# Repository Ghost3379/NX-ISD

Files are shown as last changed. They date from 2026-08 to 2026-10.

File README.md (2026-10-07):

# NX-ISD

## Overview
The **NX-ISD** is a custom, highly integrated wearable and embedded development board inspired by the Artemis Watch. It serves as the hardware foundation for the **ISD-Core** operating system.

<p align="center">
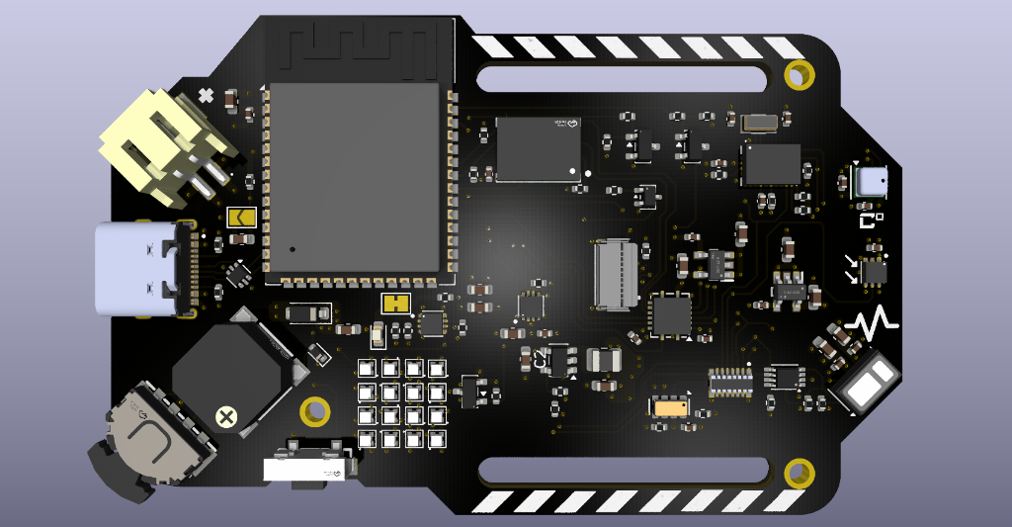
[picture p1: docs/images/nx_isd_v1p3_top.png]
NX-ISD v1p3 Top Component View
  
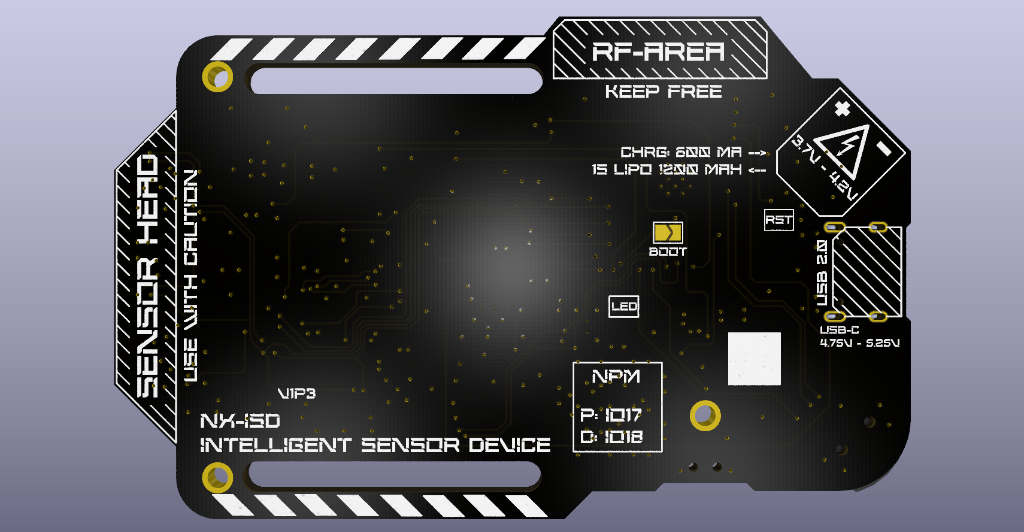
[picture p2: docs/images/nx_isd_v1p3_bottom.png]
NX-ISD v1p3 Bottom Silkscreen View
  
</p>
<p align="center">
  <em>NX-ISD Hardware Revision v1p3 (KiCad Raytraced 3D Render) — No Battery & No Display mounted</em>
</p>

## Naming & Structure

```text
N X - I S D
│     │
│     └─► Intelligent Sensor Device
│         (The hardware foundation)
│
└─► Prototyping Series
    (Always in development, not a closed product, open for everyone)

      │
      ▼
  ISD-Core
      │
      ├─► Custom Operating System (Dual-Core FreeRTOS based)
      ├─► Built on PlatformIO / Arduino Framework
      │
      ├──► NX-MSF: Mathematical Sensor Fusion (Physics Models & Kalman Filters)
      ├──► NX-AIS: Advanced Information System (Contextual Advisory Engine)
      └──► NX-SDS: Self-Diagnostic System (Hardware Integrity & Proof-Testing)
```

## Hardware Specifications

### Core & Storage
* **Microcontroller:** ESP32-S3 N16R8
* **Storage:** Additional Onboard NAND-SD (ZDSD02GLGEAG -> 2 Gbit = 250 MByte)

### Sensors
* **Motion/IMU:** BNO085 (9-DOF Motion Co-Processor)
* **Environment:** BME690 (Temperature, Humidity, Pressure, Gas)
* **Ambient Light:** OPT3001
* **Biometrics:** MAX30102 (Heart Rate / SpO2)
* **Timing:** RV-3028-C7 Real-Time Clock (RTC)

### Power Management
* **Charging:** USB-C (BQ25170 LiPo Charger, 1200mAh form factor)
* **Monitoring:** MAX17048 Fuel Gauge
* **Voltage Regulation:** Synchronous step-down buck converter (TLV62568, ~95% efficiency) for 3.3V system rail; dedicated low-noise LDOs (RT9193-18GB/28GB) for 1.8V and 2.8V sensor rails

### Peripherals & I/O
* **Display:** 10-Pin 0.5mm FPC connector for SPI displays
* **LEDs:** 16x WS2812B NeoPixel 4×4 Serpentine Matrix (XL-1010RGBC) with PMOS high-side power cutoff
* **Audio:** Onboard SMD Buzzer
* **Input:** Multi-Directional Lever-Switch and Push-Button

## Software & Core Systems
The board is programmed via **PlatformIO** (Arduino Framework) and is optimized to run the custom **ISD-Core** operating system. The software stack is composed of core modular subsystems:

* **[ISD-Core](ISD-Core/):** The dual-core FreeRTOS operating system handling task scheduling (Core 1 UI @ ~42Hz, Core 0 Sensors @ 50Hz/1Hz), thread-safe `SensorState` telemetry, 3D Cover Flow launcher, 360° radial dials, and smoothstep backlight transitions. See [`ISD-Core/README.md`](ISD-Core/README.md) for the software architecture and [`ISD-Core/MANUAL.md`](ISD-Core/MANUAL.md) for the complete user manual.
* **Persistent Storage Subsystem (`StorageManager`):** Manages non-volatile configuration storage on the onboard 2 Gbit ZDSD NAND Flash (`CS_SD = GPIO 47`). Stores a 64-byte packed binary struct (`/sys/config.bin`) with CRC-16 validation and a zero-wear save policy (writes occur only on user confirmation/exit, never while dialing).
* **Configuration Tooling (`tools/nx_config_tool.py`):** Standalone Python CLI utility to inspect, validate, dump to JSON, and compile binary config files offline for testing and flashing.
* **NX-MSF (Mathematical Sensor Fusion):** The analytical physics and math engine executing 1D Kalman filter variometer tracking, Magnus-Tetens dew point calculation, barometric storm gradients, RMSSD heart rate variability, and software energy accounting.
* **NX-AIS (Advanced Information System):** The autonomous on-device contextual advisor translating raw multi-sensor telemetry into proactive health, environmental, and tactical notifications.
* **NX-SDS (Self-Diagnostic System):** The internal hardware integrity and health assurance engine providing continuous I2C bus recovery, on-demand in-situ proof-testing, and predictive battery/sensor aging analytics.

## Documentation & Manuals
* **User & Navigation Manual:** [`ISD-Core/MANUAL.md`](ISD-Core/MANUAL.md) — Comprehensive guide covering physical controls, screen layouts, the 6 core application decks, 360° radial dials, and storage persistence.
* **Architecture & Hardware Guide:** [`ISD-Core/README.md`](ISD-Core/README.md) — Technical operating system internals, pin maps, and PlatformIO build instructions.
* **Hardware & PCB Specifications:** [`ISD-PCB/README.md`](ISD-PCB/README.md) — Revision v1p3 schematics, power budgets, layer stackup, and BOM.
* **Features & Math Modeling Roadmap:** [`FEATURE_LIST.md`](FEATURE_LIST.md) — Technical specifications, mathematical formulas, and implementation roadmap.
* **Software Roadmap & TODOs:** [`ISD-Core/SW-TODO.md`](ISD-Core/SW-TODO.md) — Core application deck progress and feature checklist.

## License
The software/firmware in the [ISD-Core] directory is licensed under the GNU General Public License v3.0 (GPLv3).

The hardware design files in the [ISD-PCB] directory are licensed under the CERN Open Hardware Licence Version 2 - Strongly Reciprocal (CERN-OHL-S).

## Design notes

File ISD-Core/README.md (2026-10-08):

# ISD-Core // Architecture, Stats & Developer Guide

Welcome to **ISD-Core**, the custom dual-core wearable operating system designed for the **NX-ISD** (Intelligent Sensor Device) powered by the ESP32-S3.

ISD-Core is built on a central design philosophy: **it is an intuitive, tactile smartwatch operating system—not a wearable spreadsheet of raw sensor dumps.** Mathematical sensor fusion (**NX-MSF**), autonomous contextual advisory (**NX-AIS**), and hardware self-diagnostics (**NX-SDS**) operate silently under the hood, distilling complex multi-sensor telemetry into high-value insights, glanceable widgets, and physical feedback.

The user interface draws inspiration from retro-futuristic amber vector displays (TVA, Pip-Boy, and aerospace instrumentation), rendered at **~42 FPS** on a 240×240 IPS display using zero-copy Octal PSRAM double-buffering.

> [!TIP]
> 📖 **Looking for the User & Screen Navigation Manual?**  
> For the visual guide, ASCII screen mockups, physical gesture timings, and application walkthroughs, see [**MANUAL.md**](MANUAL.md).

---

## Table of Contents
1. [Firmware Architecture & FreeRTOS Tasks](#1-firmware-architecture--freertos-tasks)
2. [Memory Architecture & Rendering Pipeline](#2-memory-architecture--rendering-pipeline)
3. [System Performance Stats & Engineering Metrics](#3-system-performance-stats--engineering-metrics)
4. [Hardware Bus Map & Centralized Pinout](#4-hardware-bus-map--centralized-pinout)
5. [Centralized I2C Bus Address Map](#5-centralized-i2c-bus-address-map)
6. [Persistent Storage Subsystem (`StorageManager`)](#6-persistent-storage-subsystem-storagemanager)
7. [Mathematical Models & Graphics Curves](#7-mathematical-models--graphics-curves)
8. [Building, Flashing & Development Workflow](#8-building-flashing--development-workflow)
9. [License](#9-license)

---

## 1. Firmware Architecture & FreeRTOS Tasks

ISD-Core leverages the asymmetric dual-core architecture of the ESP32-S3 (Xtensa LX7 @ 240 MHz) under FreeRTOS. UI rendering and high-frequency sensor acquisition are decoupled onto independent CPU cores to guarantee **zero frame drops** and **sub-microsecond input latching**:

```text
+-----------------------------------------------------------------------------+
|                                  ISD-Core                                   |
|                                                                             |
|  +-------------------------+          +----------------------------------+  |
|  |   Boot & Bring-Up       |          |         FreeRTOS Runtime         |  |
|  +-------------------------+          +----------------------------------+  |
|  | * Display & Backlight   |          |   CORE 1 (APP CPU)               |  |
|  | * Octal PSRAM Buffer    |          |   +--------------------------+   |  |
|  | * Staged Splashloader   |          |   | Non-Blocking UI (~42 Hz) |   |  |
|  | * Core 0 Sensor Task    |          |   | Watchface • 3D App Menu  |   |  |
|  | * StorageManager Probe  |          |   | StorageManager (Atomic)  |   |  |
|  +------------+------------+          |   +------------+-------------+   |  |
|               |                       |                | (Read <1 µs)    |  |
|               |                       |   +------------v-------------+   |  |
|               | Hand-off              |   |   Shared SensorState     |   |  |
|               | to Runtime            |   | (Mutex-Protected Bridge) |   |  |
|               |                       |   +------------^-------------+   |  |
|               |                       |                | (Write <1 µs)   |  |
|               |                       |   CORE 0 (PRO CPU)               |  |
|               |                       |   +--------------------------+   |  |
|               |                       |   | Fast Sensors (50 - 100Hz)|   |  |
|               |                       |   | BNO085 IMU • Compass     |   |  |
|               |                       |   | Slow Sensors (1 Hz)      |   |  |
|               |                       |   | BME690 • OPT3001 • MAX   |   |  |
|               |                       |   +--------------------------+   |  |
|               |                       +-----------------+----------------+  |
|               |                                         |                   |
|               +--------------------+--------------------+                   |
|                                    |                                        |
|                                    v                                        |
|  +-----------------------------------------------------------------------+  |
|  |                         Hardware Layer                                |  |
|  |  Sensors (I2C @ 400kHz): BNO085 • BME690 • OPT3001 • MAX17048 • RV3028|  |
|  |  Display (SPI @ 40MHz):  ST7789 IPS 240x240 (Double-Buffered PSRAM)  |  |
|  |  Storage (SPI @ 20MHz):  ZDSD NAND Flash (CS=47, /sys/config.bin)     |  |
|  |  Inputs (IRAM ISRs):     BTN (GP13) • LEVER L/P/R (GP16/15/14)        |  |
|  +-----------------------------------------------------------------------+  |
+-----------------------------------------------------------------------------+
```

### Core Assignment Breakdown

| Core | Task Name | Priority | Frequency | Responsibilities |
| :--- | :--- | :---: | :---: | :--- |
| **Core 1** | `vUITask` (Main Loop) | `1` | **~42 Hz** | LovyanGFX display rendering, 3D Cover Flow animation, Watchface HUD, radial dial physics, input event consumption, atomic NAND storage commit. |
| **Core 0** | `vFastSensorTask` | `5` | **50–100 Hz** | High-speed BNO085 9-DOF IMU rotation vector polling, step counting, compass heading calculation, wrist-flick gesture detection. |
| **Core 0** | `vSlowSensorTask` | `2` | **1 Hz** | Low-frequency I2C polling: BME690 (climate/gas), OPT3001 (lux), MAX17048 (fuel gauge), RV-3028 (RTC sync), USB VBUS sense. |
| **ISRs** | Hardware Edge ISRs | High (IRAM) | *Event* | Lever Left/Push/Right and Button falling-edge capture into thread-safe atomic latch bitmasks with 40 ms software debounce. |

### Inter-Process Communication (IPC)
Core 0 and Core 1 communicate through a centralized, thread-safe telemetry cache defined as `SensorState`:
* **Mutex Protection:** A FreeRTOS mutex (`xSensorMutex`) guards write transactions from Core 0 and read transactions from Core 1.
* **Exchange Latency:** Sensor snapshot acquisitions take $< 1\,\mu\text{s}$, preventing UI pipeline stalls.
* **Staleness Tracking:** Each telemetry group carries millisecond timestamps (`lastReadMs`) allowing the UI to flag stale sensor values gracefully.

---

## 2. Memory Architecture & Rendering Pipeline

The NX-ISD uses the **ESP32-S3-WROOM-1-N16R8** module configured with:
* **16 MB Quad SPI Flash** (firmware binary, assets, partition table).
* **8 MB Octal PSRAM** (`OPI_OPI` mode clocked at 80 MHz).

```text
0x3F800000 ┌────────────────────────────────────────────────────────┐
           │ Octal PSRAM Pool (8.0 MB Total)                        │
           │                                                        │
           │ ┌────────────────────────────────────────────────────┐ │
           │ │ Canvas 1: Primary DMA Framebuffer (240x240x16b)    │ │ ~115 kB
           │ ├────────────────────────────────────────────────────┤ │
           │ │ Canvas 2: Double-Buffer Sprite (240x240x16b)       │ │ ~115 kB
           │ ├────────────────────────────────────────────────────┤ │
           │ │ Dynamic Sprite Cache (Icons, Glyphs, Gauges)       │ │ ~256 kB
           │ ├────────────────────────────────────────────────────┤ │
           │ │ FreeRTOS Task Stacks & Dynamic Allocation Pool     │ │ ~7.5 MB
           │ └────────────────────────────────────────────────────┘ │
0x40000000 └────────────────────────────────────────────────────────┘
```

### Zero-Copy Double-Buffered Pipeline
1. **Back-Buffer Composition:** The active UI view draws vector primitives, anti-aliased arcs, and text directly onto an internal PSRAM-backed `LGFX_Sprite`.
2. **Push Transaction:** The sprite is pushed to the ST7789 display controller over the 40 MHz SPI bus (`SPI2_HOST`) in a single high-speed burst.
3. **Zero Tearing:** Eliminates screen flicker, partial draw artifacts, and rolling raster lines without requiring a hardware VSYNC pin.

---

## 3. System Performance Stats & Engineering Metrics

Key real-world operational benchmarks measured on hardware revision **v1p3**:

| Metric | Measured Value | Notes & Context |
| :--- | :---: | :--- |
| **Display Frame Rate** | **~42 FPS** | Continuous vector rendering on 240×240 IPS (23.8 ms frame budget) |
| **Frame Draw Time** | **18.2 ms** | PSRAM back-buffer render time on Core 1 |
| **SPI Display Throughput** | **40 MHz** | ~5.6 ms transfer time for 240×240 16-bit color frame |
| **Input Latch Latency** | **$< 1\,\mu\text{s}$** | Direct hardware IRAM interrupt edge capture |
| **Debounce Window** | **40 ms** | Software timing window rejecting switch release bounce |
| **Hold-to-Repeat Cycle** | **160 ms** | Fast numeric dialing after 475 ms initial hold |
| **Tactical Charge Duration**| **1200 ms** | Deliberate energy hold to enter 3D App Menu |
| **Backlight PWM Frequency** | **5.0 kHz** | High-frequency flicker-free dimming via N-MOSFET `Q4` |
| **Storage Config Struct** | **64 Bytes** | Cache-aligned packed binary record (`/sys/config.bin`) |
| **Dial NAND Write Count** | **0 Writes** | Turning radial dials modifies RAM only; 1,000 dial clicks = 0 writes |
| **NAND Commit Latency** | **~12 ms** | Atomic write (`config.tmp` $\to$ `config.bin`) with CRC-16 check |
| **System Idle Current** | **~15 mA** | Screen off, ESP32 light sleep, sensors idle |
| **Full Operational Current**| **~95–130 mA** | Display 60%, 4×4 matrix dynamic animation, BNO085 fusion active |

---

## 4. Hardware Bus Map & Centralized Pinout

Defined in [`ISD-Core/src/pins.h`](src/pins.h):

```text
                      ┌───────────────────────────┐
                      │    ST7789 IPS Display     │
                      │         (240x240)         │
                      └───────────────────────────┘
                                          [ BTN ] (GPIO 13) ── Back / Exit / Wake
                      ┌───────────────────────────┐
       [ LEVER LEFT ] │      [ LEVER PUSH ]       │ [ LEVER RIGHT ]
         (GPIO 16)    │        (GPIO 15)          │   (GPIO 14)
        Prev / Dec    │    Select / 1.2s Charge   │   Next / Inc
```

### Complete GPIO Pinout Matrix

| GPIO Pin | Pin Name | Direction | Electrical Domain | Connected Peripheral / Signal |
| :---: | :--- | :---: | :---: | :--- |
| **1** | `PWM_TFT` | Output | `+3V3` | Display Backlight PWM (gate of N-MOSFET `Q4`, active HIGH) |
| **2** | `INT_DOF` | Input | `+3V3` | BNO085 Motion Interrupt (active LOW) |
| **4** | `ALERT` | Input | `+3V3` | MAX17048 Fuel Gauge Alert (active LOW) |
| **5** | `INT_HR` | Input | `+1V8` | MAX30102 Optical Heart Rate Interrupt (active LOW) |
| **6** | `INT_RTC` | Input | `+3V3` | RV-3028 RTC Alarm / Periodic Timer (active LOW) |
| **8** | `I2C_SDA` | Bi-dir | `+3V3` | I2C Data Line (10k pull-up `R18` to `+3V3`) |
| **9** | `I2C_SCL` | Output | `+3V3` | I2C Clock Line (10k pull-up `R19` to `+3V3`) |
| **10** | `BUZZER` | Output | `+3V3` | Electromagnetic Buzzer PWM (gate of N-MOSFET `Q3`) |
| **11** | `BAT_STAT` | Input | `+3V3` | BQ25170 Charger Status (LOW = Charging, HIGH = Complete) |
| **12** | `USB_DETECT`| Input | `+3V3` | Resistor divider from USB 5V VBUS (HIGH when plugged in) |
| **13** | `BTN` | Input | `+3V3` | Main Tactile Push-Button (Active LOW, debounced) |
| **14** | `LEVER_RIGHT`| Input | `+3V3` | Navigation Lever Right (Active LOW, hardware-mirrored) |
| **15** | `LEVER_PUSH` | Input | `+3V3` | Navigation Lever Center Click (Active LOW) |
| **16** | `LEVER_LEFT` | Input | `+3V3` | Navigation Lever Left (Active LOW, hardware-mirrored) |
| **17** | `PWR_NPM` | Output | `+3V3` | NeoPixel Matrix Power Gate (HIGH = ON, LOW = 0µA cutoff) |
| **18** | `NPM` | Output | `VBAT` | WS2812B Serial Data Stream (800 kHz NZR) |
| **21** | `TFT_RS` | Output | `+2V8` | ST7789 Command / Data selection (via TXB0106) |
| **38** | `TFT_RST` | Output | `+2V8` | ST7789 Hardware Reset Line (active LOW) |
| **39** | `INT_ALS` | Input | `+3V3` | OPT3001 Light Sensor Threshold Interrupt (active LOW) |
| **40** | `SPI_SCK` | Output | `+3V3` | SPI Bus Serial Clock (shared between Display & Storage) |
| **41** | `SPI_MISO`| Input | `+3V3` | SPI Bus Data In (from ZDSD NAND Flash) |
| **42** | `SPI_MOSI`| Output | `+3V3` | SPI Bus Data Out (to Display & ZDSD NAND Flash) |
| **47** | `CS_SD` | Output | `+3V3` | ZDSD NAND Flash Chip Select (active LOW) |
| **48** | `CS_TFT` | Output | `+2V8` | ST7789 TFT Display Chip Select (active LOW) |

### SPI Bus Arbitration
The ST7789 IPS display controller and the ZDSD NAND Flash share `SPI2_HOST` (SCK 40, MISO 41, MOSI 42). To prevent display corruption during file I/O:
1. `StorageManager` explicitly drives `CS_TFT` (`GPIO 48`) **HIGH** (deselected) before asserting `CS_SD` (`GPIO 47`) **LOW**.
2. Display SPI transactions run at **40 MHz**; SD/NAND transactions run at **20 MHz**.
3. Upon completing a NAND write/read transaction, `CS_SD` is released **HIGH** before handing the bus back to LovyanGFX.

---

## 5. Centralized I2C Bus Address Map

The I2C bus (`Wire`) runs at **400 kHz Fast Mode**:
* **SDA:** `GPIO 8`
* **SCL:** `GPIO 9`

| Device | Part # | 7-Bit Address | Voltage Domain | HW Interrupt Line | Primary Function |
| :--- | :--- | :---: | :---: | :---: | :--- |
| **BNO085** | `U11` | **`0x4A`** *(alt `0x4B`)* | `+3V3` | `GPIO 2` (`!INT_DOF`, active LOW) | 9-DOF IMU, AR/VR fusion, 50 Hz compass, pedometer |
| **OPT3001** | `U10` | **`0x44`** / **`0x45`** | `+3V3` | `GPIO 39` (`!INT_ALS`, active LOW) | Precision photopic ambient light sensor (Lux) |
| **MAX17048** | `U6` | **`0x36`** | `+3V3` | `GPIO 4` (`!ALERT`, active LOW) | ModelGauge™ LiPo fuel gauge ($V_{\text{cell}}$, %, CRATE) |
| **RV-3028-C7** | `U12` | **`0x52`** | `+3V3` | `GPIO 6` (`!INT_RTC`, active LOW) | Extreme low-power RTC ($45\,\text{nA}$), hardware alarms |
| **MAX30102** | `U8` | **`0x57`** | `+1V8` *(via PCA9306 `U9`)* | `GPIO 5` (`!INT_HR`, active LOW) | Optical PPG biometric pulse & $SpO_2$ oximetry |
| **BME690** | `U7` | **`0x76`** *(alt `0x77`)* | `+3V3` | *Polled* | Temperature, Humidity, Barometer (hPa), MOX Gas ($R_{\text{gas}}$) |

---

## 6. Persistent Storage Subsystem (`StorageManager`)

Configuration parameters and user preferences persist on the onboard **ZDSD NAND Flash** (`CS_SD = GPIO 47`) in `/sys/config.bin`.

### Binary Struct Layout (`DeviceConfig`)
A cache-aligned **64-byte packed binary struct**:

```text
Offset  Field              Type      Size  Description
──────  ─────────────────  ────────  ────  ───────────────────────────────────────────
0x00    magic              uint16_t  2 B   Magic signature (0x584E = "NX" in ASCII)
0x02    version            uint8_t   1 B   Schema version (Current: 1)
0x03    size               uint8_t   1 B   Struct byte size (Current: 64)
0x04    crc16              uint16_t  2 B   CCITT CRC-16 (poly 0x1021, init 0xFFFF)
0x06    reservedHeader     uint16_t  2 B   Alignment padding
0x08    brightness         uint8_t   1 B   Display backlight brightness (10–100%)
0x09    autoDim            uint8_t   1 B   Ambient light compensation (0 = Off, 1 = On)
0x0A    tiltToWake         uint8_t   1 B   Tilt mode (0=Off, 1=Sens, 2=Bal, 3=Slug)
0x0B    screenTimeout      uint16_t  2 B   Timeout in seconds (0 = Never / Always On)
0x0D    wristCoverStandby  uint8_t   1 B   Cover gesture (0 = Off, 1 = On)
0x0E    fadeAnimMs         uint16_t  2 B   Backlight fade duration (0–2000 ms)
0x10    notifMethod        uint8_t   1 B   0=Silent, 1=All, 2=Sound, 3=Lights
0x11    matrixNotif        uint8_t   1 B   4x4 NeoPixel alert flash (0/1)
0x12    hrmReminder        uint8_t   1 B   0=Off, 1=30m, 2=1h, 3=2h
0x13    ecoMode            uint8_t   1 B   Power save throttle (0/1)
0x14    autoStandby        uint8_t   1 B   Auto screen sleep (0/1)
0x15    sensorSleep        uint8_t   1 B   Deep sleep sensors on standby (0/1)
0x16    buzzerEnabled      uint8_t   1 B   Master audio toggle (0/1)
0x17    buzzerVolume       uint8_t   1 B   Duty cycle intensity (10–100%)
0x18    buzzerTickDuration uint16_t  2 B   Pulse width (2–30 ms)
0x1A    buzzerTonePitch    uint16_t  2 B   Acoustic frequency (1600–4400 Hz)
0x1C    npmPower           uint8_t   1 B   NeoPixel PMOS gate (0/1)
0x1D    npmBrightness      uint8_t   1 B   Matrix brightness (10–100%)
0x1E    npmAnimation       uint8_t   1 B   Active pattern ID (0–5)
0x1F    aisEnabled         uint8_t   1 B   NX-AIS co-processor (0/1)
0x20    aisAdaptive        uint8_t   1 B   Adaptive context threshold (0/1)
0x21    aisDiagnostics     uint8_t   1 B   Diagnostics logging (0/1)
0x22    reservedBuffer     uint8_t   26 B  Zero-migration expansion buffer
0x3C    reservedBuffer     (cont.)   4 B   Pad to exactly 64 bytes total
```

### Zero-Wear Save Policy
1. **RAM-Only Dialing:** Turning radial dials modifies RAM variables and sets `isDirty = true`. Rotating a dial 10,000 times produces **0 disk writes**.
2. **Commit on `[PUSH]`:** Pressing the lever down to confirm a setting triggers an atomic write and resets `isDirty = false`.
3. **Commit on Exit:** Pressing `[BTN]` to back out of Settings flushes any dirty state once.
4. **Atomic Staging:** Data writes to `/sys/config.tmp` first. Once verified, it atomically renames to `/sys/config.bin`. If power cuts out mid-write, the existing `/sys/config.bin` remains uncorrupted.
5. **Fail-Safe Boot:** If the NAND storage is unformatted, corrupt, or CRC fails, `StorageManager` loads factory defaults immediately without crashing or blocking boot.

### Standalone PC Inspection Utility (`tools/nx_config_tool.py`)
A dedicated Python CLI tool allows inspecting, validating, editing, and compiling configuration binaries offline:

```bash
# Read and validate binary config:
python tools/nx_config_tool.py read config.bin

# Export binary configuration to human-readable JSON:
python tools/nx_config_tool.py to-json config.bin -o config.json

# Compile modified JSON back to binary with recalculated CRC-16:
python tools/nx_config_tool.py from-json config.json -o config.bin

# Generate fresh factory default binary config:
python tools/nx_config_tool.py create-default -o config.bin
```

---

## 7. Mathematical Models & Graphics Curves

### 1. Backlight Smoothstep Curve
Backlight fade transitions utilize a cubic Hermite **smoothstep curve** instead of a linear ramp:

$$f(t) = t^2 \times (3 - 2t) \quad \text{for } t \in [0, 1]$$

This produces zero first-derivative velocity at start and end ($f'(0) = f'(1) = 0$), mirroring natural human pupil dilation and eliminating harsh visual snapping.

### 2. 3D Cover Flow Trapezoidal Projection
Cards flanking the center hero card in the 3D App Menu are projected with geometric perspective scaling:

$$\text{scale} = \max\left(0.55, 1.0 - 0.45 \times \frac{|d|}{180}\right)$$

Flanking card vertical offsets use trapezoidal corner adjustments (`fillTriangle`) to produce true 3D spatial depth.

### 3. Spring-Damper Carousel Physics
The carousel scroll position snaps to the centered hero card using an underdamped spring-damper easing formula:

$$\text{pos}_{k+1} = \text{pos}_k + (\text{target} - \text{pos}_k) \times 0.48$$

This provides a fluid, mechanical feel that snaps securely into slot on lever release.

### 4. Real-Time 3D Vector Earth Engine
The Environment deck renders a live 3D rotating planetary sphere directly on Core 1 at 60 FPS without bitmap textures:
* **Planetary Projection:** Spherical latitude/longitude coordinates $(lat, lon)$ are rotated around Earth's $23.4^\circ$ tilted polar axis using Euler coordinate transformations:
  $$x_0 = \cos(lat) \sin(lon + \theta), \quad y_0 = \sin(lat), \quad z_0 = \cos(lat) \cos(lon + \theta)$$
  $$x = x_0 \cos(\alpha) - y_0 \sin(\alpha), \quad y = x_0 \sin(\alpha) + y_0 \cos(\alpha), \quad z = z_0$$
* **Hemispherical Depth Culling:** Only vertices and coastline edges with $z > 0$ are projected onto the ST7789 display, while backside polygons are culled.
* **Compact Footprint:** Continental coastlines are defined using compact `GeoNode` integer pairs ($< 1\,\text{kB}$ flash), executing in $< 30\,\mu\text{s}$ per frame on the ESP32-S3 hardware FPU.

---

## 8. Building, Flashing & Development Workflow

ISD-Core is compiled using **PlatformIO** targeting the ESP32-S3 with 16MB Flash and 8MB Octal PSRAM:

```bash
# 1. Clone repository
git clone https://github.com/Ghost3379/NX-ISD.git
cd NX-ISD/ISD-Core

# 2. Compile firmware
pio run

# 3. Upload to target board via USB CDC (COM9 / ttyACM0)
pio run --target upload

# 4. Open serial terminal monitor (115200 baud)
pio device monitor
```

### Compiler Configurations (`platformio.ini`)
* **Board:** `esp32-s3-devkitc-1`
* **PSRAM:** `board_build.arduino.memory_type = opi_opi`
* **Flash Mode:** `qio`, 80 MHz, 16 MB
* **Optimization:** `-O2`, `-DCORE_DEBUG_LEVEL=0`

---

## 9. License

The software in this directory is licensed under the **GNU General Public License v3.0 (GPLv3)**.  
The hardware design files in [`ISD-PCB`](../ISD-PCB) are licensed under the **CERN-OHL-S v2**.

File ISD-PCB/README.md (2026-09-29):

# NX-ISD Hardware Specification (Revision v1p3)

This directory contains the schematic design, PCB layout, fabrication outputs, and Bill of Materials (BOM) for the **NX-ISD** (Intelligent Sensor Device) wearable carrier board.

<p align="center">
  NX-ISD v1p3 Top View
  NX-ISD v1p3 Bottom View
</p>
<p align="center">
  <em>NX-ISD Hardware Revision v1p3 (KiCad Raytraced 3D Render)</em>
</p>

---

## 1. Board Specifications & Physical Dimensions

| Parameter | Specification | Notes |
| :--- | :--- | :--- |
| **Dimensions** | **77.00 mm × 48.60 mm** | Measured outer bounding box on `Edge.Cuts` |
| **Board Thickness** | **1.2 mm** | Standard FR-4 rigid substrate |
| **Layer Count** | **4 Layers** | Optimized signal integrity and solid reference planes |
| **Copper Weight** | 1 oz Outer (35 µm), 1 oz Inner | Standard manufacturing yield |
| **Surface Finish** | ENIG (Electroless Nickel Immersion Gold) | Recommended for fine-pitch BGA/QFN sensors |
| **Strap Mounts** | Dual integrated strap slots | Accommodates standard 20 mm – 22 mm watch straps |
| **Antenna Clearance** | Dedicated bottom keep-out zone | `RF-AREA KEEP FREE` silkscreen below ESP32-S3 trace |
| **Primary Connector** | 16-Pin Mid-Mount USB Type-C | USB 2.0 Full Speed + 5V 600mA charging |
| **Battery Header** | JST PH 2.0mm 2-Pin (`P1`) | Standard 1S LiPo (1200 mAh form factor) |

### 4-Layer PCB Stackup

```text
┌────────────────────────────────────────────────────────────────────────┐
│ Layer 1: Top (F.Cu)       High-density signal routing, IC pads, GND    │
├────────────────────────────────────────────────────────────────────────┤
│ Layer 2: Inner 1 (In1.Cu) Solid uninterrupted Ground Plane (GND)       │
├────────────────────────────────────────────────────────────────────────┤
│ Layer 3: Inner 2 (In2.Cu) Power Planes (+3V3, VBAT, +1V8, +2V8, VN)    │
├────────────────────────────────────────────────────────────────────────┤
│ Layer 4: Bottom (B.Cu)    Secondary routing, test pads, silkscreen art │
└────────────────────────────────────────────────────────────────────────┘
```

---

## 2. Power Architecture & Voltage Domains

```text
               ┌───────────────────────┐
  USB-C (5V) ─►│ BQ25170 Charger (U5)  ├──► VBAT (3.7V - 4.2V, 1S LiPo)
               │ (600mA, 10k NTC TH1)  │         │
               └───────────────────────┘         ├─► MAX17048 Fuel Gauge (U6)
                                                 │
  ┌──────────────────────────────────────────────┘
  │
  ├──► TLV62568 Buck Converter (U3) ──► +3V3 (System Rail, ~95% Efficiency)
  │    (2.2µH L1, 10µF filtering)         │
  │                                       ├─► ESP32-S3 Microcontroller (U13)
  │                                       ├─► BNO085 9-DOF IMU (U11)
  │                                       ├─► BME690 Environmental (U7)
  │                                       ├─► OPT3001 Ambient Light (U10)
  │                                       ├─► RV-3028-C7 RTC (U12)
  │                                       ├─► ZDSD02GLGEAG NAND Flash (U14)
  │                                       ├─► ST7789 Backlight PWM (via Q4)
  │                                       └─► Buzzer B1 (via Q3)
  │
  ├──► RT9193-18GB LDO (U1) ──────────► +1V8 (Ultra-Low-Noise Sensor Rail)
  │    (Ultra-Low Noise, 300mA)           └─► MAX30102 PPG / Biometrics (U8)
  │
  ├──► RT9193-28GB LDO (U4) ──────────► +2V8 (Display & Shifter Rail)
  │    (Low Noise, 300mA)                 ├─► ST7789 IPS Display Logic (J2)
  │                                       └─► TXB0106 Level Shifter (U15)
  │
  └──► AO3401A PMOS Gate (Q2) ────────► VN   (Switched VBAT Rail, 3.0V - 4.2V)
       (Driven by IO17 via BC847W Q1)     └─► 16x NeoPixel Matrix (G1..G16)
                                              [Guarantees 0µA standby draw]
```

### Voltage Rail Details

| Rail | Nominal Voltage | Regulator / Source | Max Current | Consumers |
| :--- | :--- | :--- | :--- | :--- |
| **`VBUS`** | 5.0 V (4.75–5.25V) | USB Type-C Receptacle (`J1`) | 1.5 A | BQ25170 Charger, USB detect divider |
| **`VBAT`** | 3.7 V (3.0–4.2V) | 1S LiPo via JST PH (`P1`) | 2.0 A peak | Buck converter, LDOs, Fuel Gauge, VN PMOS switch |
| **`+3V3`** | 3.3 V (±1.5%) | TLV62568DBV Synchronous Buck (`U3`)| 1.0 A | ESP32-S3, BNO085, BME690, OPT3001, RTC, NAND-SD, Backlight, Buzzer |
| **`+1V8`** | 1.8 V (±2.0%) | RT9193-18GB Low-Noise LDO (`U1`) | 300 mA | MAX30102 logic core, PCA9306 low-side |
| **`+2V8`** | 2.8 V (±2.0%) | RT9193-28GB Low-Noise LDO (`U4`) | 300 mA | ST7789 display VDD, TXB0106 B-port |
| **`VN`** | Switched `VBAT` | AO3401A High-Side PMOS (`Q2`) | 1.0 A | 16x XL-1010RGBC NeoPixels (0µA cutoff) |

---

## 3. Power Consumption Budget & Battery Calculation

Comprehensive current consumption analysis across operating states, accounting for conversion efficiencies and real-world loads:

### 1. Subsystem Current Breakdown

#### A. 16× NeoPixel RGB Matrix (`G1`–`G16`, on Switched `VN` / `VBAT`)
* **Driver Constant-Current Sink:** $5.0\,\text{mA}$ per color channel (R, G, B).
* **Per LED at 100% White:** $(3 \times 5.0\,\text{mA}) + 0.35\,\text{mA}$ (internal logic) $\approx \mathbf{15.35\,\text{mA}}$.
* **100% White Matrix Stress Test (16 LEDs):** $16 \times 15.35\,\text{mA} \approx \mathbf{245.6\,\text{mA}}$ (drawn directly from `VBAT` through PMOS `Q2`).
* **Dynamic Cyberpunk Animations (`CYBER RADAR`, `NEON TRACER`, etc.):** 2 to 5 active LEDs at 30–60% intensity $\approx \mathbf{15\text{ to }35\,\text{mA}}$ average.
* **Standby / Off State (`PWR_NPM` = LOW):** High-side PMOS `Q2` is gated off by pull-up $\implies \mathbf{0.00\,\mu\text{A}}$ (completely eliminates NeoPixel quiescent leakage).

#### B. ESP32-S3 Dual-Core Microcontroller (`U13`, on `+3V3`)
* **Active Wi-Fi TX (Max power + Dual-Core processing):** $\approx 240\text{ to }350\,\text{mA}$ (transient peaks up to $\approx 450\,\text{mA}$).
* **Active BLE Connected / Advertising:** $\approx 35\text{ to }55\,\text{mA}$.
* **Normal Dual-Core Processing (No RF, 240 MHz):** $\approx 40\text{ to }65\,\text{mA}$.
* **Frequency-Scaled Run (80 MHz / 160 MHz):** $\approx 20\text{ to }35\,\text{mA}$.
* **FreeRTOS Light-Sleep (Between 50Hz/1Hz sensor ticks):** $\approx 1.5\text{ to }3.0\,\text{mA}$.
* **Deep-Sleep (ULP / RTC wake only):** $\approx 15\text{ to }25\,\mu\text{A}$.

#### C. ST7789 IPS Display (`J2`, on `+3V3` & `+2V8`)
* **Backlight LEDs (via `+3V3` switched by N-MOSFET `Q4`):**
  * 100% Brightness: $\approx 35\text{ to }45\,\text{mA}$.
  * 40% Indoor Brightness: $\approx 15\text{ to }20\,\text{mA}$.
* **Display Controller Logic (via `+2V8` LDO `U4`):** $\approx 5\text{ to }10\,\text{mA}$.
* **Display Sleep Mode (`SLPIN` command):** $< 20\,\mu\text{A}$.
* **Total Display Active:** $\approx 20\text{ to }55\,\text{mA}$.

#### D. Sensors, Audio & Storage Peripherals
* **MAX30102 Biometrics (`U8`, on `+1V8` LDO `U1`):**
  * Time-averaged optical pulse current (Red + IR LEDs @ 50–100 Hz): $\approx 10\text{ to }18\,\text{mA}$ (peaks of $50\,\text{mA}$ during $400\,\mu\text{s}$ pulses).
  * Standby / Shutdown: $< 1\,\mu\text{A}$.
* **BNO085 9-DOF IMU (`U11`, on `+3V3`):**
  * Active 9-axis sensor fusion (internal ARM Cortex-M0+ running at 100 Hz): $\approx 15\text{ to }18\,\text{mA}$.
  * Low-power tap / step-detector only: $\approx 0.8\text{ to }1.5\,\text{mA}$.
* **BME690 Environmental (`U7`, on `+3V3`):**
  * Base climate sampling (T/P/H): $< 1\,\text{mA}$.
  * MOX Gas Heater Pulse (heats to $320^\circ\text{C}$ for $\approx 30\,\text{ms}$): $\mathbf{+12\text{ to }14\,\text{mA}}$ transient burst.
* **B1 Electromagnetic Buzzer (`B1`, on `+3V3` via `Q3`):**
  * $16\,\Omega$ coil impedance at $3.3\,\text{V}$: Peak current $\approx 206\,\text{mA}$.
  * 50% PWM Duty Cycle acoustic tone: $\approx \mathbf{80\text{ to }100\,\text{mA}}$ average (only when sounding alert/alarm).
* **ZDSD02GLGEAG SPI NAND Flash (`U14`, on `+3V3`):**
  * Standby: $\approx 10\,\mu\text{A}$.
  * High-speed SPI Read/Write bursts: $\approx 15\text{ to }25\,\text{mA}$.
* **OPT3001 Ambient Light (`U10`, on `+3V3`):** $\approx 2\text{ to }4\,\mu\text{A}$ (quiescent).
* **RV-3028-C7 RTC (`U12`, on `+3V3`):** $\approx 45\,\text{nA}$ (running continuously).
* **LDO Quiescent Currents (`U1`, `U4`):** $\approx 90\,\mu\text{A}$ each.

---

### 2. Supply Rail Power Budget & Buck Efficiency

#### `+3V3` System Rail (TLV62568 Synchronous Buck `U3`):
* **Normal Operation (Display on, sensors active, Wi-Fi off):** $\approx 80\text{ to }130\,\text{mA}$.
* **Full Load (Wi-Fi TX active, display 100%, all sensors active, BME690 heater):** $\approx \mathbf{320\text{ to }460\,\text{mA}}$.
* **Absolute Worst-Case Transient (+ Buzzer beeping):** $\approx 550\text{ to }640\,\text{mA}$.
* **Regulator Headroom:** TLV62568 is rated for **$1.0\,\text{A}$** continuous current $\implies$ **$> 35\%\text{--}50\%$ thermal and electrical safety margin** under simultaneous peak load.

#### Effective Battery Draw (from 1S LiPo, $V_{\text{BAT}} \approx 3.7\,\text{V}$):
The TLV62568 buck operates at $\approx 90\text{--}95\%$ efficiency ($\eta$):
$$P_{\text{in}} = \frac{V_{\text{out}} \times I_{\text{out}}}{\eta} \implies I_{\text{BAT,buck}} \approx \frac{3.3\,\text{V} \times I_{\text{3V3}}}{3.7\,\text{V} \times 0.92} \approx 0.97 \times I_{\text{3V3}}$$

* **Buck Current from Battery:** $\approx 310\text{ to }445\,\text{mA}$ (during Wi-Fi TX).
* **Matrix Current from Battery:** $\approx 245\,\text{mA}$ (100% white stress test).
* **LDOs from Battery (+1V8 and +2V8):** $\approx 15\text{ to }25\,\text{mA}$.
* **Total Battery Current at 100% Synthetic Stress Test:** $\mathbf{\approx 570\text{ to }715\,\text{mA}}$ (short peaks up to $\approx 780\,\text{mA}$ with buzzer).
* **Battery Health Assessment:** On a **1200 mAh 1S LiPo**, $715\,\text{mA}$ represents a discharge rate of only $\approx \mathbf{0.6\text{ C}}$ (standard 1S LiPo cells tolerate $1.0\text{ C}$ continuous / $2.0\text{ C}$ pulse), ensuring zero risk of excessive cell heating or premature degradation.

---

### 3. Realistic Operating Profiles & Expected Battery Life (1200 mAh LiPo)

| Profile | Description / Active Subsystems | Average Battery Current | Estimated Runtime |
| :--- | :--- | :--- | :--- |
| **Profile 1: Synthetic Stress Test** | 100% White Matrix, Wi-Fi TX active, Display 100%, all sensors | $\approx 650\,\text{mA}$ | **$\approx 1.8\text{ Hours}$** |
| **Profile 2: Continuous "Cyberpunk" Active** | Display 60% (~18mA), 4×4 Matrix dynamic animation (~25mA), BNO085 fusion, PPG pulse, BLE advertising | $\approx 95\text{ to }130\,\text{mA}$ | **$\approx 9\text{ to }12.5\text{ Hours}$** (Continuous screen-on) |
| **Profile 3: Daily Smartwatch Wear** | Display auto-off after 10s, Matrix off, Raise-to-wake active (BNO085), background pedometer & climate logging, periodic BLE sync | $\approx 15\text{ to }25\,\text{mA}$ | **$\approx 48\text{ to }80\text{ Hours}$** (2 to 3.5 Days) |
| **Profile 4: Low-Power Standby / Sleep** | Screen & Matrix off ($0\,\mu\text{A}$), ESP32 light-sleep, RTC active, low-power sensor interrupt monitoring | $\approx 2.0\text{ to }3.5\,\text{mA}$ | **$\approx 340\text{ to }600\text{ Hours}$** (14 to 25 Days) |
| **Profile 5: Shelf Storage (Deep-Sleep)** | Display unpowered, Matrix unpowered, ESP32 deep-sleep, RV-3028 RTC running | $< 35\,\mu\text{A}$ | **$> 3\text{ Years}$** |

---

## 4. Primary Component & IC Roster

| Designator | Component | Package | Function | LCSC Part # |
| :--- | :--- | :--- | :--- | :--- |
| **U13** | **ESP32-S3-WROOM-1-N16R8** | Module (18×25.5 mm) | Dual-Core 240MHz MCU, 16MB Flash, 8MB PSRAM | Direct / Espressif |
| **U3** | **TLV62568DBV** | SOT-23-5 | Synchronous Step-Down DC-DC Buck Converter (+3V3) | C967888 |
| **U5** | **BQ25170DSGR** | WSON-8 (2×2 mm) | 800mA Linear LiPo Charger with 10k NTC sensing | C2837330 |
| **U6** | **MAX17048G_T10** | TDFN-8 (2×2 mm) | ModelGauge™ LiPo Fuel Gauge with ALERT output | C2682619 |
| **U1** | **RT9193-18GB** | SOT-23-5 | 300mA Ultra-Low-Noise LDO (+1.8V Sensor Rail) | C27416 |
| **U4** | **RT9193-28GB** | SOT-23-5 | 300mA Low-Noise LDO (+2.8V Display Rail) | C56731 |
| **U11** | **BNO085** | LGA-28 (5.2×3.8 mm) | 9-DOF Motion Co-Processor (AR/VR IMU fusion) | Direct / CEVA |
| **U7** | **BME690** | LGA-8 (3×3 mm) | Temperature, Relative Humidity, Pressure, Gas MOX | Direct / Bosch |
| **U8** | **MAX30102** | OLGA-14 (3.3×5.6 mm) | Pulse Oximetry ($SpO_2$) & Heart Rate Optical Sensor | C83038 |
| **U10** | **OPT3001DNPR** | USON-6 (2×2 mm) | Precision Ambient Light Sensor (Photopic curve) | C113886 |
| **U12** | **RV-3028-C7** | SON-8 (1.5×3.2 mm) | Real-Time Clock, Ultra-Low Power, Factory Calibrated | C2838382 |
| **U14** | **ZDSD02GLGEAG** | LGA-8 (8×6 mm) | 2 Gbit (250 MByte) High-Speed SPI NAND Flash | C2875853 |
| **U9** | **PCA9306DCKR** | VSSOP-8 | Dual Bidirectional I2C Voltage-Level Translator | C7570 |
| **U15** | **TXB0106RGYR** | VQFN-16 (2.5×2.0 mm)| 6-Bit Bidirectional Voltage-Level Shifter for Display| C7213 |
| **U2** | **USBLC6-2P6** | SOT-666 | Ultra-Low Capacitance Rail-to-Rail ESD Protection | C7519 |
| **G1..G16**| **XL-1010RGBC-WS2812B** | 1010 SMD (1×1 mm) | 16x NeoPixel Serpentine 4×4 RGB Matrix | C5349953 |
| **U16** | **TM-2025A** | SMD Multi-Way | Multi-Directional Navigation Lever-Switch | C318949 |
| **S1** | **TS-1101VS-C-A-A** | SMD Button | Tactile Push Button (Main user interaction) | C318884 |
| **B1** | **SMD-8503-3627-16Ω** | SMD (8.5×8.5 mm) | Electromagnetic Buzzer for acoustic notifications | C2685545 |
| **J1** | **UJ20-C-H-G-SMT-1-P16**| 16-Pin Mid-Mount | USB Type-C Receptacle with CC1/CC2 5.1k resistors | C2765186 |
| **J2** | **TE 1-2328702-0** | 10-Pin 0.5mm FPC | Dual-contact back-flip FPC connector for ST7789 | C2837335 |
| **P1** | **JST S2B-PH-SM4-TB** | 2-Pin SMT PH 2.0mm | Polarized LiPo battery connection header | C2875850 |

---

## 5. Hardware Interfaces & Address Map

### I2C Bus (`Wire`, 400 kHz Fast Mode)
* **SDA:** `GPIO 8` (10k pull-up to `+3V3`)
* **SCL:** `GPIO 9` (10k pull-up to `+3V3`)

| Device | Designator | 7-Bit Address | Voltage Domain | Hardware Interrupt Line |
| :--- | :--- | :--- | :--- | :--- |
| **BNO085** | `U11` | `0x4A` | `+3V3` | `GPIO 2` (`!INT_DOF`, active LOW) |
| **MAX30102** | `U8` | `0x57` | `+1V8` (via PCA9306 `U9`) | `GPIO 5` (`!INT_HR`, active LOW) |
| **BME690** | `U7` | `0x76` | `+3V3` | Polled |
| **OPT3001** | `U10` | `0x45` | `+3V3` | `GPIO 39` (`!INT_ALS`, active LOW) |
| **MAX17048** | `U6` | `0x36` | `+3V3` | `GPIO 4` (`!ALERT`, active LOW) |
| **RV-3028-C7**| `U12` | `0x52` | `+3V3` | `GPIO 6` (`!INT_RTC`, active LOW) |

### High-Speed SPI Bus (HSPI, up to 40 MHz)
* **SCK:** `GPIO 40`
* **MOSI:** `GPIO 42`
* **MISO:** `GPIO 41`

| Peripheral | Designator | Chip Select (CS) | Additional Control Lines | Notes |
| :--- | :--- | :--- | :--- | :--- |
| **ST7789 TFT** | `J2` | `GPIO 48` (`CS_TFT`) | `GPIO 21` (`DC`/`RS`)<br>`GPIO 38` (`RST`)<br>`GPIO 1` (`PWM_TFT`) | 240×240 IPS Panel, PWM backlight via Q4 |
| **NAND-SD Flash** | `U14` | `GPIO 47` (`CS_SD`) | Shared SCK/MOSI/MISO | 2 Gbit (250 MB) storage for logs/certs |

---

## 6. Complete GPIO Pinout Matrix

Centralized in [`ISD-Core/src/pins.h`](../ISD-Core/src/pins.h):

| GPIO Pin | Pin Name | Peripheral / Signal | Direction | Electrical Notes |
| :--- | :--- | :--- | :--- | :--- |
| **GPIO 1** | `PWM_TFT` | Display Backlight PWM | Output | Drives gate of N-MOSFET `Q4` (active HIGH) |
| **GPIO 2** | `INT_DOF` | BNO085 Motion Interrupt | Input | Active LOW interrupt from IMU |
| **GPIO 4** | `ALERT` | Fuel Gauge Alert | Input | Active LOW interrupt (internal pull-up enabled) |
| **GPIO 5** | `INT_HR` | MAX30102 PPG Interrupt | Input | Active LOW biometric sample-ready interrupt |
| **GPIO 6** | `INT_RTC` | RV-3028 RTC Alarm/Timer | Input | Active LOW periodic/alarm interrupt |
| **GPIO 8** | `I2C_SDA` | I2C Data Line | Bi-directional | 10k hardware pull-up to `+3V3` (`R18`) |
| **GPIO 9** | `I2C_SCL` | I2C Clock Line | Output | 10k hardware pull-up to `+3V3` (`R19`) |
| **GPIO 10** | `BUZZER` | Electromagnetic Buzzer | Output | Drives gate of N-MOSFET `Q3` (PWM tone output) |
| **GPIO 11** | `BAT_STAT` | BQ25170 Charger Status | Input | LOW = Charging, HIGH/Hi-Z = Charge Complete |
| **GPIO 12** | `USB_DETECT`| USB 5V VBUS Presence | Input | Resistor divider from VBUS (HIGH when plugged in) |
| **GPIO 13** | `BTN` | Main Tactile Push-Button | Input | Active LOW (external pull-up, debounced) |
| **GPIO 14** | `LEVER_RIGHT`| Navigation Lever Right | Input | Active LOW (Mirrored to GPIO 14 due to 180° U16 footprint assembly orientation on v1p3) |
| **GPIO 15** | `LEVER_PUSH` | Navigation Lever Center | Input | Active LOW (internal pull-up enabled) |
| **GPIO 16** | `LEVER_LEFT` | Navigation Lever Left | Input | Active LOW (Mirrored to GPIO 16 due to 180° U16 footprint assembly orientation on v1p3) |
| **GPIO 17** | `PWR_NPM` | NeoPixel Matrix Power Gate | Output | HIGH = Turns ON PMOS `Q2`; LOW = 0µA cutoff |
| **GPIO 18** | `NPM` | NeoPixel Serial Data | Output | 800 kHz single-wire NZR stream to `G1` |
| **GPIO 21** | `TFT_RS` | Display Command / Data | Output | LOW = Command, HIGH = Data (via TXB0106) |
| **GPIO 38** | `TFT_RST` | Display Hardware Reset | Output | Active LOW hardware reset line |
| **GPIO 39** | `INT_ALS` | OPT3001 Light Interrupt | Input | Active LOW optical threshold interrupt |
| **GPIO 40** | `SPI_SCK` | SPI Bus Serial Clock | Output | Up to 40 MHz clock |
| **GPIO 41** | `SPI_MISO`| SPI Bus Data In (MISO) | Input | High-speed data input from NAND flash |
| **GPIO 42** | `SPI_MOSI`| SPI Bus Data Out (MOSI) | Output | High-speed data output to Display & NAND |
| **GPIO 47** | `CS_SD` | NAND Flash Chip Select | Output | Active LOW chip select |
| **GPIO 48** | `CS_TFT` | TFT Display Chip Select | Output | Active LOW chip select |

---

## 7. Manufacturing & Assembly Resources

* **Production Package:** [`ISD-PCB/NX-ISD/production/NX-ISD_v1p3.zip`](NX-ISD/production/NX-ISD_v1p3.zip) (Contains RS-274X Gerbers and Excellon drill files ready for JLCPCB / PCBWay).
* **Interactive HTML BOM:** [`ISD-PCB/NX-ISD/bom/ibom.html`](NX-ISD/bom/ibom.html) (Searchable, interactive visual assembly tool showing component locations per reference designator).
* **Component Placement / CPL:** [`ISD-PCB/NX-ISD/production/NX-ISD_v1p3_positions.csv`](NX-ISD/production/NX-ISD_v1p3_positions.csv)
* **Production BOM:** [`ISD-PCB/NX-ISD/production/NX-ISD_v1p3_bom.csv`](NX-ISD/production/NX-ISD_v1p3_bom.csv)
* **Schematic PDF:** [`docs/circuit diagrams/NX-ISD_v1p3.pdf`](../docs/circuit%20diagrams/NX-ISD_v1p3.pdf)

### 7.1 Hardware Assembly Errata & Notes (Revision v1p3)

> [!NOTE]
> **Switch U16 Physical Orientation (`TM-2025A`):**
> On the physical v1p3 carrier board assembly, switch `U16` is mounted rotated 180° relative to the original schematic layout:
> - **Left / Right Mirroring:** Moving the lever physically to the Left triggers `GPIO 16`, while moving to the Right triggers `GPIO 14`. Firmware in [`ISD-Core/src/pins.h`](../ISD-Core/src/pins.h) maps `#define LEVER_LEFT 16` and `#define LEVER_RIGHT 14` to ensure natural 1:1 user interaction.
> - **Common & Push Contacts:** Common and Push contacts were inverted on early board rework.
> - **Action Item for Revision v1p4:** Rotate `U16` footprint 180° or re-route traces on `Logic Section` to align schematic nets 1:1 with physical placement.

---

## 8. Hardware Licensing

The hardware design files in this directory are licensed under the **CERN Open Hardware Licence Version 2 - Strongly Reciprocal (CERN-OHL-S)**. See the root `LICENSE` file for full terms and conditions.

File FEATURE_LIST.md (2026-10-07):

# NX-ISD — Feature & Mathematical Modeling Roadmap (TODO)

This document tracks planned, in-progress, and completed software features, algorithms, and mathematical models for the **NX-ISD** wearable watch running **ISD-Core**.

---

## 1. NX-MSF — Mathematical Sensor Fusion

Inspired by high-precision industrial metrology and physics modeling, **NX-MSF** derives rich multi-variable insights by mathematically fusing the onboard sensors rather than requiring extra dedicated physical hardware:

### [ ] Software Energy Accounting & Power Estimation
* **Sensors Involved:** FreeRTOS State Machine + MAX17048 Fuel Gauge + RV-3028 RTC.
* **Principle:** Microsecond-accurate tracking of hardware peripheral active time:
  $$\text{Energy}_{\text{total}} = \sum \left( I_{\text{subsystem}} \times \Delta t \right)$$
* **Subsystems Modeled:**
  * CPU: Active (240MHz) vs. Modem Sleep vs. Light/Deep Sleep ($<0.1\,\text{mA}$).
  * Display: Backlight PWM duty cycle ($0\,\text{mA}$ to $\approx 35\,\text{mA}$).
  * 4×4 NeoPixels: Active power domain (`PWR_NPM`) + LED count and brightness.
  * Sensors: MAX30102 active pulse measurement ($\approx 15\,\text{mA}$) vs. idle.
* **Auto-Calibration:** Closed-loop drift correction every 1% battery drop reported by the MAX17048 ($\approx 12\,\text{mAh}$ on a 1200mAh cell).
* **User Feature:** Apple Watch-style battery breakdown screen (*Display: 45%, Sensors: 25%, Glyphs: 18%, System: 12%*).

---

### [ ] Hypsometric Sub-Meter Altitude & Variometer
* **Sensors Involved:** BME690 (Barometer) + BNO085 (9-DOF Accelerometer).
* **Principle:** 
  * Barometric hypsometric equation gives absolute altitude:
    $$h = 44330 \times \left(1 - \left(\frac{P}{P_0}\right)^{\frac{1}{5.255}}\right)$$
  * Fuse with BNO085 vertical linear acceleration ($a_z$) via a 1D Kalman Filter.
* **User Feature:**
  * Zero-lag instantaneous vertical velocity (Variometer in $\text{m/s}$).
  * Real-time floor/stair counting and elevator detection without standard barometric delay.

---

### [ ] Weather Predictor, Dew Point & Absolute Humidity
* **Sensors Involved:** BME690 (Temperature, Humidity, Pressure).
* **Principle:**
  * **Dew Point ($T_{\text{dew}}$):** Magnus-Tetens formula:
    $$\gamma(T, RH) = \frac{17.27 \cdot T}{237.7 + T} + \ln\left(\frac{RH}{100}\right) \implies T_{\text{dew}} = \frac{237.7 \cdot \gamma}{17.27 - \gamma}$$
  * **Absolute Humidity:** Moisture density in grams per cubic meter ($g/\text{m}^3$).
  * **Heat Index / Humidex:** Thermal comfort index combining temperature and humidity.
  * **Storm Predictor:** Rolling $\Delta P / \Delta t$ pressure gradient over 3 hours. Warns if pressure drops $> 2.5\,\text{hPa} / 3\text{h}$ before rain hits.

---

### [ ] Autonomic Stress Index & Heart Rate Variability (HRV)
* **Sensors Involved:** MAX30102 (Optical PPG) + RV-3028 (RTC).
* **Principle:** 
  * Microsecond timestamping of peak-to-peak Inter-Beat Intervals ($IBI$ / $R\text{-}R$ intervals).
  * Calculate RMSSD (Root Mean Square of Successive Differences):
    $$\text{RMSSD} = \sqrt{\frac{1}{N-1} \sum_{i=1}^{N-1} (IBI_{i+1} - IBI_i)^2}$$
* **User Feature:**
  * Real-time Autonomic Stress Score ($0\text{--}100$).
  * Sympathetic vs. Parasympathetic balance indicator.

---

### [ ] Motion-Artifact Cancellation for Biometrics
* **Sensors Involved:** MAX30102 (PPG) + BNO085 (3D Accelerometer).
* **Principle:** Adaptive frequency filter using 3D acceleration vectors to isolate and cancel out wrist tremor, finger movement, and walking shockwaves from the optical reflection channels.
* **User Feature:** Clean, stable pulse measurements even when moving.

---

### [ ] Multi-Factor Active Calorie Burn
* **Sensors Involved:** BNO085 (Kinetic Intensity) + MAX30102 (Heart Rate) + BME690 (Ambient Temp).
* **Principle:** Combines root-mean-square kinetic acceleration $J = \sqrt{a_x^2 + a_y^2 + a_z^2}$ with heart rate reserve elevation above baseline and ambient thermal stress.
* **User Feature:** Accurate Active Metabolic Rate (AMR $\text{kCal}$) beyond simple step counting.

---

### [ ] Circadian Daylight Dose & Night Shield
* **Sensors Involved:** OPT3001 (Human-Eye Photopic Lux) + RV-3028 (RTC).
* **Principle:** Integrates photopic lux across daytime hours: $\int \text{Lux}(t)\,dt$.
* **User Feature:**
  * Morning circadian light sufficiency check.
  * Late-night blue light / glare warning and automatic display/glyph dimming.

---

### [ ] Kinematic Wrist-Wake Gesture
* **Sensors Involved:** BNO085 (Rotation Vector & Angular Velocity).
* **Principle:** Detects inward wrist roll rotation ($\Delta \theta_{\text{roll}} > 45^\circ$, $\omega_{\text{roll}} > 1.2\,\text{rad/s}$) towards the eye vector.
* **User Feature:** Instantly turns on display only when looking at the watch; conserves battery when arm swings during walking.

---

## 2. NX-AIS — Advanced Information System (Contextual AI Engine)

**NX-AIS** is an autonomous, on-device contextual advisory engine running as an intelligent background supervisor. Rather than overwhelming the user with raw sensor numbers, NX-AIS continuously evaluates multi-sensor streams against physiological and environmental models to deliver proactive, human-centric advice and Glyph notifications.

> [!NOTE]
> **Toggleable System Architecture:** NX-AIS can be completely enabled, disabled, or configured to "Subtle Mode" (Glyphs only, no screen popups) in the `ISD-Core` System Settings to suit user preference.

### Contextual Advisory Modules:
1. **Hydration & Thermal Strain Guard:**
   * *Sensors:* BME690 ($T, RH$, Humidex) + BNO085 (Activity state) + RV-3028 (Timer).
   * *Trigger:* Ambient temperature $> 28^\circ\text{C}$ or high heat index sustained for $> 60\,\text{min}$, or elevated physical exertion under warmth.
   * *Action:* Soft buzzer chime + blue droplet ripple on 4×4 matrix + notification: *"Thermal load elevated. Remember to drink water!"*

2. **Alpine & High-Altitude Hiking Sentinel:**
   * *Sensors:* BME690 (Barometric Pressure / Hypsometric Altitude) + BNO085 (Ascent Rate) + MAX30102 ($SpO_2$ & Pulse) + RV-3028.
   * *Trigger:* Altitude $> 1800\,\text{m}$ combined with low dry humidity ($RH < 35\%$), or rapid vertical ascent rate $> 400\,\text{m/h}$.
   * *Action:* Mountain contour glyph on 4×4 matrix + alerts:
     * *Hydration:* *"Altitude 2,200m (Thin/Dry Air). Respiratory water loss doubled. Increase fluid intake."*
     * *Pacing:* *"Rapid ascent (+480m/h). Slow down pacing to prevent altitude sickness / fatigue."*

3. **Mountain Fog & Condensation Predictor:**
   * *Sensors:* BME690 ($T, RH, P \to T_{\text{dew}}$ Magnus-Tetens).
   * *Trigger:* Ambient temperature approaches dew point ($T - T_{\text{dew}} \le 1.0^\circ\text{C}$) with $RH > 90\%$ while hiking.
   * *Action:* White fog glyph on matrix + *"Dew point convergence. Dense fog or cloud immersion imminent. Check trail markers."*

4. **Indoor Air Quality & Ventilation Sentinel:**
   * *Sensors:* BME690 (Gas Resistance $R_{\text{gas}}$, VOCs, $eCO_2$).
   * *Trigger:* Air quality degradation detected indoors while user is sedentary for $> 30\,\text{min}$.
   * *Action:* Amber Glyph beacon + *"Indoor air quality declining. Consider opening a window."*

5. **Pre-Storm Meteorological Warning:**
   * *Sensors:* BME690 (Barometer).
   * *Trigger:* Barometric pressure drop $> 2.5\,\text{hPa}$ over a rolling 3-hour window.
   * *Action:* Tactical radar glyph flash + *"Rapid barometric drop (-X hPa). Rain or storm likely within 1-2h."*

6. **Alpine Solar & Snow Glare Guard:**
   * *Sensors:* OPT3001 (Photopic Human-Eye Lux) + BME690 (Altitude).
   * *Trigger:* Sustained extreme visible brightness $> 65{,}000\,\text{Lux}$ (common in high-altitude snowfields/glaciers due to high albedo reflection).
   * *Action:* Sunburst glyph + *"Extreme alpine glare detected (>65k Lux). Glare protection / sunglasses advised."*

7. **Circadian Daylight & Sleep Hygiene Coach:**
   * *Sensors:* OPT3001 (Photopic Lux) + RV-3028 (RTC Clock).
   * *Trigger:* Low daytime exposure ($< 200\,\text{Lux}$) before 1:00 PM, or harsh blue glare ($> 500\,\text{Lux}$) past 10:00 PM.
   * *Action:* Morning alert: *"Low daylight exposure today. Step outside for 10 min to support circadian rhythm."* / Night alert: *"Enabling Night Shield dimming."*

8. **Cold-Weather LiPo Battery Advisor:**
   * *Sensors:* BME690 ($T_{\text{ambient}}$) + MAX17048 ($V_{\text{cell}}$, Discharge Rate).
   * *Trigger:* Ambient temperature $< 4^\circ\text{C}$ causing electrolyte impedance rise and temporary voltage sag.
   * *Action:* Snowflake glyph + *"Low ambient temp (3°C). LiPo capacity temporarily reduced. Keep watch insulated under sleeve."*

9. **Autonomic Stress & Breathing Guide:**
   * *Sensors:* MAX30102 (PPG $R\text{-}R$ intervals) + BNO085 (Stationary confirmation).
   * *Trigger:* Heart Rate elevated above resting baseline accompanied by suppressed HRV (RMSSD stress spike) while completely stationary.
   * *Action:* 4×4 NeoPixel matrix automatically engages the `GLYPH BREATH` animation at a relaxing 4-second inhale / 4-second exhale pace + *"High physiological tension. Take a 60s breathing break."*

10. **Combustion Smoke & Pyrolysis Hazard Sentinel:**
    * *Sensors:* BME690 (MOX Gas Resistance $R_{\text{gas}}$ + Temperature $\Delta T / \Delta t$).
    * *Principle:* Combustion byproducts (wood smoke, melting wire insulation, flux fumes, carbon monoxide) flood the heated metal-oxide plate with reducing gases, causing an immediate, catastrophic drop in gas resistance ($R_{\text{gas}}$ drops $> 75\%$ from baseline within seconds) often paired with an ambient thermal surge.
    * *Trigger:* $\frac{R_{\text{gas}}}{R_{\text{baseline}}} < 0.25$ within 30 seconds, or concurrent $\Delta T > +3.0^\circ\text{C}$ spike.
    * *Action:* Urgent audible buzzer warble + pulsing crimson hazard glyph on 4×4 matrix + critical notification: *"CRITICAL: Smoke / Combustion gas spike detected! Inspect room/workbench safety."*

11. **Sedentary / Posture Nudge:**
    * *Sensors:* BNO085 (Stability / Inactivity classifier).
    * *Trigger:* Continuous zero-motion detected for $> 60\,\text{min}$ during daytime hours.
    * *Action:* Subtle haptic buzz + *"Time to stand up and stretch."*

---

## 3. NX-SDS — Self-Diagnostic System (Hardware Integrity & Proof-Testing)

Inspired by high-reliability industrial instrumentation architectures (such as automated in-situ proof testing and continuous self-diagnosis), **NX-SDS** serves as the internal health, safety, and hardware integrity engine for **ISD-Core**. 

While **NX-AIS** observes external environmental and physiological context, **NX-SDS** looks inward at silicon status, bus stability, reference voltages, and sensor degradation.

```text
┌────────────────────────────────────────────────────────────────────────────────────────┐
│                          NX-SDS (Self-Diagnostic System)                               │
├───────────────────────────────┬────────────────────────────────┬───────────────────────┤
│ 1. Continuous Diagnostics     │ 2. In-Situ Verification        │ 3. Predictive Trends  │
│ (Passive Background Sentinel) │ (On-Demand Proof-Testing)      │ (Long-Term Aging Log) │
├───────────────────────────────┼────────────────────────────────┼───────────────────────┤
│ • Bus ACK & lockup recovery   │ • BNO085 Silicon self-test     │ • Battery SoH & R_int │
│ • RTC Oscillator Stop Flag    │ • BME690 MOX heater audit      │ • MOX baseline drift  │
│ • MAX30102 photodiode dark cur│ • Cell Internal Resistance     │ • Bus retry trends    │
│ • FreeRTOS stack watermarks   │ • PMOS high-side leakage check │ • Flash wear metrics  │
└───────────────────────────────┴────────────────────────────────┴───────────────────────┘
```

### The Three Operational Pillars:

1. **Continuous Diagnostics (Passive Background Sentinel):**
   * *Execution:* Runs non-intrusively in `vSlowSensorTask` (~1 Hz) and bus error handlers.
   * *I2C Bus Hang Recovery:* Detects bus lockup (e.g. slave holding SDA low). Automatically generates a 9-clock SCL cycling pulse train to restore the bus without requiring a full system reboot.
   * *Oscillator Integrity:* Monitors the RV-3028-C7 Oscillator Stop Flag (`OSF`) to catch supply rail dips, crystal stalling, or time invalidation.
   * *RTOS Stack Watermark:* Calls `uxTaskGetStackHighWaterMark()` on `vUITask`, `vFastSensorTask`, and `vSlowSensorTask` to detect stack exhaustion before hard faults occur.
   * *Thermal & Voltage Bounds:* Flags out-of-range battery voltages ($V_{\text{cell}} < 3.2\text{V}$) or board temperatures ($T > 65^\circ\text{C}$).

2. **In-Situ Verification (On-Demand Deep Proof-Test):**
   * *Execution:* User-initiated from the Diagnostic Menu or automated during dock charging.
   * *Silicon Audit:* Queries hardware revision and `WHO_AM_I` registers across all 6 I2C ICs (`0x4A`, `0x57`, `0x76`, `0x45`, `0x36`, `0x52`).
   * *Heater Health Test:* Powers the BME690 gas heater through a calibrated step-profile; validates that target resistance and temperature ($320^\circ\text{C}$) are attained within the specified rise time.
   * *Optical Cross-Talk Test:* Reads MAX30102 photodiode dark-current with LEDs off; flags contaminated, scratched, or improperly seated glass.
   * *Battery Internal Resistance ($R_{\text{int}}$):* Strobe test pulsed via the 16-LED NeoPixel matrix for 50ms. Calculates instantaneous cell impedance:
     $$R_{\text{int}} = \frac{V_{\text{idle}} - V_{\text{load}}}{I_{\text{pulse}}}$$
   * *PMOS Cutoff Test:* Gates `PWR_NPM` (`IO17`) off and verifies quiescent current drops to nominal baseline.
   * *Storage Verification:* Performs a non-destructive block write/read/CRC pass on a dedicated NAND-SD diagnostic sector.
   * *Traceable Certificate:* Formats an audit report and appends it to `/sds/audit_log.txt` on NAND flash.

3. **Predictive Monitoring & Aging Trends:**
   * *Battery State-of-Health (SoH):* Compares actual loaded discharge curves against the ideal 1200mAh LiPo model to estimate capacity degradation over time.
   * *Gas Sensor Baseline Tracking:* Tracks long-term clean-air resistance ($R_0$) drift on the BME690 to preserve VOC/eCO2 calibration accuracy across months of wear.
   * *Flash Endurance Accounting:* Monitors write cycle counts and bad blocks on the ZDSD NAND chip.

### Standardized Status Categories (Inspired by NAMUR NE 107):
* 🟢 **SDS_OK (All Nominal):** 100% hardware subsystems verified operational.
* 🔵 **SDS_MAINTENANCE:** Maintenance advised (e.g. Magnetometer recalibration required, sensor optical window requires cleaning).
* 🟡 **SDS_OUT_OF_SPEC:** Operational boundaries exceeded (ambient temperature or supply sag).
* 🔴 **SDS_FAULT:** Hardware failure (I2C device unacknowledged, open-circuit heater, or storage CRC error).

---

## 4. Hardware Revision Tracking (v1p3 Production)

* [x] **NeoPixel Matrix:** Upgraded from 3×3 (9 LEDs) to 4×4 serpentine matrix (16 LEDs: `G1..G16`).
* [x] **PMOS Polarity:** Fixed high-side PMOS circuit for 0µA sleep on matrix.
* [x] **Display Interface:** 10-pin 0.5mm TE FPC connector `J1` integrated with backlight driver.
* [x] **Storage:** ZDSD NAND flash integrated on SPI bus.
* [x] **BNO085 Pull-ups:** Added 10k pull-ups `R18` and `R19` to `+3V3`.
* [x] **MAX30102 Filtering:** Added 100nF decoupling capacitor `C18` on `+1V8` rail.
* [x] **BOOT Jumper:** Added `JP3` solder jumper to pull GPIO 0 low for manual flashing.
* [x] **Power Architecture Rework:**
  * Replace tiny NCP167 LDO with **TLV62568** synchronous step-down buck converter (SOT-23 / SOT-563, $\approx 95\%$ efficiency).
  * Select compact shielded power inductor ($1.0\text{--}1.5\,\mu\text{H}$, $I_{sat} \ge 1.5\,\text{A}$).
  * Accommodate 1200mAh LiPo battery form factor on PCB layout.
  * Environmental sensor updated to **BME690**.

---

## 5. Firmware Implementation Checklist (ISD-Core)

* [x] FreeRTOS Multi-Tasking Core (`vUITask`, `vFastSensorTask`, `vSlowSensorTask`).
* [x] Thread-Safe Mutex-protected `SensorState` telemetry buffer.
* [x] 4×4 Serpentine Matrix Coordinate Engine (`NeoPixelTest::xy(x, y)`).
* [x] 6 Interactive Matrix Animations (`CYBER RADAR`, `GLYPH BREATH`, `QUANTUM RIPPLE`, `NEON TRACER`, `MATRIX RAIN`, `SPECTRUM PLASMA`).
* [x] Live 104×104 pixel TFT visualizer for NeoPixel matrix with Lever Left/Right cycling.
* [x] Level 1A Watchface HUD with dynamic 360° compass reticle, 2D spirit bubble level, and 1.2s tactical charge launcher.
* [x] Level 1B Quickpanel 2×3 action grid with interactive brightness dial, eco mode, silent, and shutdown/standby.
* [x] Level 2 3D Cover Flow App Launcher with trapezoidal depth projection and spring-damper physics.
* [x] Level 3 App 6 (SETTINGS) with 6 categories, strict 4-box viewport, and active scrollbar.
* [x] 360° Circular Radial Dials (Brightness, Timeout, Fade Anim, Volume, Duration, Pitch, NPM Brightness).
* [x] 4-Card Tactical Overview Menus (Tilt to Wake, Notifications, Shutdown).
* [x] Backlight on/off fade transitions with mathematical smoothstep curve ($t^2 \times (3 - 2t)$).
* [x] Persistent Storage Subsystem (`StorageManager`, onboard 2 Gbit ZDSD NAND Flash via SPI CS 47).
* [x] 64-byte packed binary struct (`/sys/config.bin`) with Magic signature `0x584E`, Schema `v1`, and CRC-16 CCITT.
* [x] Zero-wear save policy (dial in RAM, atomic commit only on `[PUSH]` or Settings exit).
* [x] Standalone configuration CLI inspection and JSON conversion tool (`tools/nx_config_tool.py`).
* [ ] Implement `NX-AIS` rule evaluation engine and background supervisor.
* [ ] Implement `NX-SDS` core engine (I2C 9-clock recovery, silicon audit, and battery internal resistance probe).
* [ ] Add `NX-SDS` in-situ proof-test UI page and NAND-SD certificate generation.
* [ ] Implement `PowerEstimator` class tracking active states against MAX17048.
* [ ] Implement BME690 + BNO085 1D Kalman Filter for altitude/variometer.
* [ ] Implement Magnus-Tetens dew point and 3-hour barometric storm gradient.
* [ ] Implement MAX30102 $R\text{-}R$ peak detector and RMSSD stress score.
* [ ] Implement BNO085 wrist-flip wake interrupt routine.

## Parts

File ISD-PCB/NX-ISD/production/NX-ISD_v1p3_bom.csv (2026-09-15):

Designator | Footprint | Quantity | Value | LCSC Part #
B1 | BUZ-SMD_4P-L8.5-W8.5-BR-1 | 1 | SMD-8503-3627-16Ω | C2685545
C1, C10, C16, C26, C4, C5, C8, C9 | 0603 | 8 | 1u
C11, C24, C33, C6 | 0603 | 4 | 10u
C12, C13, C17, C18, C19, C20, C21, C25, C27, C28, C29, C30, C31 | 0402 | 13 | 100n
C2, C32 | 0603 | 2 | 4.7u
C22, C23 | 0402 | 2 | 22p
C3, C7 | 0402 | 2 | 10n
D1 | D_SOD-123 | 1 | NRVB230LSFT1G
D2 | 0603 | 1 | ORANGE
D3 | D_SOD-523 | 1 | 1N4148WT
G1, G10, G11, G12, G13, G14, G15, G16, G2, G3, G4, G5, G6, G7, G8, G9 | LED-SMD_4P-L1.0-W1.0-TL_XL-1010RGBC-WS2812B | 16 | XL-1010RGBC-WS2812B | C5349953
J1 | SAMESKY_UJ20-C-H-G-SMT-1-P16-TR | 1 | UJ20-C-H-G-SMT-1-P16-TR
J2 | TE_1-2328702-0 | 1 | 1-2328702-0
L1 | 1008 | 1 | 2.2u
P1 | JST_S2B-PH-SM4-TB | 1 | S2B-PH-SM4-TB
Q1 | SOT-323_SC-70 | 1 | BC847W
Q2 | SOT-23 | 1 | AO3401A
Q3, Q4 | SOT-23 | 2 | AO3400A
R1, R2 | 0402 | 2 | 5.1k
R10, R4 | 0402 | 2 | 100K
R11, R12 | 0402 | 2 | 4.7k
R13, R14, R16, R17, R18, R19, R24, R26, R28, R29, R8 | 0402 | 11 | 10k
R15 | 0402 | 1 | 200k
R20, R21, R22 | 0402 | 3 | 51.1k
R23, R25 | 0402 | 2 | 220
R27 | 0402 | 1 | 10
R3 | 0402 | 1 | 453k
R5 | 0402 | 1 | 27k
R6 | 0402 | 1 | 499
R7, R9 | 0402 | 2 | 1k
RN1 | RESCAXS50P400X160X55-16N | 1 | YC248-JR-074K7L
S1 | KEY-SMD_TS-1101VS-C-A-A | 1 | TS-1101VS-C-A-A
TH1 | 0402 | 1 | 10k NTC
U1 | SOT23-5 | 1 | RT9193-18GB | C27416
U10 | SON65P200X200X65-7N | 1 | OPT3001DNPR
U11 | IC_BNO085 | 1 | BNO085
U12 | MicroCrystal_C7_SON-8_1.5x3.2mm_P0.9mm | 1 | RV-3028-C7
U13 | ESP32-S3-WROOM-1 | 1 | ESP32-S3-WROOM-1-N16R8 | ESP32-S3-WROOM-1-N16R8
U14 | LGA-8_L8.0-W6.0-P1.27-TL_ZDSD02GLGEAG | 1 | ZDSD02GLGEAG | C2875853
U15 | Texas_RGY_R-PVQFN-N16_EP2.05x2.55mm | 1 | TXB0106RGY
U16 | SW-SMD_TM-2025A | 1 | TM-2025A | C318949
U2 | SOT-666 | 1 | USBLC6-2P6
U3 | SOT-23-5 | 1 | TLV62568DBV
U4 | SOT23-5 | 1 | RT9193-28GB | C56731
U5 | SON50P200X200X80-9N | 1 | BQ25170DSGR
U6 | SON50P200X200X80-9N | 1 | MAX17048G_T10
U7 | Bosch_LGA-8_3x3mm_P0.8mm_ClockwisePinNumbering | 1 | BME690
U8 | Maxim_OLGA-14_3.3x5.6mm_P0.8mm | 1 | MAX30102
U9 | VSSOP-8_2.3x2mm_P0.5mm | 1 | PCA9306
Y1 | Crystal_SMD_3215-2Pin_3.2x1.5mm | 1 | 32.768 kHz

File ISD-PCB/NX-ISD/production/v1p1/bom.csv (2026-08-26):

Designator | Footprint | Quantity | Value | Distributor | DONE
B1 | BUZ-SMD_4P-L8.5-W8.5-BR-1 | 1 | SMD-8503-3627-16Ω | lcsc | X
C1, C12, C17, C29, C30, C5, C6, C7 | 0402 | 8 | 100n | digikey | x
C10, C13, C15, C2, C3, C4, C9, C20, C21, C8 | 0603 | 10 | 1u | digikey | x
C11, C14 | 0402 | 2 | 10n | digikey | x
C16, C22 | 0603 | 2 | 10u | digikey | x
C27, C28 | 0402 | 2 | 22p | digikey | x
D1 | 0603 | 1 | ORANGE | lcsc | x
D2 | 0402 | 1 | 1N4148WT | mouser | x
D5 | D_SOD-123 | 1 | D_Schottky_Filled | mouser | x
G1, G2, G3, G4, G5, G6, G7, G8, G9 | LED-SMD_4P-L1.0-W1.0-TL_XL-1010RGBC-WS2812B | 9 | XL-1010RGBC-WS2812B | lcsc | X
J1 | TE_1-2328702-0 | 1 | 1-2328702-0 | mouser | x
Q1, Q4 | SOT-23 | 2 | AO3400A | mouser | x
Q2 | SOT-23 | 1 | AO3401A | mouser | x
Q3 | SOT-323_SC-70 | 1 | BC847W | mouser | x
R1, R9 | 0402 | 2 | 5.1k | digikey | x
R10, R15, R5 | 0402 | 3 | 220 | digikey | x
R11 | 0402 | 1 | 500 | digikey | x
R12, R14, R17, R3, R4 | 0402 | 6 | 10k | digikey | x
TH1 | 0402 | 1 | 10k | digikey | x
R13 | 0402 | 1 | 1k | digikey | x
R2 | 0402 | 1 | 3K3 | digikey | x
R6 | 0402 | 1 | 100K | digikey | x
R8 | 0402 | 1 | 27k | digikey | x
RN1 | SOIC-16_3.9x9.9mm_P1.27mm | 1 | 8x4.7k | mouser | x
S1 | KEY-SMD_TS-1101VS-C-A-A | 1 | TS-1101VS-C-A-A | lcsc | X
U1 | ESP32-S3-WROOM-1 | 1 | ESP32-S3-WROOM-1 | mouser | x
U10 | IC_BNO085 | 1 | BNO085 | digikey | x
U11 | USB-C-SMD_HYCW275-USBC24-050B | 1 | HYCW275-USBC24-050B | lcsc | x
U12 | SON65P200X200X65-7N | 1 | OPT3001DNPR | mouser | x
U13 | SOT23-5 | 1 | RT9193-18GB | lcsc | X
U14 | LGA-8_L8.0-W6.0-P1.27-TL_ZDSD02GLGEAG | 1 | ZDSD02GLGEAG | lcsc | X
U15 | SOT-666 | 1 | USBLC6-2P6 | mouser | x
U2 | VREG_NCP167BMX330TBG | 1 | NCP167BMX330TBG | mouser | x
U3 | SON50P200X200X80-9N | 1 | MAX17048G_T10 | lcsc | x
U4 | MicroCrystal_C7_SON-8_1.5x3.2mm_P0.9mm | 1 | RV-3028-C7 | digikey | x
U5 | Maxim_OLGA-14_3.3x5.6mm_P0.8mm | 1 | MAX30102 | mouser | x
U6 | Bosch_LGA-8_3x3mm_P0.8mm_ClockwisePinNumbering | 1 | BME690 | mouser | x
U7 | SW-SMD_TM-2025A | 1 | TM-2025A | lcsc | X
U8 | SON50P200X200X80-9N | 1 | BQ25170DSGR | lcsc | X
U9 | SOT23-5 | 1 | RT9193-28GB | lcsc | X
Y2 | Crystal_SMD_3215-2Pin_3.2x1.5mm | 1 | 32.768 | digikey | x
Mouser list | https://www.mouser.ch/api/CrossDomain/GetContext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
DigiKey list | https://www.digikey.ch/de/mylists/list/ZAE84SNSN8
LCSC list | upload the LCSC-bOM.xls to LCSC to order the cooresponding parts

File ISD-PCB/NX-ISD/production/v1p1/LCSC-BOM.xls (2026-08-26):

NX-ISD |  |  |  |  |  |  |  |  |  | LCSC BOM Quotation
 |  |  |  |  |  |  |  |  |  | BOM Date Created：26/08/26 21:04:12 |  |  |  | BOM Export Date: 26/08/26 21:04:55 |  |  |  | The matching result is a real-time query result, availability and prices may fluctuate. Backorder items are estimated prices for your reference, please submit "Create Quote" to get the real price. All information is provided "as is" and is subject to change without notice. Any use made of the information provided is without recourse to LCSC and at the user's risk.
 |  |  |  |  |  |  |  |  |  | EST TOTAL :$62.12 |  |  |  | Website：https://www.lcsc.com/bom | https://www.lcsc.com/bom | https://www.lcsc.com/bom | https://www.lcsc.com/bom
Uploaded data |  |  |  |  |  |  |  |  |  | LCSC Matching Results
LCSC# | Mfr. | Mrf# | Description | Package | Value | Customer Part Number | Quantity | Target Price(USD) | Target Lead Time(Business Days) | Mrf# | Mfr. | Order Qty. | Unit Price(USD) | Ext.Price(USD) | LCSC# | Package | Min | Mult | SPQ | Availability | Stock Status | Customer Notes | Description | Matched status | Product Link
 |  |  |  |  |  |  | 10 |  |  | TM-2025A | XKB Connection | 10 | 0.4084 | 4.08 | C318949 | SMD | 1 | 1 | 1000 | 1057 | In Stock |  | SMD Navigation Switches, Joystick | Exact Matches | https://www.lcsc.com/product-detail/C318949.html
 |  |  |  |  |  |  | 10 |  |  | SMD-8503-3627-16Ω | S&S | 10 | 0.3089 | 3.09 | C2685545 | SMD,8.5x8.5mm | 5 | 5 | 1000 | 7240 | In Stock |  | Buzzers Passive (Externally Driven) Magnetic 3.6V 2.7kHz 80dB SMD,8.5x8.5mm | Exact Matches | https://www.lcsc.com/product-detail/C2685545.html
 |  |  |  |  |  |  | 10 |  |  | RT9193-28GB | RICHTEK | 10 | 0.1394 | 1.39 | C56731 | SOT-23-5 | 5 | 5 | 3000 | 16205 | In Stock |  | 2.8V Positive Fixed SOT-23-5 Voltage Regulators - Linear, Low Drop Out (LDO) Regulators RoHS | Exact Matches | https://www.lcsc.com/product-detail/C56731.html
 |  |  |  |  |  |  | 10 |  |  | RT9193-18GB | RICHTEK | 10 | 0.1669 | 1.67 | C27416 | SOT-23-5 | 5 | 5 | 3000 | 26405 | In Stock |  | 1.8V Positive Fixed SOT-23-5 Voltage Regulators - Linear, Low Drop Out (LDO) Regulators RoHS | Exact Matches | https://www.lcsc.com/product-detail/C27416.html
 |  |  |  |  |  |  | 2 |  |  | ZDSD02GLGEAG | Zetta | 2 | 9.1315 | 18.26 | C2875853 | LGA-8(6x8) | 1 | 1 | 480 | 794 | In Stock |  | 2Gbit 2.7V~3.6V 50MHz LGA-8(6x8) Memory RoHS | Exact Matches | https://www.lcsc.com/product-detail/C2875853.html
 |  |  |  |  |  |  | 10 |  |  | TS-1101VS-C-A-A | XKB Connection | 10 | 0.0807 | 0.81 | C318936 | SMD,7x2.5mm | 10 | 10 | 2000 | 5240 | In Stock |  | Tactile Switch SPST 260gf 3.5mm 7mm x 2.5mm Surface Mount, Right Angle | Exact Matches | https://www.lcsc.com/product-detail/C318936.html
 |  |  |  |  |  |  | 10 |  |  | HYCW275-USBC24-050B | HOAUC | 10 | 0.3363 | 3.36 | C42400261 | SMD | 5 | 5 | 1000 | 75 | In Stock |  | USB-C (USB TYPE-C) Receptacle Connector 24 Position Surface Mount, Right Angle | Exact Matches | https://www.lcsc.com/product-detail/C42400261.html
 |  |  |  |  |  |  | 30 |  |  | XL-1010RGBC-2812B | XINGLIGHT | 30 | 0.0774 | 2.32 | C5349953 | SMD,1x1mm | 10 | 10 | 4000 | 334730 | In Stock |  | SMD,1x1mm LED Addressable, Specialty RoHS | Exact Matches | https://www.lcsc.com/product-detail/C5349953.html
 |  |  |  |  |  |  | 10 |  |  | BQ25170DSGR | TI | 10 | 0.7093 | 7.09 | C5208201 | WSON-8(2x2) | 1 | 1 | 3000 | 1879 | In Stock |  | Battery Charging IC Multi-Chemistry WSON-8(2x2) | Exact Matches | https://www.lcsc.com/product-detail/C5208201.html
 |  |  |  |  |  |  | 10 |  |  | MAX17048G+T10 | MAXIM | 10 | 1.9323 | 19.32 | C2682616 | DFN-8-EP(2x2) | 1 | 1 | 10000 | 13698 | In Stock |  | I2C Lithium Battery DFN-8-EP(2x2) Battery Management RoHS | Exact Matches | https://www.lcsc.com/product-detail/C2682616.html
 |  |  |  |  |  |  | 20 |  |  | XL-1608UOC-06FJ | XINGLIGHT | 20 | 0.0366 | 0.73 | C7371899 | 0603 | 20 | 20 | 4000 | 6420 | In Stock |  | Orange 605nm LED Indication - Discrete 1.9V~2.3V 0603 | Exact Matches | https://www.lcsc.com/product-detail/C7371899.html

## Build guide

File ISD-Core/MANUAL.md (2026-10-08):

# ISD-Core // User & Navigation Manual

Welcome to the **ISD-Core User & Navigation Manual** for the **NX-ISD** (Intelligent Sensor Device).

ISD-Core is built on a central design philosophy: **it is an intuitive, tactile smartwatch operating system—not a wearable spreadsheet of raw sensor dumps.** The user interface draws inspiration from retro-futuristic amber vector displays (TVA, Pip-Boy, and aerospace instrumentation), organized into **6 human-centered application decks** driven by physical controls, zero input lag, and real-time physical feedback.

> [!NOTE]
> 🛠️ **Looking for the Developer & Firmware Architecture Guide?**  
> For dual-core FreeRTOS scheduling, Octal PSRAM buffers, hardware bus maps, pinouts, and PlatformIO compilation, see [**README.md**](README.md).

---

## Table of Contents
1. [Physical Hardware Controls & Gestures](#1-physical-hardware-controls--gestures)
2. [Operating System Navigation Map](#2-operating-system-navigation-map)
3. [Level 1: Primary Shell Screens](#3-level-1-primary-shell-screens)
   - [Level 1A: Watchface HUD (Default Screen)](#level-1a-watchface-hud-default-screen)
   - [Level 1B: Quickpanel Action Grid](#level-1b-quickpanel-action-grid)
   - [Level 1C: Notifications Stack](#level-1c-notifications-stack)
4. [Level 2: 3D Cover Flow App Launcher](#4-level-2-3d-cover-flow-app-launcher)
5. [Level 3: The 6 Core Application Decks](#5-level-3-the-6-core-application-decks)
   - [App 1: VITALS (Internal Physiology)](#app-1-vitals-internal-physiology)
   - [App 2: ENVIRONMENT (External Ambience)](#app-2-environment-external-ambience)
   - [App 3: CLOCK (Temporal Operations)](#app-3-clock-temporal-operations)
   - [App 4: DEVICE (Silicon & Hardware Integrity)](#app-4-device-silicon--hardware-integrity)
   - [App 5: TOOLS (Tactical & Field Operations)](#app-5-tools-tactical--field-operations)
   - [App 6: SETTINGS (System Orchestration)](#app-6-settings-system-orchestration)
6. [Interactive Control Paradigms](#6-interactive-control-paradigms)
   - [360° Circular Radial Dials](#360-circular-radial-dials)
   - [4-Card Tactical Overview Menus](#4-card-tactical-overview-menus)
   - [Cinematic Smoothstep Backlight Transitions](#cinematic-smoothstep-backlight-transitions)
7. [Persistent Storage & Zero-Wear Policy](#7-persistent-storage--zero-wear-policy)
   - [How Your Settings Are Saved](#how-your-settings-are-saved)
   - [Offline PC Configuration Tool](#offline-pc-configuration-tool)
8. [Summary Navigation Quick-Reference](#8-summary-navigation-quick-reference)

---

## 1. Physical Hardware Controls & Gestures

The NX-ISD hardware eliminates touchscreens in favor of high-reliability physical controls that can be operated blind, with gloves, or in adverse field conditions:

```text
                     ┌───────────────────────────┐
                     │    ST7789 IPS Display     │
                     │         (240x240)         │
                     │          [ HUD ]          │
                     └───────────────────────────┘
                                         [ BTN ] (GPIO 13) ── Back / Exit / Wake
                     ┌───────────────────────────┐
      [ LEVER LEFT ] │      [ LEVER PUSH ]       │ [ LEVER RIGHT ]
        (GPIO 16)    │        (GPIO 15)          │   (GPIO 14)
       Prev / Dec    │    Select / 1.2s Charge   │   Next / Inc
```

### Control Bindings & Timing Parameters

| Control | Hardware | Gesture | Timing | Action |
| :--- | :---: | :--- | :---: | :--- |
| **LEVER LEFT** | `GPIO 16` | **Flick / Click** | $< 475\,\text{ms}$ | Previous card, scroll left, or decrement value. |
| | | **Hold** | $\ge 475\,\text{ms}$ | **Hold-to-repeat:** Cycles every $160\,\text{ms}$ for fast numeric dialing. |
| **LEVER RIGHT** | `GPIO 14` | **Flick / Click** | $< 475\,\text{ms}$ | Next card, scroll right, or increment value. |
| | | **Hold** | $\ge 475\,\text{ms}$ | **Hold-to-repeat:** Cycles every $160\,\text{ms}$ for fast numeric dialing. |
| **LEVER PUSH** | `GPIO 15` | **Click** | $< 1.2\,\text{s}$ | Select, toggle setting, confirm hero card, or enter Quickpanel. |
| | | **Tactical Charge** | $\ge 1.2\,\text{s}$ | **Hold Charge Gesture:** Sweeps energy arc to launch the 3D App Menu. |
| **BTN** | `GPIO 13` | **Click** | Any | **Global Back / Cancel:** Pops up one level; wakes display from Standby. |

* **Zero Input Lag:** Lever inputs trigger dedicated IRAM ISRs with $< 1\,\mu\text{s}$ latching and a $40\,\text{ms}$ software debouncing window.

---

## 2. Operating System Navigation Map

ISD-Core implements a strict **3-Tier Hierarchical Navigation Structure**. You are never trapped in deeply nested submenus and are never more than two clicks away from the home watchface:

```text
┌────────────────────────────────────────────────────────────────────────────────────────┐
│ LEVEL 1: PRIMARY OS SHELL                                                             │
│                                                                                        │
│   [ Notifications ]  <───── LEVER L ────  [ Watchface HUD ]  ──── LEVER R ─────>  [ Quickpanel ]
│                                                  │                                     │
│                                                  │ 1.2s Charge Hold                    │ Click PUSH
│                                                  │ (LEVER_PUSH)                        │ (on Tile)
│                                                  ▼                                     │
├──────────────────────────────────────────────────┼─────────────────────────────────────┤
│ LEVEL 2: 3D APP LAUNCHER                         │                                     │
│                                                  │                                     │
│   ┌──────────────────────────────────────────────┴─────────────────────────────────┐   │
│   │                          3D Cover Flow Deck                                    │   │
│   │   [VITALS] ── [ENVIRONMENT] ── [CLOCK] ── [DEVICE] ── [TOOLS] ── [SETTINGS]    │   │
│   └──────────────────────────────────────────────┬─────────────────────────────────┘   │
│                                                  │                                     │
│                                                  │ Click PUSH                          │
│                                                  │ (on active card)                    │
│                                                  ▼                                     ▼
├────────────────────────────────────────────────────────────────────────────────────────┤
│ LEVEL 3: DEDICATED APPS & MENUS                                                        │
│                                                                                        │
│   • Vitals Monitor (HRM/SpO2)   • Device & NX-SDS Health       • Brightness Dial       │
│   • Environment & Weather       • Tactical Tools & Uplink      • Power & Reboot Menu   │
│   • Chrono & Timers             • System & NX-AIS Settings     • Quick Actions         │
│                                                                                        │
│   (Pressing BTN at any time immediately pops up to Level 2 Launcher or Level 1 HUD)    │
└────────────────────────────────────────────────────────────────────────────────────────┘
```

---

## 3. Level 1: Primary Shell Screens

### Level 1A: Watchface HUD (Default Screen)

The home screen delivers immediate situational awareness without visual clutter:

```text
+-----------------------------------+  (0, 0)
| NX-ISD                 [===] 98%  |  Header: System status & Battery meter
| --------------------------------- |  Hairline divider
|             14:32:08              |  Large crisp digital time (RV-3028 RTC)
|                                   |
|   [ 24.3 C ]         [ 48 %RH ]   |  BME690 Temperature & Humidity badges
|                                   |
|               ( N )               |  Rotating Compass Reticle with
|             /   |   \             |  Cardinal Points (N, E, S, W)
|            W --(o)-- E            |  Central 2D Spirit Bubble Level
|             \   |   /             |  Outer Battery Arc Gauge
|               ( S )               |
|                                   |
|          HDG: 042  P: +02 R: -01  |  Numeric heading, pitch, and roll
+-----------------------------------+  (239, 239)
```

* **Header Bar:** Shows active view name and live battery percentage with charging badge (`[CHG]`).
* **Digital Clock:** Synchronized with the ultra-low-power RV-3028 RTC ($0.05\,\mu\text{A}$ timekeeping).
* **Telemetry Badges:** Real-time environmental readings filtered to eliminate sensor jitter.
* **Compass & Spirit Bubble:** Dynamic 360° rotating azimuth reticle with shortest-path circular interpolation, framing a real-time 2D bubble level driven by the BNO085 accelerometer.
* **Tactical Charge Ring:** When `LEVER_PUSH` is held, an amber radial energy meter sweeps clockwise around the compass ring. Completing the 1.2s charge triggers an audible chime and launches the 3D App Menu.

---

### Level 1B: Quickpanel Action Grid

Accessed by flicking **`LEVER_RIGHT`** from the Watchface HUD. A 2×3 grid of tactical rounded action tiles:

```text
+-----------------------------------+
| QUICK ACCESS             [ X ]    |  Header with close hint (BTN)
| --------------------------------- |
|  +-------------+  +-------------+ |
|  | [SETTINGS]  |  |   [ HRM ]   | |  Settings shortcut / Spot heart-rate scan
|  +-------------+  +-------------+ |
|  +-------------+  +-------------+ |
|  | [ECO MODE]  |  | [BRIGHTNESS]| |  Power toggle / Interactive brightness dial
|  +-------------+  +-------------+ |
|  +-------------+  +-------------+ |
|  |  [SILENT]   |  | [SHUTDOWN]  | |  Audio & NeoPixel mute / Standby & Power
|  +-------------+  +-------------+ |
+-----------------------------------+
```

* **Navigation:** Lever Left/Right cycles active tile focus (highlighted by an inverted amber fill). Clicking `LEVER_PUSH` triggers the action.
* **Brightness Dial:** Clicking `[BRIGHTNESS]` opens a circular dial with live screen dimming from 10% to 100% in 5% increments.
* **Shutdown / Standby:** Clicking `[SHUTDOWN]` opens a power sheet offering **Standby** (instant display shutoff, $<15\,\text{mA}$, wake on any key) or **Reboot**.

---

### Level 1C: Notifications Stack

Accessed by flicking **`LEVER_LEFT`** from the Watchface HUD:

```text
+-----------------------------------+
| NOTIFICATIONS (2)        [CLR]    |  Header: Unread count & Clear-all
| --------------------------------- |
| +-------------------------------+ |
| | [!] NX-AIS ADVISORY     14:15 | |  Card 1: High priority alert
| | Rapid pressure drop detected. | |
| | Storm risk: DeltaP > 2.5 hPa  | |
| +-------------------------------+ |
| +-------------------------------+ |
| | [*] VITALS REMINDER     13:30 | |  Card 2: Routine reminder
| | Scheduled hourly HRM check.   | |
| +-------------------------------+ |
+-----------------------------------+
```

* Displays chronological notifications, NX-AIS intelligence advisories, and timer alerts.
* Pressing `LEVER_PUSH` expands the selected notification; pressing `BTN` dismisses it.

---

## 4. Level 2: 3D Cover Flow App Launcher

Triggered by the **1.2-second Tactical Charge Gesture** on the Watchface HUD:

```text
+-----------------------------------+
| \ ============================= / |  Top Slanted Cradle Rail
|                                   |
|   +----+      +-------------+     |
|  /     /     /| ENVIRONMENT |     |  Flanking Cards: 3D Perspective Scaling
| / VIT /     | |   HERO CARD |     |  Hero Card: Full 1:1 Scale & Bright Focus
| \     \     | | Temp Lux Gas|     |  Trapezoidal Depth Projection
|  \     \    | | Baro Storm  |     |
|   +----+    | +-------------+     |
|              \|             |     |
|                                   |
| / ============================= \ |  Bottom Slanted Cradle Rail
| [<<] LEVER: SELECT   PUSH: ENTER  |  Tactile bottom navigation prompt
+-----------------------------------+
```

* **True 3D Perspective Projection:** Cards smoothly scale and distort trapezoidally as they approach the center of the display.
* **Spring-Damper Physics:** Scrolling is fluid and organic (`diff * 0.48f`), snapping securely into the nearest hero card on lever release.
* **Mechanical Hardware Cradle:** Slanted top and bottom structural rails frame the carousel like an aerospace bay.
* **Launching an App:** Click **`LEVER_PUSH`** on the centered hero card to enter. Press **`BTN`** to spring back to the Watchface HUD.

---

## 5. Level 3: The 6 Core Application Decks

ISD-Core groups all functionality into **6 dedicated, human-centered decks**:

```text
┌─────────────────────────┬─────────────────────────┬─────────────────────────┐
│       PHYSIOLOGY        │        TEMPORAL         │         SILICON         │
│       [ VITALS ]        │        [ CLOCK ]        │       [ DEVICE ]        │
├─────────────────────────┼─────────────────────────┼─────────────────────────┤
│       ENVIRONMENT       │         ACTION          │         CONTROL         │
│     [ ENVIRONMENT ]     │        [ TOOLS ]        │      [ SETTINGS ]       │
└─────────────────────────┴─────────────────────────┴─────────────────────────┘
```

---

### App 1: VITALS (Internal Physiology)
*Focus: Personal health telemetry, recovery metrics, and autonomic stress.*

```text
+-----------------------------------+
| VITALS // MAX30102         [RUN]  |
| --------------------------------- |
|   HEART RATE         SpO2         |
|   [ 72 ] BPM        [ 98 ] %      |  Live / Last measured readings
|   Last: 14m ago     Last: 14m ago |  Elapsed timestamp
| --------------------------------- |
|   /\    /\    /\    /\            |  Real-time animated ECG pulse trace
| --/  \--/  \--/  \--/  \--------- |  during active optical sampling
| --------------------------------- |
|   STRESS INDEX: [ 28 / BALANCED ] |  NX-MSF Autonomic Stress Score (RMSSD)
|   [=====>-------------]           |  Visual stress bar gauge
|   REMAIN STATIONARY FOR MEASURE   |
+-----------------------------------+
```

* **Last Measured Spot-Check:** Immediately presents your last recorded heart rate and blood oxygen saturation ($SpO_2$) along with the exact time elapsed since measurement.
* **Live Optical Measurement:** Initiates live high-speed PPG sampling on the MAX30102 with a scrolling real-time ECG waveform and finger-contact detection.
* **Autonomic Stress Score (NX-MSF):** Analyzes successive $R\text{-}R$ intervals and calculates Root Mean Square of Successive Differences (RMSSD) to output a 0–100 Stress Index (*Relaxed*, *Balanced*, *Elevated*, *High Tension*).
* **Cyclic Measurement Reminders:** Set automatic background prompts (every 30m, 1h, 2h). Alerts route to the 4×4 NeoPixel matrix (gentle pulsing glyph), the buzzer, or both.

---

### App 2: ENVIRONMENT (External Ambience)
*Focus: Ambient reconnaissance, real-time 3D planetary rendering, meteorological forecasting, and alpine trail safety.*

```text
+-----------------------------------+
| ISD-Core // ENVIRONMENT     98%   |
| --------------------------------- |
```text
+-----------------------------------+
| ISD-Core // ENVIRONMENT     [98%] |  Master Pinned Header Bar
| --------------------------------- |
| [ATMOSPHERE  ] [CLIMATE         ] |  Top Telemetry Pods: Pressure & Climate
| [1014 hPa FAIR] [24.2C   48% RH  ] |
|        \                 /        |  Tactile Blueprint Leader Lines
|         (O)─ . - . ─(O)           |  with (O) Atmospheric Anchor Nodes
|             :  3D :               |  Real-Time 3D Rotating Vector Earth
|         (O)─ ' - ' ─(O)           |  tilted at 23.4° with live continents
|        /                 \        |
| [AIR QUALITY ] [PHOTOMETRICS    ] |  Bottom Telemetry Pods: BME690 & OPT3001
| [142 kΩ  CLEAN] [850 lx DAYLIGHT ] |
| --------------------------------- | [===] Side Scrollbar (Card 0/5)
+-----------------------------------+
```

The Environment deck uses a **6-card vertical hierarchical card architecture** with a **smooth spring-damper sliding transition** between cards and a tactical side scrollbar:

1. **Card 0: Master Environmental Command HUD:**
   * **Real-Time 3D Rotating Vector Earth:** Rendered live on the ESP32-S3 hardware FPU with Earth's genuine $23.4^\circ$ axial tilt, rotating longitude meridians, projected latitude parallels, and 3D vector continent coastlines.
   * **Tactical Blueprint Leader Lines:** Circuit traces with `(O)` anchor nodes pin Earth's atmosphere directly to 4 corner telemetry pods (`ATMOSPHERE`, `CLIMATE`, `AIR QUALITY`, `PHOTOMETRICS`).
2. **Card 1: WEATHER & METEOROLOGICAL FORECAST:**
   * **Dynamic Vector Weather Glyphs:** Custom vector icons reflecting real-time conditions (☀️ `CLEAR / FAIR`, ⛅ `PARTLY CLOUDY`, ☁️ `OVERCAST`, 🌧️ `RAIN LIKELY`, ⛈️ `STORM ALERT`).
   * **3-Hour Barometric Tendency ($\Delta P / \Delta t$):** Analyzes rolling barometric slope to detect incoming storm fronts before rain arrives.
   * **Dew Point & Trail Fog Sentinel:** Calculates condensation margin via Magnus-Tetens formula; warns hikers if trail fog or dew convergence is imminent ($(T - T_{\text{dew}}) \le 1.5^\circ\text{C}$).
3. **Card 2: ATMOSPHERE & ALTITUDE (Barometer Deep-Dive):**
   * **Mountain Elevation Profile:** Vector mountain silhouette with a dynamic altitude target line calculating real-time elevation ($m$ & $ft$) from the BME690 barometric formula.
   * **16-Bar Historical Isobaric Sparkline:** Real-time pressure trend graph showing atmospheric pressure changes across rolling samples.
   * **`[PUSH]`:** Zero relative elevation ($QNH$ baseline calibration).
4. **Card 3: CLIMATE & THERMAL (Psychrometrics Deep-Dive):**
   * **Vector Thermometer Capillary Tube:** Mercury fluid column dynamically rising and falling with temperature, with etched tick marks and session min/max memory.
   * **Psychrometric Comfort Envelope:** Maps temperature versus humidity with an active cursor dot indicating the human comfort target zone.
   * **`[PUSH]`:** Toggles between $^\circ\text{C} \longleftrightarrow ^\circ\text{F}$.
5. **Card 4: AIR QUALITY & VOC (BME690 Sensor Fusion Deep-Dive):**
   * **Hero IAQ & Tier Metric:** Real-time 0–500 Air Quality Index (German UBA standard) with tactical status tier badge (`EXCELLENT`, `GOOD`, `MODERATE`, `POOR`, `HAZARDOUS`).
   * **16-Segment Air Purity Gauge:** Calibrated 0–100% purity meter tracking live compensated gas resistance relative to the clean-air baseline.
   * **Quad Telemetry Pods:** Four live metrics in dual rows:
     * $e\text{CO}_2$: Estimated carbon dioxide ($400\text{--}3600\text{ ppm}$) from metabolic VOC correlation.
     * $\text{bVOC}$: Total breath/volatile organics ($0.05\text{--}5.0\text{ ppm}$).
     * $R_{\text{gas}}$: Moisture- and temperature-compensated MOX resistance ($\text{k}\Omega$).
     * $R_0$: Dynamic adaptive clean-air baseline reference ($\text{k}\Omega$).
   * **VOC Plume Sentinel:** High-speed $\Delta R/\Delta t$ rate-of-change detector warning on sudden chemical spikes (`▲ PLUME SPIKE ⚠️`, `● AIR STEADY`, `▼ PURGING AIR`).
   * **16-Bar Real-Time Sparkline:** Chronological history graph tracking VOC levels with a dotted clean-air baseline reference line.
   * **`[PUSH]`:** Triggers an on-demand $300^\circ\text{C}$ MOX heater burn cycle with thermal pulse animation.
6. **Card 5: PHOTOMETRICS & SOLAR (OPT3001 Light Deep-Dive):**
   * **Dynamic Optical Aperture:** A 6-blade mechanical camera iris that physically dilates based on ambient Lux.
   * **180° Celestial Daylight Horizon Arc:** Sweeping horizon arc marking lighting zones (`NIGHT` $\to$ `INDOORS` $\to$ `DAYLIGHT`) with a logarithmic sun satellite pip.

#### Navigation & Tactical Side Scrollbar
* **Smooth Vertical Sliding:** Moving between cards smoothly slides the entire canvas up or down with spring-damper easing. Content is strictly clipped between the top header and bottom frame, eliminating visual clutter.
* **Tactical Right Side Scrollbar:** A clean vertical indicator track at the right display edge indicates your active position across the 6 cards with an illuminated amber thumb, completely removing the need for a cramped bottom footer.
* **`LEVER RIGHT` (or Down):** Slides down to the next card ($0 \to 1 \to 2 \to 3 \to 4 \to 5$).
* **`LEVER LEFT` (or Up):** Slides up to the previous card ($5 \to 4 \to 3 \to 2 \to 1 \to 0$).
* **`LEVER PUSH`:** 
  * On Master HUD (Card 0): Jumps directly to Weather & Forecast (Card 1).
  * On Deep-Dive Cards: Triggers contextual action (Zero Elevation, Toggle $^\circ\text{C}/^\circ\text{F}$, Pulse BME690 Heater).
* **`BTN` (Back):**
  * On Deep-Dive Cards ($1 \dots 5$): Snaps straight back up to Master HUD (Card 0).
  * On Master HUD (Card 0): Exits back to 3D App Menu.

---

### App 3: CLOCK (Temporal Operations)
*Focus: Precision timekeeping, interval workouts, alarms, and state survival.*

```text
+-----------------------------------+
| CLOCK // CHRONOGRAPH       [MODE] |
| --------------------------------- |
|          00 : 04 : 18 . 42        |  Large millisecond stopwatch display
|                                   |
|   LAP 1: 00:01:12.10              |
|   LAP 2: 00:03:06.32              |  Split-lap logging table
| --------------------------------- |
|   [>] START    [R] RESET   [L] LAP|  Tactile lever control hints
| --------------------------------- |
|   TIMER: 05:00 (IDLE)             |  Quick-switch to countdown timer
|   ALARM 1: 07:00 [ON] (DAILY)     |  Battery-backed hardware alarm
+-----------------------------------+
```

* **Chrono / Stopwatch:** High-precision millisecond stopwatch with split-lap logging and recorded lap history.
* **Countdown Timer:** Quick-dial timer with progress bar, audible warble, and flashing amber NeoPixel matrix alert.
* **Hardware Alarms:** Multi-slot daily and one-shot alarms synced to the RV-3028 RTC hardware interrupt line.
* **World Clock:** Auxiliary display for dual UTC / secondary time-zone offsets.
* **Non-Volatile NAND State Persistence:** Commits active countdown timers, alarms, and settings directly to onboard NAND Flash. If the battery is completely drained, all timers and states restore automatically on the next boot!

---

### App 4: DEVICE (Silicon & Hardware Integrity)
*Focus: Silicon self-diagnostics, energy accounting, and system health.*

```text
+-----------------------------------+
| DEVICE // NX-SDS DIAG     [PASS]  |
| --------------------------------- |
|  I2C BUS: ACK OK (400 kHz Fast)   |  Bus audit & automated 9-clock recovery
|  BNO085: OK    BME690: OK         |  Sensor proof-testing results
|  OPT3001: OK   RV3028: OK [OSF:0] |  Oscillator Stop Flag (OSF) audit
| --------------------------------- |
|  BATTERY: 4.12V  98%  (+0.2 %/h)  |  MAX17048 Fuel Gauge telemetry
|  CELL HEALTH: 99%  R_INT: 85 mOhm |  Internal resistance health metric
| --------------------------------- |
|  PSRAM: [====>--------] 2.1/8.0 MB|  Octal PSRAM heap watermark
|  HEAP:  182 kB FREE   FLASH: 16 MB|  FreeRTOS core memory
+-----------------------------------+
```

* **NX-SDS Self-Diagnostic Suite:**
  * **I2C Bus Audit:** Probes all bus addresses; automatically executes 9-clock SCL pulse trains to recover hung slave lines.
  * **Sensor Proof-Testing:** On-demand self-tests for BNO085 internal co-processor, BME690 hotplate, and OPT3001 conversion registers.
  * **Oscillator Watchdog:** Inspects the RV-3028 `OSF` (Oscillator Stop Flag) to detect brownouts, crystal failure, or invalid RTC timing.
* **MAX17048 Fuel Gauge Telemetry:** Live cell terminal voltage ($V_{\text{cell}}$), charge/discharge rate (%/hr), estimated internal cell resistance ($R_{\text{int}}$), and health cycle counters.
* **Memory & Storage Gauges:** Visual bar meters showing Octal PSRAM usage (8 MB pool), FreeRTOS heap watermarks, and NAND Flash storage wear.

---

### App 5: TOOLS (Tactical & Field Operations)
*Focus: Field instrumentation, wireless scanning, and companion bridge.*

```text
+-----------------------------------+
| TOOLS // SPIRIT LEVEL      [2D]   |
| --------------------------------- |
|              +-------+            |  2D Bubble Level target reticle
|              |   o   |            |  Dynamic bubble rendered via BNO085
|              +-------+            |
|       PITCH: +01.2  ROLL: -00.4   |  Precision numeric degree readouts
| --------------------------------- |
|  [WIFI/BLE SNIFFER]               |  2.4 GHz signal strength scanner
|  NET_HOME_5G  [-42 dBm] ========= |
|  BLE_TAG_04   [-68 dBm] =====     |
| --------------------------------- |
|  NX-UPLINK: PAIRED (base44.app)   |  Companion web dashboard bridge
+-----------------------------------+
```

* **Tactical 2D Spirit Level:** High-precision surface leveling tool utilizing the BNO085 accelerometer, featuring a responsive central bubble and digital pitch/roll readouts.
* **Wireless Scanner & RSSI Meter:** Scans local 2.4 GHz WiFi channels and BLE advertisements, rendering dynamic signal strength RSSI gradient meters.
* **NX-Uplink Companion Bridge:** Manages wireless pairing and synchronization with the companion web dashboard ([www.nx-uplink.base44.app](https://www.nx-uplink.base44.app)) for telemetry export and firmware updates.
* **Hardware Pin Monitor:** Inspects charger state lines (`/PG` USB power, `/STAT` active charging) and system GPIO rails in real time.

---

### App 6: SETTINGS (System Orchestration)
*Focus: OS customization, hardware configuration, and tactile acoustic orchestration.*

```text
+-----------------------------------+
| ISD-Core // SETTINGS        [98%] |  Header with real-time battery status
| --------------------------------- |
|  +-----------------------------+  |
|  | DISPLAY                  >  |  |  Category Card 1
|  +-----------------------------+  |
|  +-----------------------------+  |
|  | NOTIFICATIONS            >  |  |  Category Card 2
|  +-----------------------------+  |
|  +-----------------------------+  |
|  | POWER SAVE               >  |  |  Category Card 3
|  +-----------------------------+  |
|  +-----------------------------+  |
|  | BUZZER                   >  |  |  Category Card 4
|  +-----------------------------+  |
| --------------------------------- |
| [PUSH] SELECT  < LEVER > NAV [BTN]|  Navigation context bar
+-----------------------------------+
```

Settings is structured into **6 distinct categories** adhering to a strict **4-box viewport rule** with an active vertical scrollbar track and thumb. The list never cramps options; exactly 4 cards are shown at a time, smoothly scrolling as you navigate:

1. **DISPLAY:**
   * **BRIGHTNESS:** 360° circular radial dial with orbital satellite pip (10% to 100% in 5% steps).
   * **AUTO DIM:** Toggles real-time ambient light compensation via the OPT3001 sensor.
   * **TILT TO WAKE:** Opens a dedicated **4-Card Overview Menu** (`OFF`, `SENSITIVE`, `BALANCED`, `SLUGGISH`).
   * **TIMEOUT:** 360° circular dial from 5s to 300s (or `NEVER` / Always-On at 0s).
   * **WRIST COVER:** Toggles instant standby upon optical sensor occlusion.
   * **FADE ANIM:** 360° circular dial for display on/off backlight transition duration (0ms to 2000ms in 50ms steps).
2. **NOTIFICATIONS:**
   * **METHOD:** Dedicated 4-card overview menu (`SILENT`, `ALL`, `SOUND ONLY`, `LIGHTS ONLY`).
   * **MATRIX LED:** Toggle 4×4 NeoPixel matrix optical alert flashes.
   * **HRM REMINDER:** Cycle cyclic spot-measurement prompts (`OFF`, `30m`, `1h`, `2h`).
3. **POWER SAVE:**
   * **ECO MODE:** Toggle reduced sensor poll rates and standby CPU throttling.
   * **AUTO STANDBY:** Enable/disable automatic screen-off sleep upon timeout.
   * **SENSOR SLEEP:** Power down environmental/IMU sensor rails during standby.
4. **BUZZER (Acoustic Orchestration):**
   * **MASTER AUDIO:** Quick toggle for silent / unmuted system state.
   * **VOLUME:** 360° circular dial with acoustic soundwave arcs (10% to 100% duty cycle).
   * **TICK DURATION:** 360° circular dial with digital square-wave pulse width graphic (2ms to 30ms).
   * **TONE PITCH:** 360° circular dial with animated sine-wave graphic (1600 Hz to 4400 Hz in 100 Hz steps).
5. **NPM (4×4 NeoPixel Matrix):**
   * **MATRIX POWER:** High-side PMOS power gate toggle (0 µA quiescent draw when OFF).
   * **BRIGHTNESS:** 360° circular dial with 4×4 matrix icon (10% to 100% in 5% steps).
   * **ANIMATION:** Cycle real-time patterns (`RADAR`, `RAIN`, `PLASMA`, `TRACER`, `BREATH`, `OFF`).
   * **TEST PULSE:** Fires an instantaneous high-vis amber verification pulse.
6. **NX-AIS (Autonomous Intelligence):**
   * **CO-PROCESSOR:** Enable/disable background algorithmic supervisor.
   * **ADAPTIVE:** Toggle dynamic environmental context thresholds.
   * **DIAGNOSTICS:** Hardware & sensor fusion diagnostics.

---

## 6. Interactive Control Paradigms

### 360° Circular Radial Dials

Whenever adjusting continuous numerical values (such as Brightness, Volume, Pitch, or Timeouts), ISD-Core uses an aerospace-style 360° circular radial dial:

```text
+-----------------------------------+
| DISPLAY // BRIGHTNESS             |  View title
| --------------------------------- |
|             . - ~ - .             |  Outer circular graduated ring
|         . '           ' .         |
|       /                   \       |
|      |        [ 65% ]      * |    |  Center Value Readout & Orbital Pip (*)
|       \                   /       |
|         . .           . .         |
|             ' - ~ - '             |
| --------------------------------- |
| < LEVER > ADJ   [PUSH] CONFIRM    |  Prompt: Lever dials, Push commits
+-----------------------------------+
```

* **Orbital Satellite Pip:** A bright circular marker orbits around the ring proportional to the active value.
* **Contextual Center Graphic:**
  * **Volume:** Emits radiating acoustic speaker arcs.
  * **Tick Duration:** Displays a digital square-wave pulse width graphic.
  * **Tone Pitch:** Displays an animated sine-wave waveform whose wavelength scales with frequency.
* **Zero Input Lag:** Turning the lever continuously adjusts the value in RAM with instant feedback.
* **Hold-to-Repeat:** Holding the lever Left or Right spins the dial smoothly at 160ms intervals.

---

### 4-Card Tactical Overview Menus

For multi-choice settings with 3–4 discrete states, ISD-Core uses a dedicated full-screen 4-card overview menu:

```text
+-----------------------------------+
| TILT TO WAKE                [ 2 ] |  Menu Title & Active Index
| --------------------------------- |
|  +-----------------------------+  |
|  | ( ) OFF                     |  |  Card 0: Manual wake only
|  +-----------------------------+  |
|  +-----------------------------+  |
|  | ( ) SENSITIVE (12 - 80 deg) |  |  Card 1: Light wrist glance
|  +-----------------------------+  |
|  +-----------------------------+  |
|  | (*) BALANCED  (22 - 72 deg) |  |  Card 2: Standard natural glance (Active)
|  +-----------------------------+  |
|  +-----------------------------+  |
|  | ( ) SLUGGISH  (35 - 65 deg) |  |  Card 3: Deliberate heavy raise
|  +-----------------------------+  |
| --------------------------------- |
| [PUSH] SELECT  < LEVER > NAV [BTN]|
+-----------------------------------+
```

* **Radio Selector (`(*)`):** An active indicator shows the currently applied setting.
* **Instant Confirmation:** Flicking the lever moves the highlight box; clicking `[PUSH]` selects the new mode and saves it to NAND flash.

---

### Cinematic Smoothstep Backlight Transitions

Rather than abruptly cutting off or ramping linearly, the display backlight fades smoothly using a mathematical **smoothstep curve**:

```text
Intensity
  100% ┼                                   .───────
       │                               . ─
       │                            . '
       │                         . '
       │                      . '
       │                   . '
       │               . '
       │          . ─ '
    0% ┴─────────'─────────────────────────────────
       0ms                   t                  FadeAnimMs
```

* **Cubic Hermite Interpolation:** $f(t) = t^2 \times (3 - 2t)$ for $t \in [0, 1]$.
* **Eye-Friendly:** Soft gradual start and end prevents optical fatigue when waking up in dark environments.
* **Customizable:** Adjust from **0 ms** (instant snap) to **2000 ms** (luxurious fade) via `Settings -> Display -> Fade Anim`.

---

## 7. Persistent Storage & Zero-Wear Policy

### How Your Settings Are Saved
All settings persist across power cuts and full battery drains on the onboard **ZDSD NAND Flash** in `/sys/config.bin`:

1. **Zero-Wear Policy:** Rotating radial dials modifies settings exclusively in RAM. Spinning a dial 1,000 times performs **0 writes** to flash, preserving NAND cell lifespan indefinitely.
2. **Commit on `[PUSH]`:** Pressing the lever down to confirm a setting flushes the new configuration to flash.
3. **Commit on Exit:** Pressing `[BTN]` to back out of a menu automatically flushes any pending changes once.
4. **Atomic Safety:** Data is written to `/sys/config.tmp` first; once fully flushed, it atomically renames to `/sys/config.bin`. If power cuts out mid-write, your previous configuration remains 100% intact.
5. **Fail-Safe Boot:** If the NAND storage is absent or corrupted, the system boots into factory defaults immediately without hanging.

### Offline PC Configuration Tool
You can inspect, backup, and modify configuration files offline using the included Python CLI tool:

```bash
# Read and inspect a config.bin file:
python tools/nx_config_tool.py read config.bin

# Export binary configuration to human-readable JSON:
python tools/nx_config_tool.py to-json config.bin -o config.json

# Compile modified JSON back to binary with verified CRC-16:
python tools/nx_config_tool.py from-json config.json -o config.bin

# Generate fresh factory default binary config:
python tools/nx_config_tool.py create-default -o config.bin
```

---

## 8. Summary Navigation Quick-Reference

| To accomplish this... | Do this from the current screen... |
| :--- | :--- |
| **Open Quickpanel** | Flick **`LEVER_RIGHT`** from Watchface HUD. |
| **Open Notifications** | Flick **`LEVER_LEFT`** from Watchface HUD. |
| **Open 3D App Menu** | Press and hold **`LEVER_PUSH` (1.2s)** on Watchface HUD. |
| **Browse App Cards** | Flick or hold **`LEVER_LEFT`** / **`LEVER_RIGHT`** in the 3D App Menu. |
| **Enter an App** | Click **`LEVER_PUSH`** on any centered hero card. |
| **Adjust Radial Dial** | Flick or hold **`LEVER_LEFT`** / **`LEVER_RIGHT`** inside any dial screen. |
| **Confirm & Save Setting** | Click **`LEVER_PUSH`** inside any dial screen or overview menu. |
| **Go Back / Exit / Save** | Press **`BTN`** (GPIO 13) at any time. |
| **Instant Screen Standby** | Open Quickpanel $\to$ `[SHUTDOWN]` $\to$ Select `STANDBY`. |
| **Wake from Standby** | Press **`BTN`**, flick any lever, tilt wrist (if enabled), or plug USB power. |

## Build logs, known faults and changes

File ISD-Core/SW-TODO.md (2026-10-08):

# ISD-Core Software Roadmap & Feature Specification

This document tracks implementation status across the 6 core application decks, system services, and hardware subsystems.

---

## Application Decks & Core Concepts

### 1. Vitals (Internal Physiology)
* [x] **HRM:** Spot and live optical PPG sampling (`MAX30102`)
* [x] **SpO2:** Blood oxygen calculation and perfusion index
* [x] **MSF Calculated Stress:** Autonomic stress score via RMSSD HRV analysis
* [x] **HRM Measuring Reminders:** Scheduled cyclic measurement prompts (`OFF`, `30m`, `1h`, `2h`) configured in Settings

### 2. Environment (External Ambience)
* [x] **Pressure:** Live barometric readout (`BME690` via I2C `0x76`) & 16-bar isobar history
* [x] **Temperature:** Ambient temperature sensing with capillary mercury tube & min/max bounds
* [x] **Humidity:** Relative humidity sensing with teardrop hygrometer
* [x] **Light Intensity:** Photopic ambient illuminance (`OPT3001` via I2C `0x44`/`0x45`) with 6-blade optical aperture
* [x] **Weather & Meteorological Forecast:** Dynamic vector glyphs (Sun, Partly Cloudy, Overcast, Rain, Storm), 3-hour $\Delta P/\Delta t$ gradient, Dew point fog sentinel
* [x] **3D Vector Earth Engine:** Real-time rotating planetary wireframe with 23.4° tilt and vector continents
* [x] **6-Card Vertical Hierarchy:** Master HUD + Weather & Forecast + 4 deep-dive sensor cards with vertical sliding animation
* [x] **Tactical Side Scrollbar:** Right-edge track & position thumb (replaces cluttered bottom footer bar)
* [x] **Altimeter:** Barometric elevation calculation with relative zero and QNH calibration
* [x] **Air Quality & VOC Fusion:** NX-MSF environmental engine with moisture-compensated MOX resistance, dynamic $R_0$ baseline tracking, 0–500 IAQ index, estimated $e\text{CO}_2$ & bVOC, VOC plume sentinel, and 16-bar live sparkline graph

### 3. Clock (Temporal Operations)
* [ ] **Timer:** Countdown timer with progress bar and acoustic/NPM alert
* [ ] **Stopwatch:** Millisecond chronograph with lap logging
* [ ] **World Clock:** Dual UTC / time-zone offset tracking
* [ ] **Alarms:** Battery-backed hardware alarms via `RV-3028` interrupt line
* [x] **Date, Time & Timezone Sync:** High-accuracy RTC timekeeping on Watchface HUD (`RV-3028` via I2C `0x52`)
* [x] **NAND State Persistence:** Storage subsystem ready to persist clock/alarm states

### 4. Device (Silicon & Hardware Integrity)
* [x] **Battery Info:** Real-time cell voltage, capacity percentage, charge/discharge rate via `MAX17048` (`0x36`)
* [ ] **Deep Battery Analytics:** Charge cycle tracking, runtime estimation, and cell internal resistance ($R_{\text{int}}$)
* [ ] **NX-SDS (Self-Diagnostic System):** Continuous I2C 9-clock recovery, hardware proof-testing, and audit logging (`/sds/audit_log.txt`)
* [x] **Storage Subsystem:**
  * [x] Onboard ZDSD NAND Flash driver (`CS_SD = GPIO 47`) over high-speed SPI
  * [x] 64-byte packed binary struct (`/sys/config.bin`) with CRC-16 CCITT validation
  * [x] Zero-wear save policy (RAM-only dialing, write on `[PUSH]` confirmation or menu exit)
  * [x] Atomic staging writes (`/sys/config.tmp` $\to$ `/sys/config.bin`)
  * [x] Standalone PC inspection & JSON conversion CLI tool (`tools/nx_config_tool.py`)
* [ ] **Firmware Version & OTA Updates:** Wireless OTA sync via [NX-Uplink](https://nx-uplink.base44.app)

### 5. Tools (Tactical & Field Operations)
* [x] **Spirit Level:** 2D interactive bubble level reticle driven by `BNO085` accelerometer on Watchface HUD
* [ ] **Dedicated Spirit Level App:** Fullscreen precision leveling with numeric pitch/roll angles
* [ ] **WiFi Analysis:** 2.4 GHz channel scan and RSSI meter
* [ ] **BLE Analysis:** BLE advertisement detection and proximity RSSI tracking
* [ ] **ESP-Deauth:** Wireless penetration testing / network resilience tool
* [x] **NX-Uplink Bridge:** Companion serial/wireless packet protocol framework
* [ ] **Oracle Network Integration:** Web3 / decentralized oracle bridge ([oracle-network.tech](https://oracle-network.tech))

### 6. Settings (System Orchestration) — *Fully Implemented*
* [x] **6-Category Architecture:** Strict 4-box viewport with custom vertical scrollbar track and thumb
* [x] **Display Settings:**
  * [x] Manual Dimming: 360° circular radial dial with orbital satellite pip (10% to 100% in 5% steps)
  * [x] Automatic Dimming: Real-time photopic light scaling via `OPT3001`
  * [x] Tilt to Wake: Dedicated 4-card overview menu (`OFF`, `SENSITIVE`, `BALANCED`, `SLUGGISH`)
  * [x] Display Timeout: 360° circular radial dial (5s to 300s, or `NEVER` / Always On)
  * [x] Wrist Cover Standby: Optical occlusion sleep gesture toggle
  * [x] Backlight Fade Animation: 360° circular radial dial (0ms to 2000ms in 50ms steps) with smoothstep ($t^2 \times (3 - 2t)$) curve for waking and sleeping
* [x] **Notification Settings:**
  * [x] Delivery Method: Dedicated 4-card overview menu (`SILENT`, `ALL`, `SOUND ONLY`, `LIGHTS ONLY`)
  * [x] Matrix LED Flashing: Toggle 4×4 NeoPixel optical alerts
  * [x] HRM Reminder Interval: Cycle reminder frequency (`OFF`, `30m`, `1h`, `2h`)
* [x] **Power Save Mode:**
  * [x] Eco Mode: CPU throttling and reduced sensor polling
  * [x] Auto Standby: Automatic screen sleep on inactivity timeout
  * [x] Sensor Sleep: Power down IMU/environmental rails during standby
* [x] **Buzzer Settings (Acoustic Orchestration):**
  * [x] Master Audio Mute/Unmute toggle
  * [x] Volume: 360° circular radial dial with soundwave arcs (10% to 100% duty cycle)
  * [x] Tick Duration: 360° circular radial dial with square-wave pulse width graphic (2ms to 30ms)
  * [x] Tone Pitch: 360° circular radial dial with animated sine wave graphic (1600 Hz to 4400 Hz in 100 Hz steps)
* [x] **NPM Settings (4×4 NeoPixel Matrix):**
  * [x] High-Side PMOS Power Gate Toggle (`GPIO 17`, 0µA standby cutoff)
  * [x] Brightness: 360° circular radial dial with matrix icon (10% to 100%)
  * [x] Real-Time Animation Selector (`RADAR`, `RAIN`, `PLASMA`, `TRACER`, `BREATH`, `OFF`)
  * [x] Test Pulse: Immediate high-vis amber verification strobe
* [x] **NX-AIS Settings:**
  * [x] Background Co-Processor Supervisor toggle
  * [x] Adaptive Environmental Context toggle
  * [x] Sensor Diagnostics check

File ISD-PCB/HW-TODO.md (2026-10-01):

# NX-ISD PCB Revision TODO

Upcoming hardware revision tasks for the NX-ISD PCB.

## v1p1

* [x] Change the LDO to a DC/DC buck converter
* [x] Fix PMOS direction for high-side `VN` switching
* [x] Change to the new USB-C port
* [x] Adjust the board size for a 1200 mAh battery
* [x] Change the NeoPixel matrix from 3x3 to 4x4

## v1p3

* [x] Add a level shifter for the display SPI interface
* [x] Add a level shifter for the HRM I2C interface
* [x] Change the resistor network to a smaller footprint
* [x] Perform the overall layout changes
* [x] Move the DC/DC buck converter
* [x] Reposition the RTC and add the required capacitors
* [x] Reposition the battery fuel gauge
* [x] Change silkscreen font to cyberpunk style
* [x] Add LiPo polarity marks

## v1p4

* [ ] Fix the version tag position on the bottom silkscreen
* [ ] Reposition the left-side mounting hole
* [ ] Fix Lever button wiring
* [ ] Move FPC-connector for the display a bit to the left
* [ ] Fix BQ25170 Overheating problem at 600mA charging
* [ ] Change EP pad vias of MAX17048 & BQ25170 to 0.45mm drill to reduce pcb costs
* [ ] Clear 2V8 path
* [ ] add hardware pull up to BTN

## v1p5

* [ ] Change OPT3001 for a multispectral light sensor

## Future Ideas for a vXpY

> NOTE: The higher up a point is the more likely I m planning to integrate it in a future verison.

* [ ] PCB varient for SD-CARD isntead of Nand flash?
* [ ] Full speed flash storage, SD mode instead of pure SPI?
* [ ] Add infrared transceiver and receiver?
* [ ] MEMS Microphone?
* [ ] Add I2C Secure Element (e.g., ATECC608B)?
* [ ] Change to dual MCU architecture (ESP32 & NRF52)?
* [ ] Add bright LED at the Sensor head: Flashlight usage?
* [ ] Add Lidar?
* [ ] Add NFC?
* [ ] Wireless charging coil at second plate under battery?

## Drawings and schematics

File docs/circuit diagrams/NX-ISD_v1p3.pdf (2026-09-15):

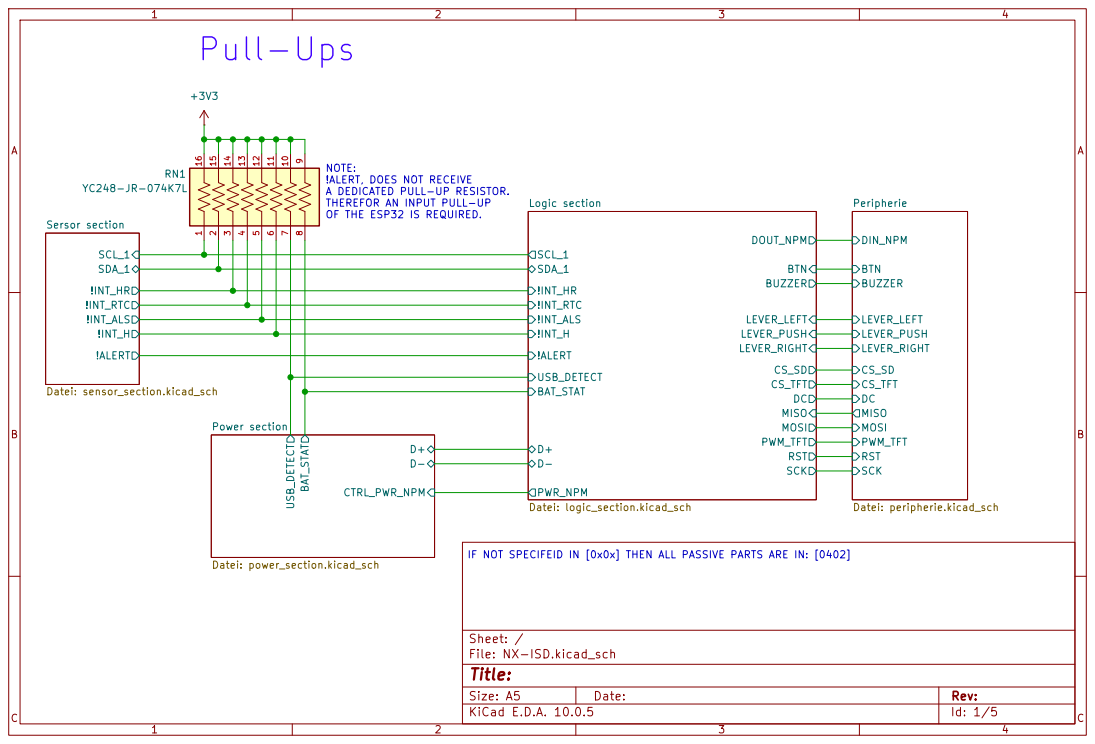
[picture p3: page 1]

IF NOT SPECIFEID IN [0x0x] THEN ALL PASSIVE PARTS ARE IN: [0402] NOTE:
!ALERT, DOES NOT RECEIVE A DEDICATED PULL-UP RESISTOR.

THEREFOR AN INPUT PULL-UP OF THE ESP32 IS REQUIRED.

LEVER_LEFT LEVER_PUSH
CS_TFT DC MISO MOSI PWM_TFT RST SCK

CS_TFT DCMISO MOSI PWM_TFT RST SCK

Size: A5 | Rev: | C Date:
KiCad E.D.A. 10.0.5 | Id: 1/5

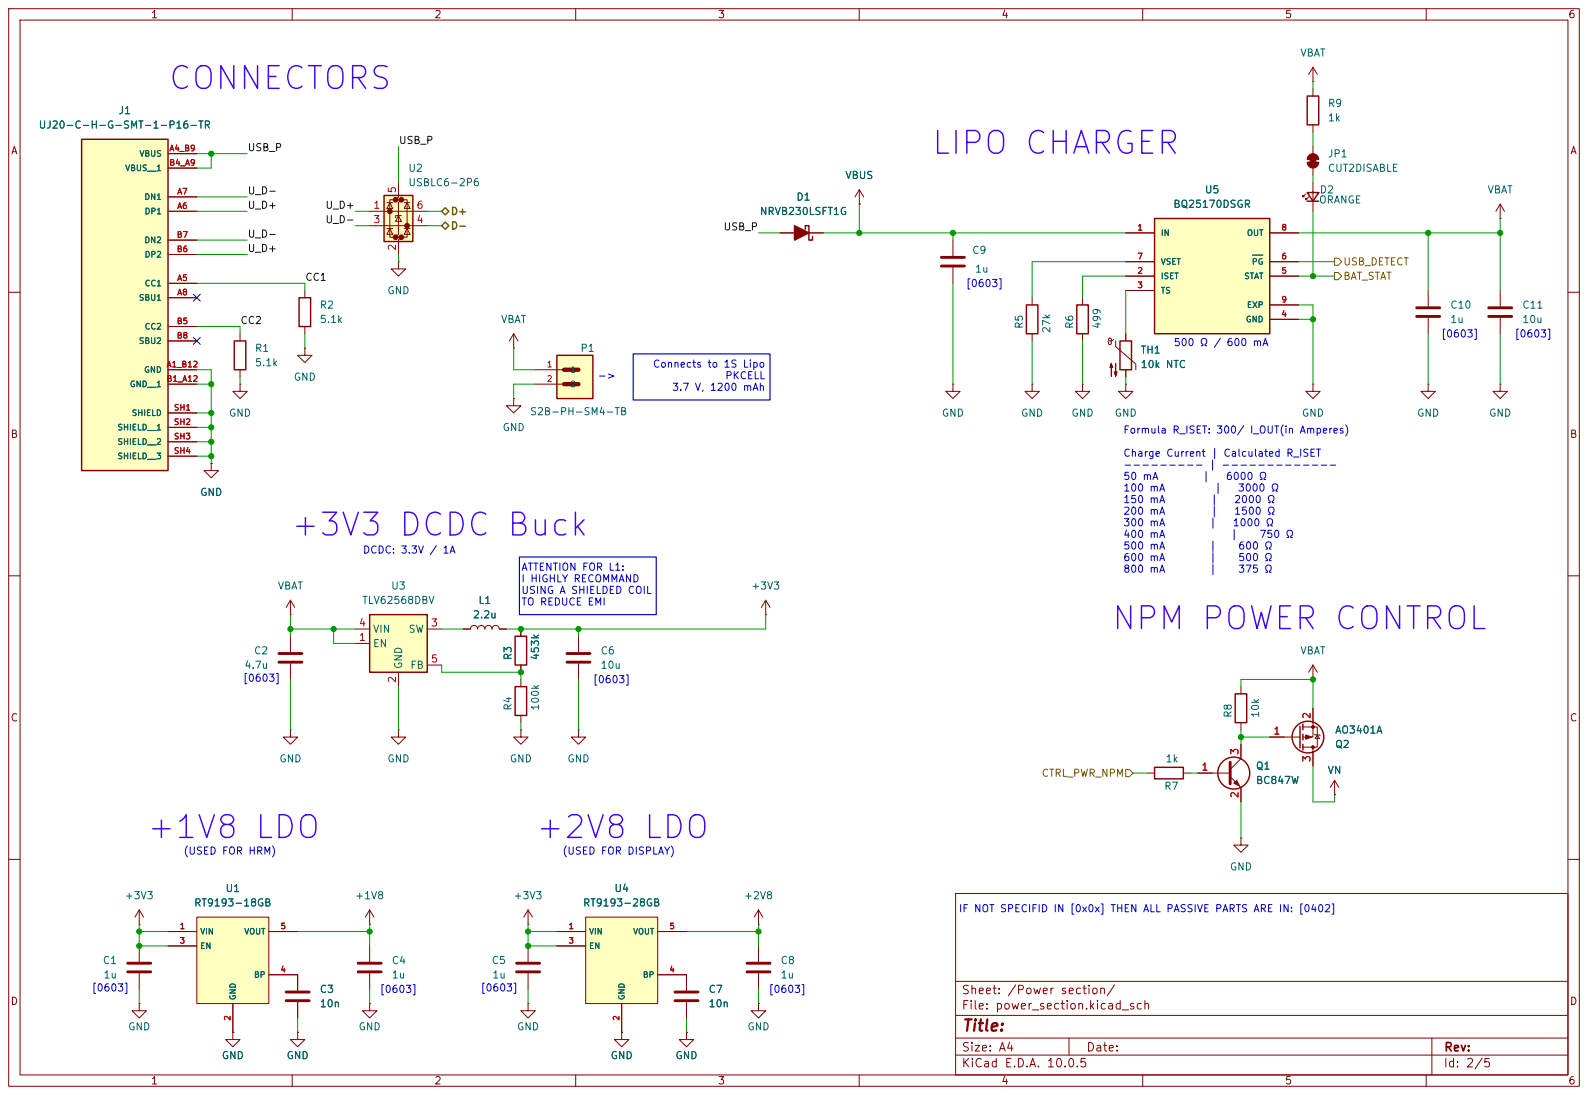
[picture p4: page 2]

ATTENTION FOR L1:
I HIGHLY RECOMMAND USING A SHIELDED COIL

IF NOT SPECIFID IN [0x0x] THEN ALL PASSIVE PARTS ARE IN: [0402]

Size: A4 | Rev:
KiCad E.D.A. 10.0.5 | Id: 2/5

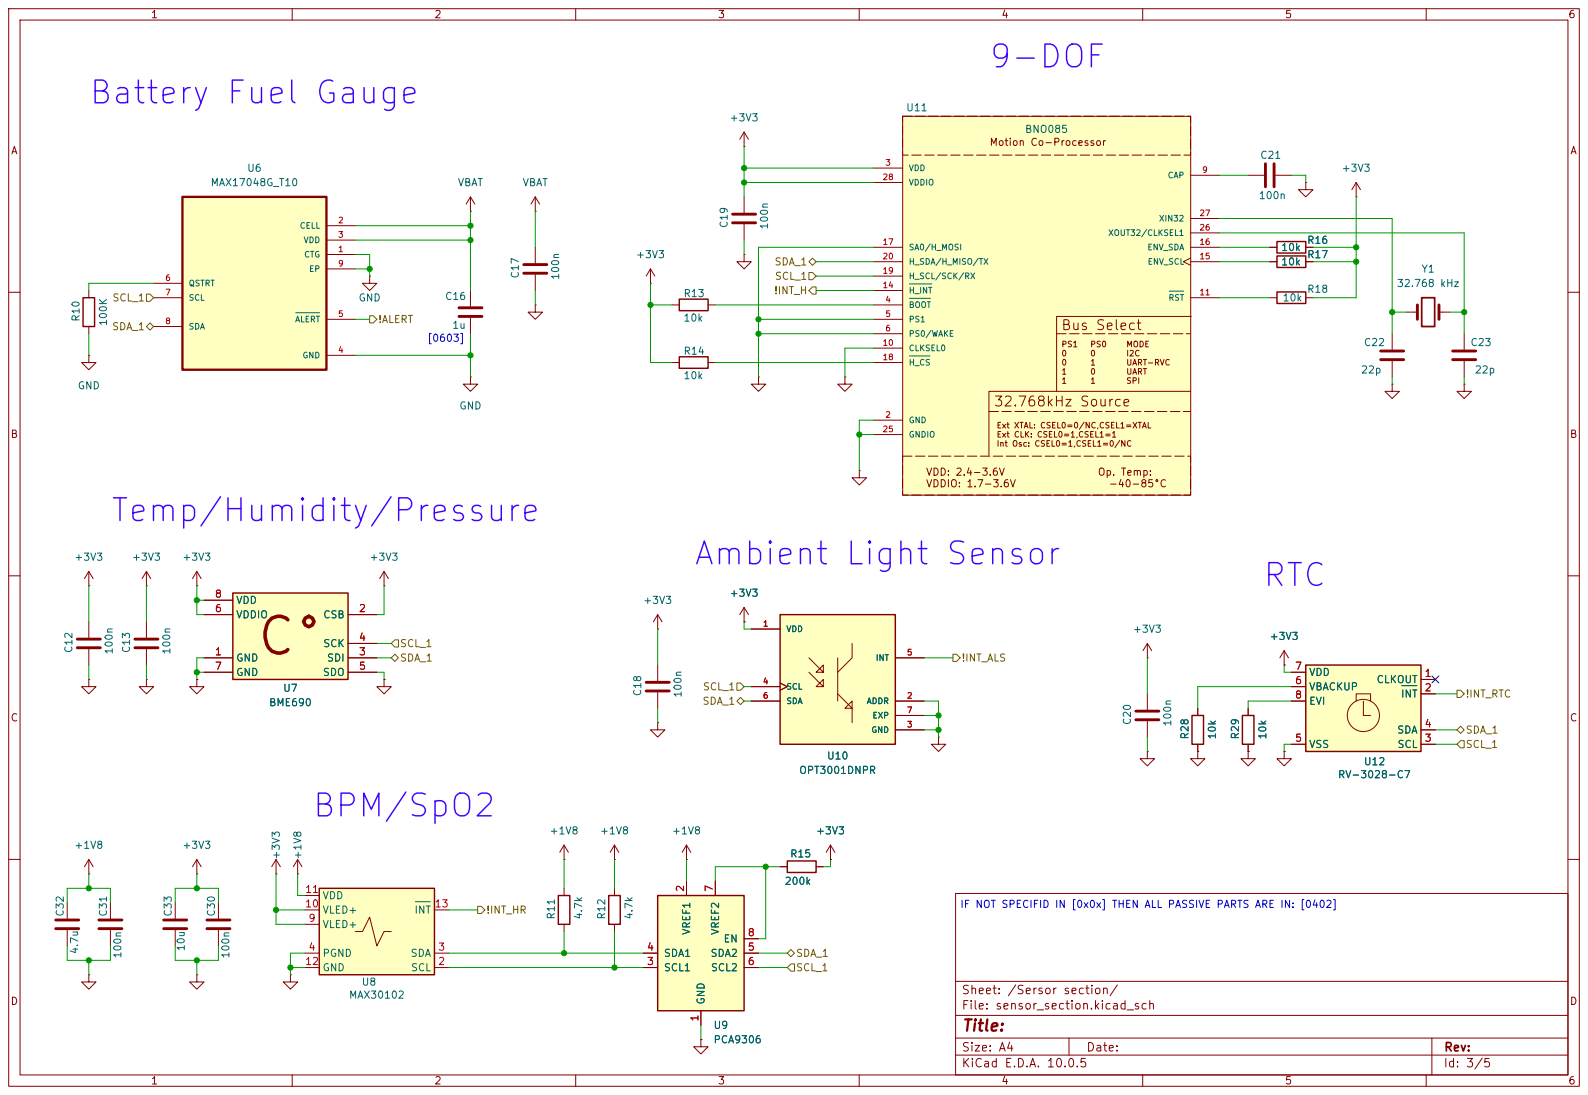
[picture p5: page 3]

9-DOF
Int Osc: CSEL0=1,CSEL1=0/NC Motion Co-Processor Bus Select PS1

I2C UART-RVC UART SPI GND 2

Ext XTAL: CSEL0=0/NC,CSEL1=XTAL Ext CLK: CSEL0=1,CSEL1=1

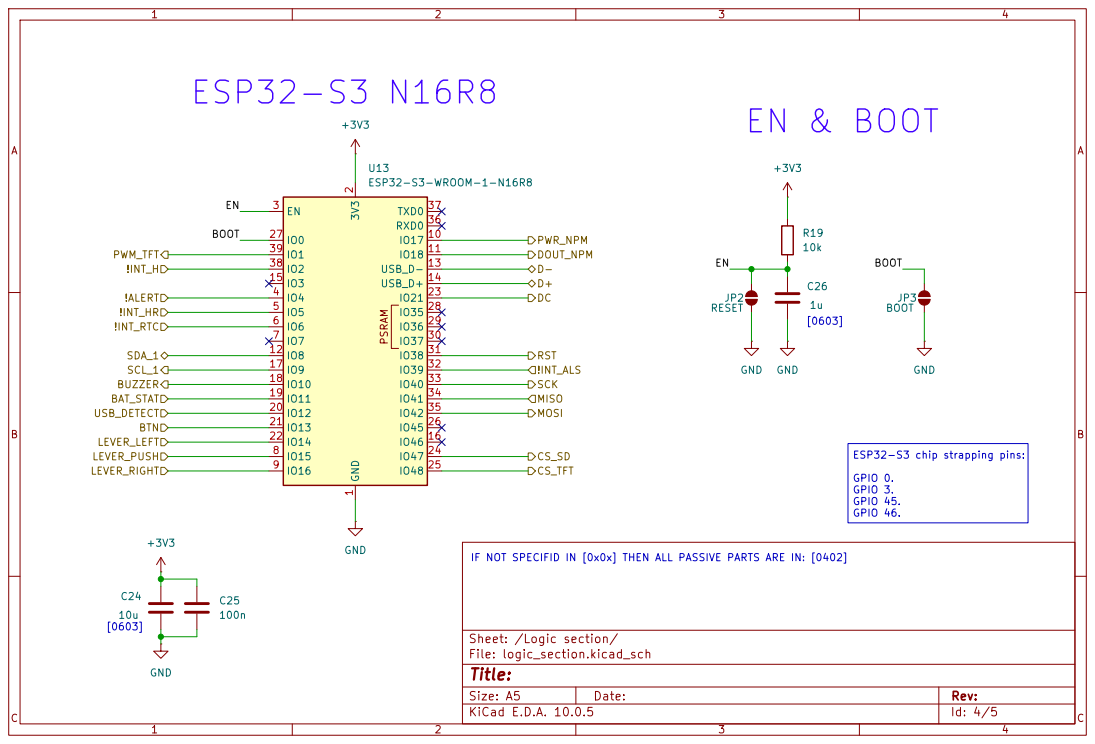
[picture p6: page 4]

[0603] ESP32-S3 chip strapping pins: GPIO 0. GPIO 3. GPIO 45. GPIO 46.

IF NOT SPECIFID IN [0x0x] THEN ALL PASSIVE PARTS ARE IN: [0402]

Size: A5 | Rev: | C Date:
KiCad E.D.A. 10.0.5 | Id: 4/5

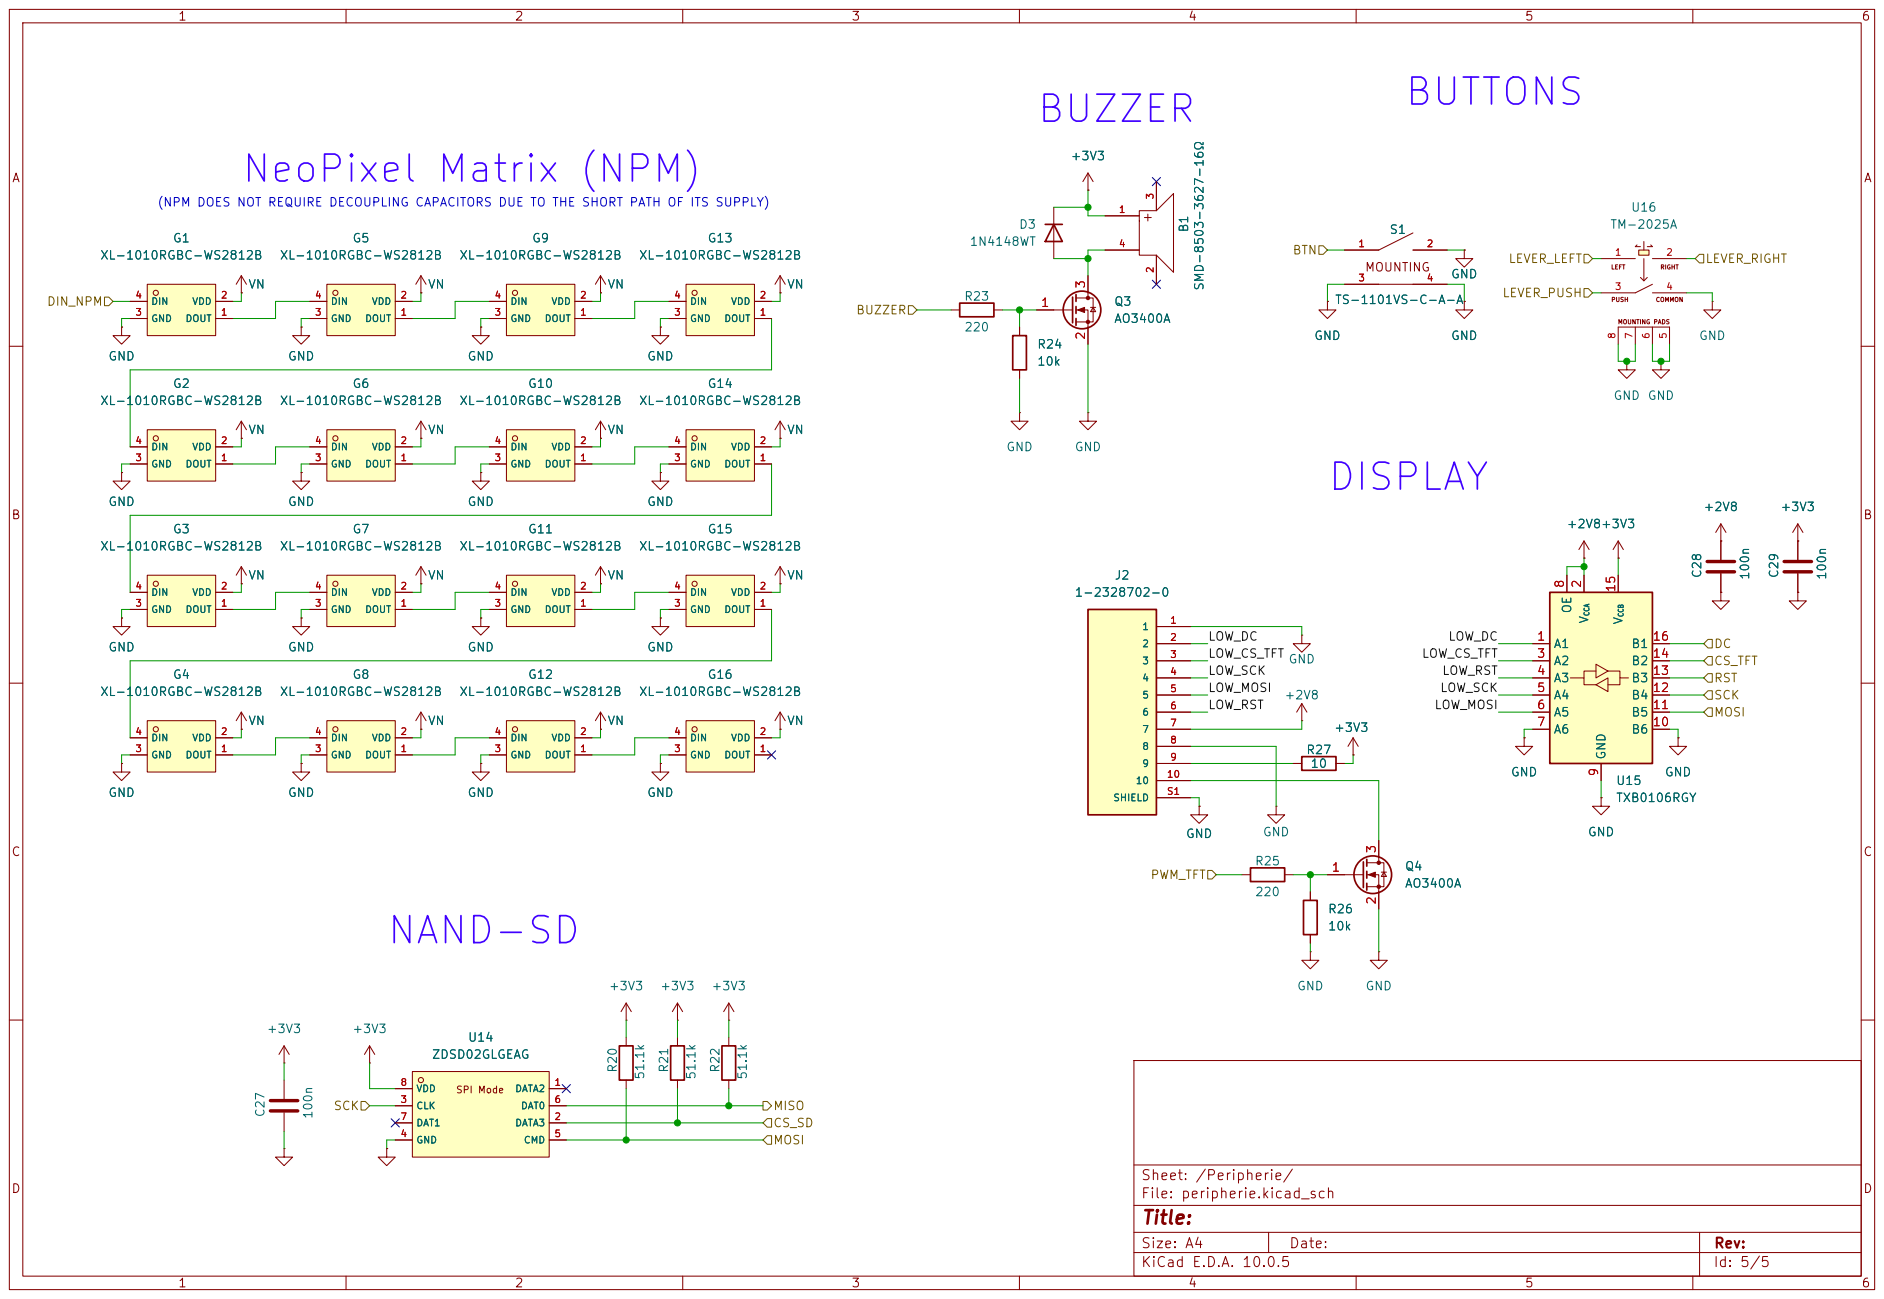
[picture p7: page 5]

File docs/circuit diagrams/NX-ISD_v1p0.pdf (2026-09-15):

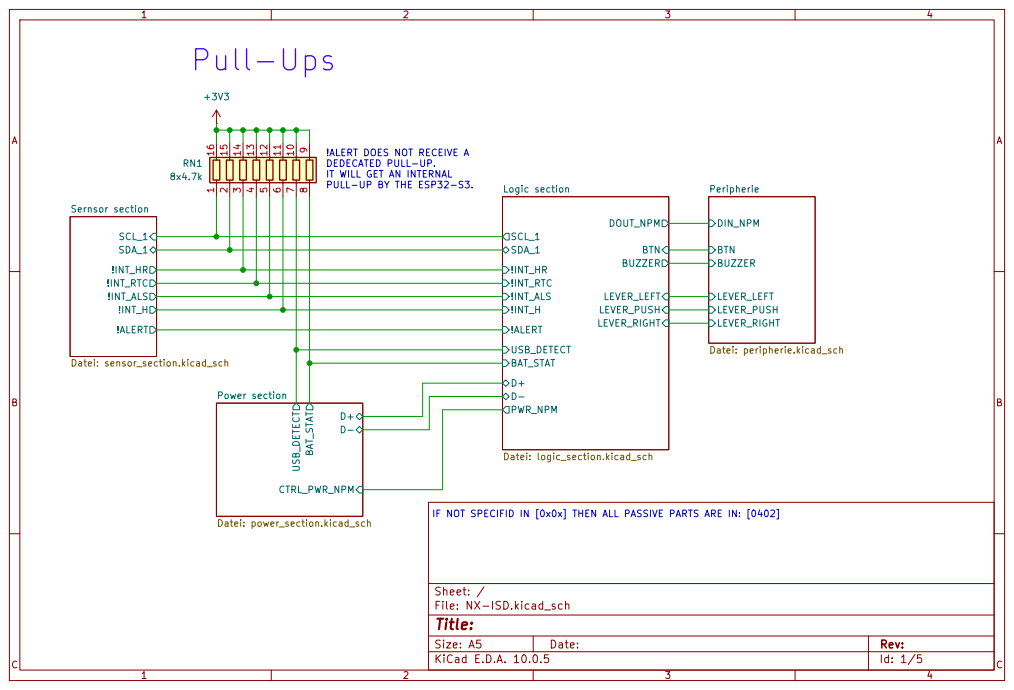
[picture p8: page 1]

!ALERT DOES NOT RECEIVE A DEDECATED PULL-UP.

IT WILL GET AN INTERNAL PULL-UP BY THE ESP32-S3.

IF NOT SPECIFID IN [0x0x] THEN ALL PASSIVE PARTS ARE IN: [0402]

Size: A5 | Rev: | C Date:
KiCad E.D.A. 10.0.5 | Id: 1/5

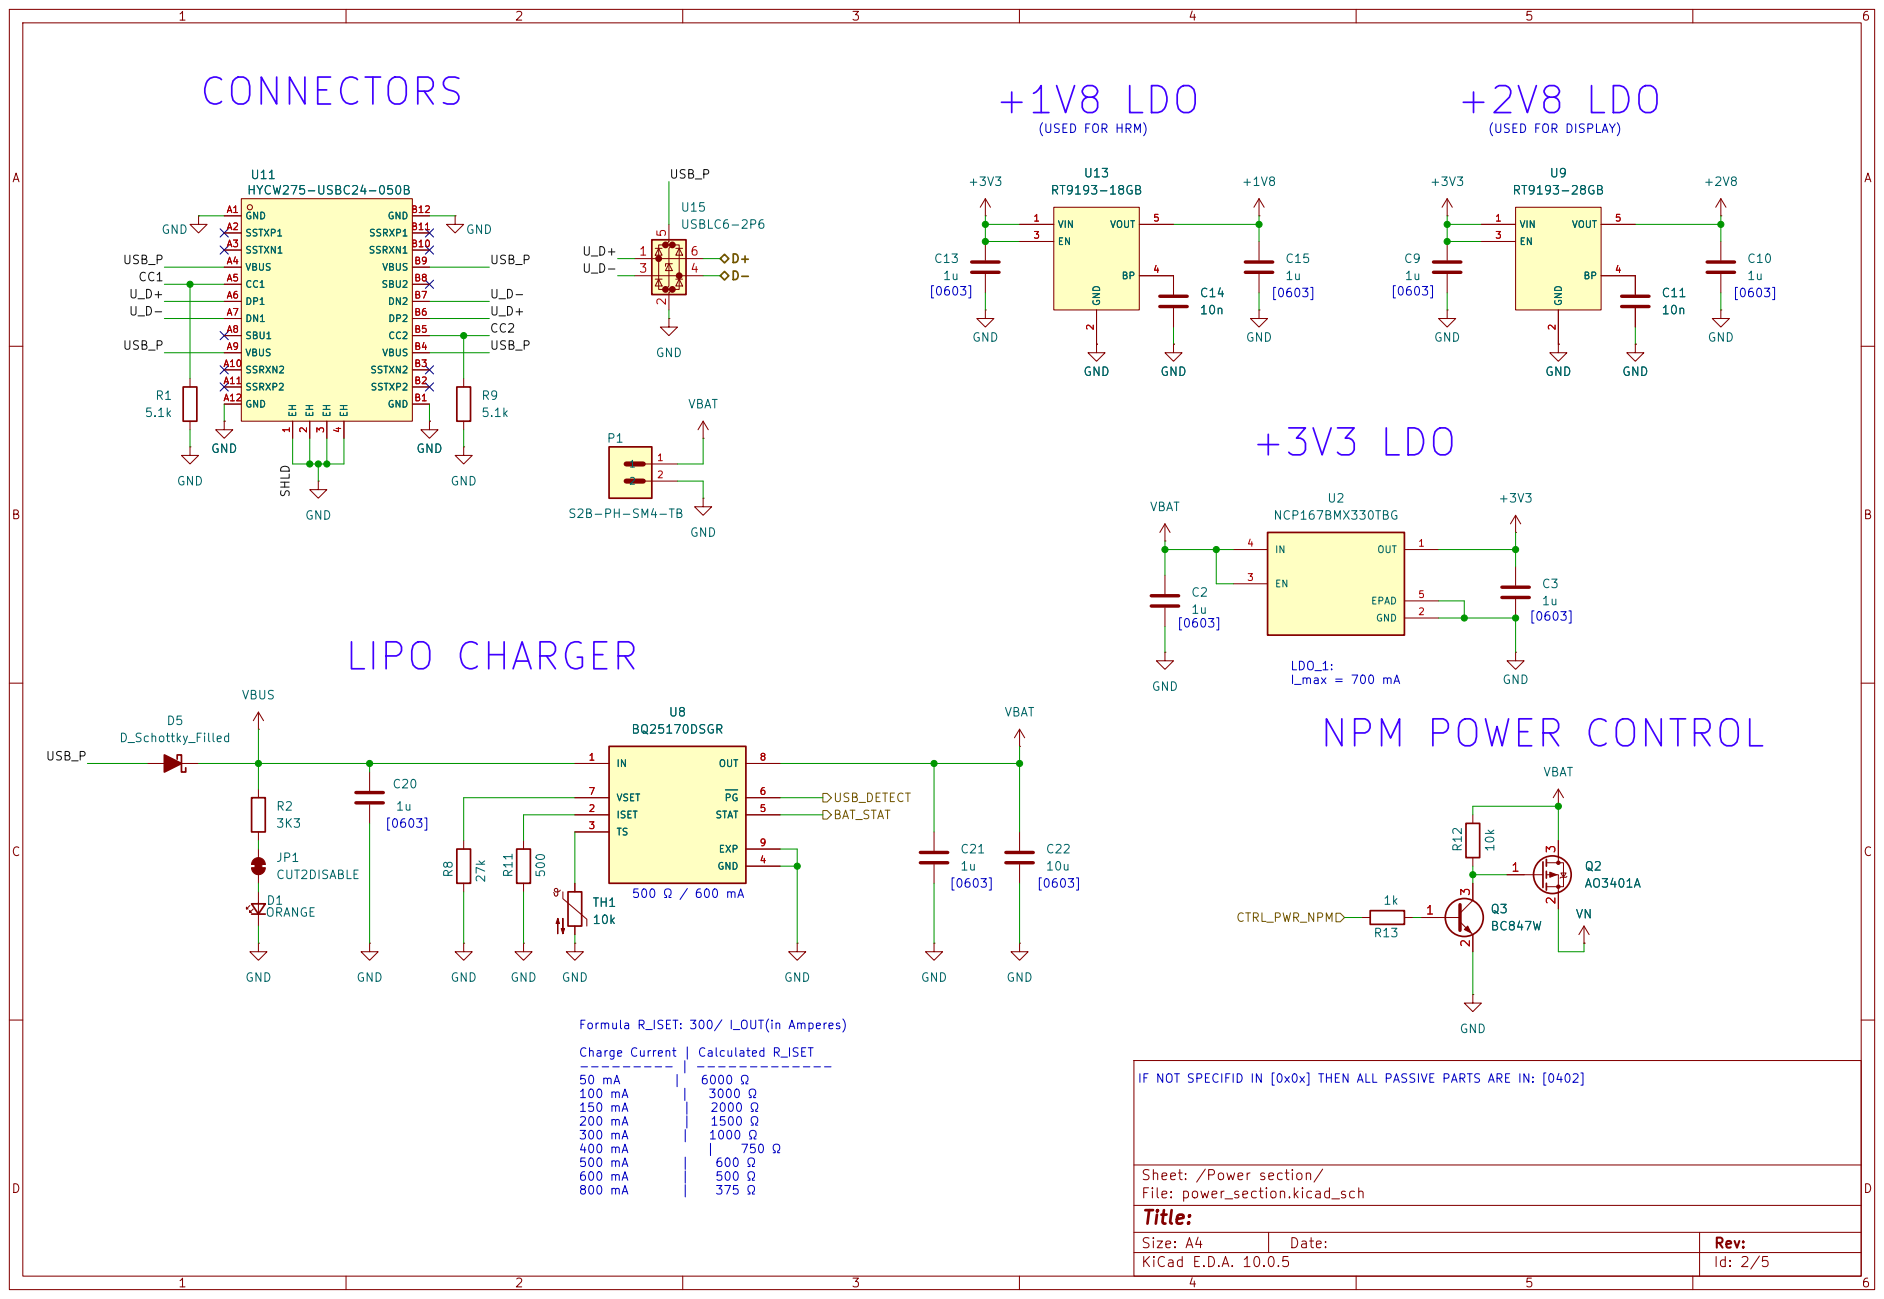
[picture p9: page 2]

IF NOT SPECIFID IN [0x0x] THEN ALL PASSIVE PARTS ARE IN: [0402]

Size: A4 | Rev:
KiCad E.D.A. 10.0.5 | Id: 2/5

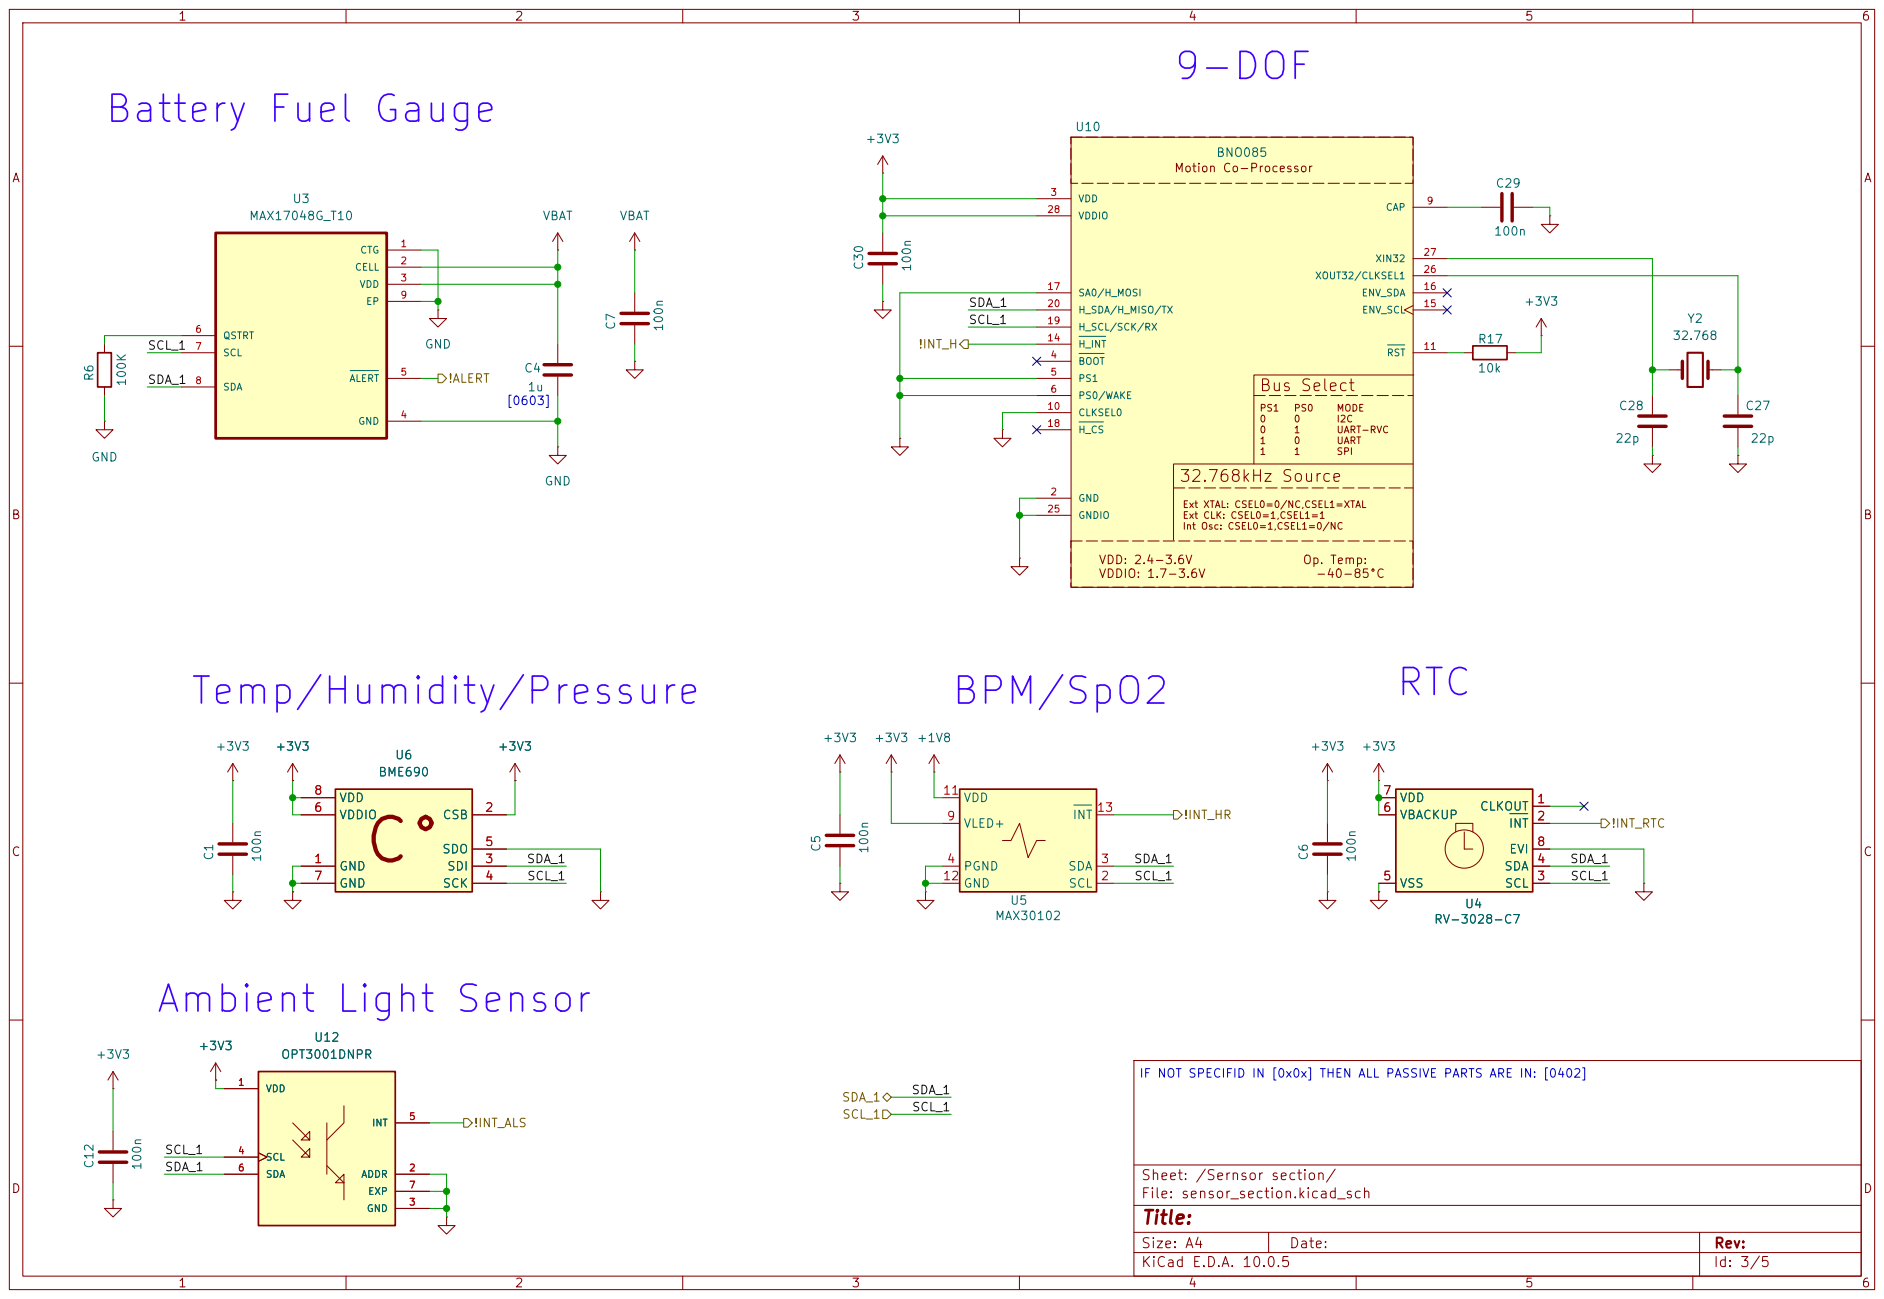
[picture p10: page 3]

Int Osc: CSEL0=1,CSEL1=0/NC Motion Co-Processor Bus Select PS1

I2C UART-RVC UART SPI GND 2

Ext XTAL: CSEL0=0/NC,CSEL1=XTAL Ext CLK: CSEL0=1,CSEL1=1

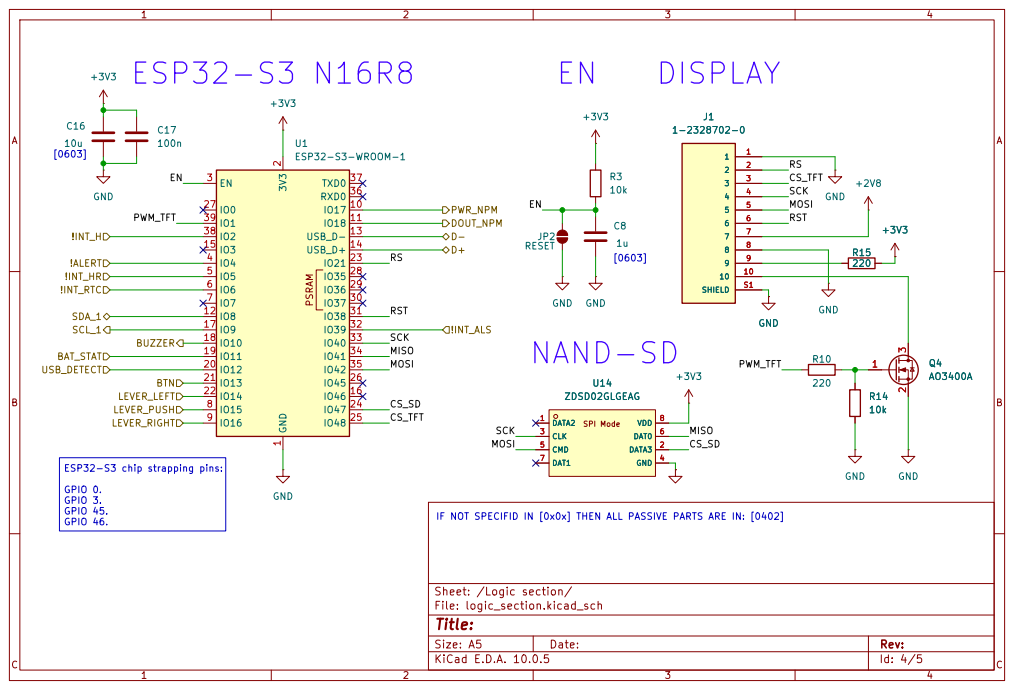
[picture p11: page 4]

IF NOT SPECIFID IN [0x0x] THEN ALL PASSIVE PARTS ARE IN: [0402]

Size: A5 | Rev: | C Date:
KiCad E.D.A. 10.0.5 | Id: 4/5

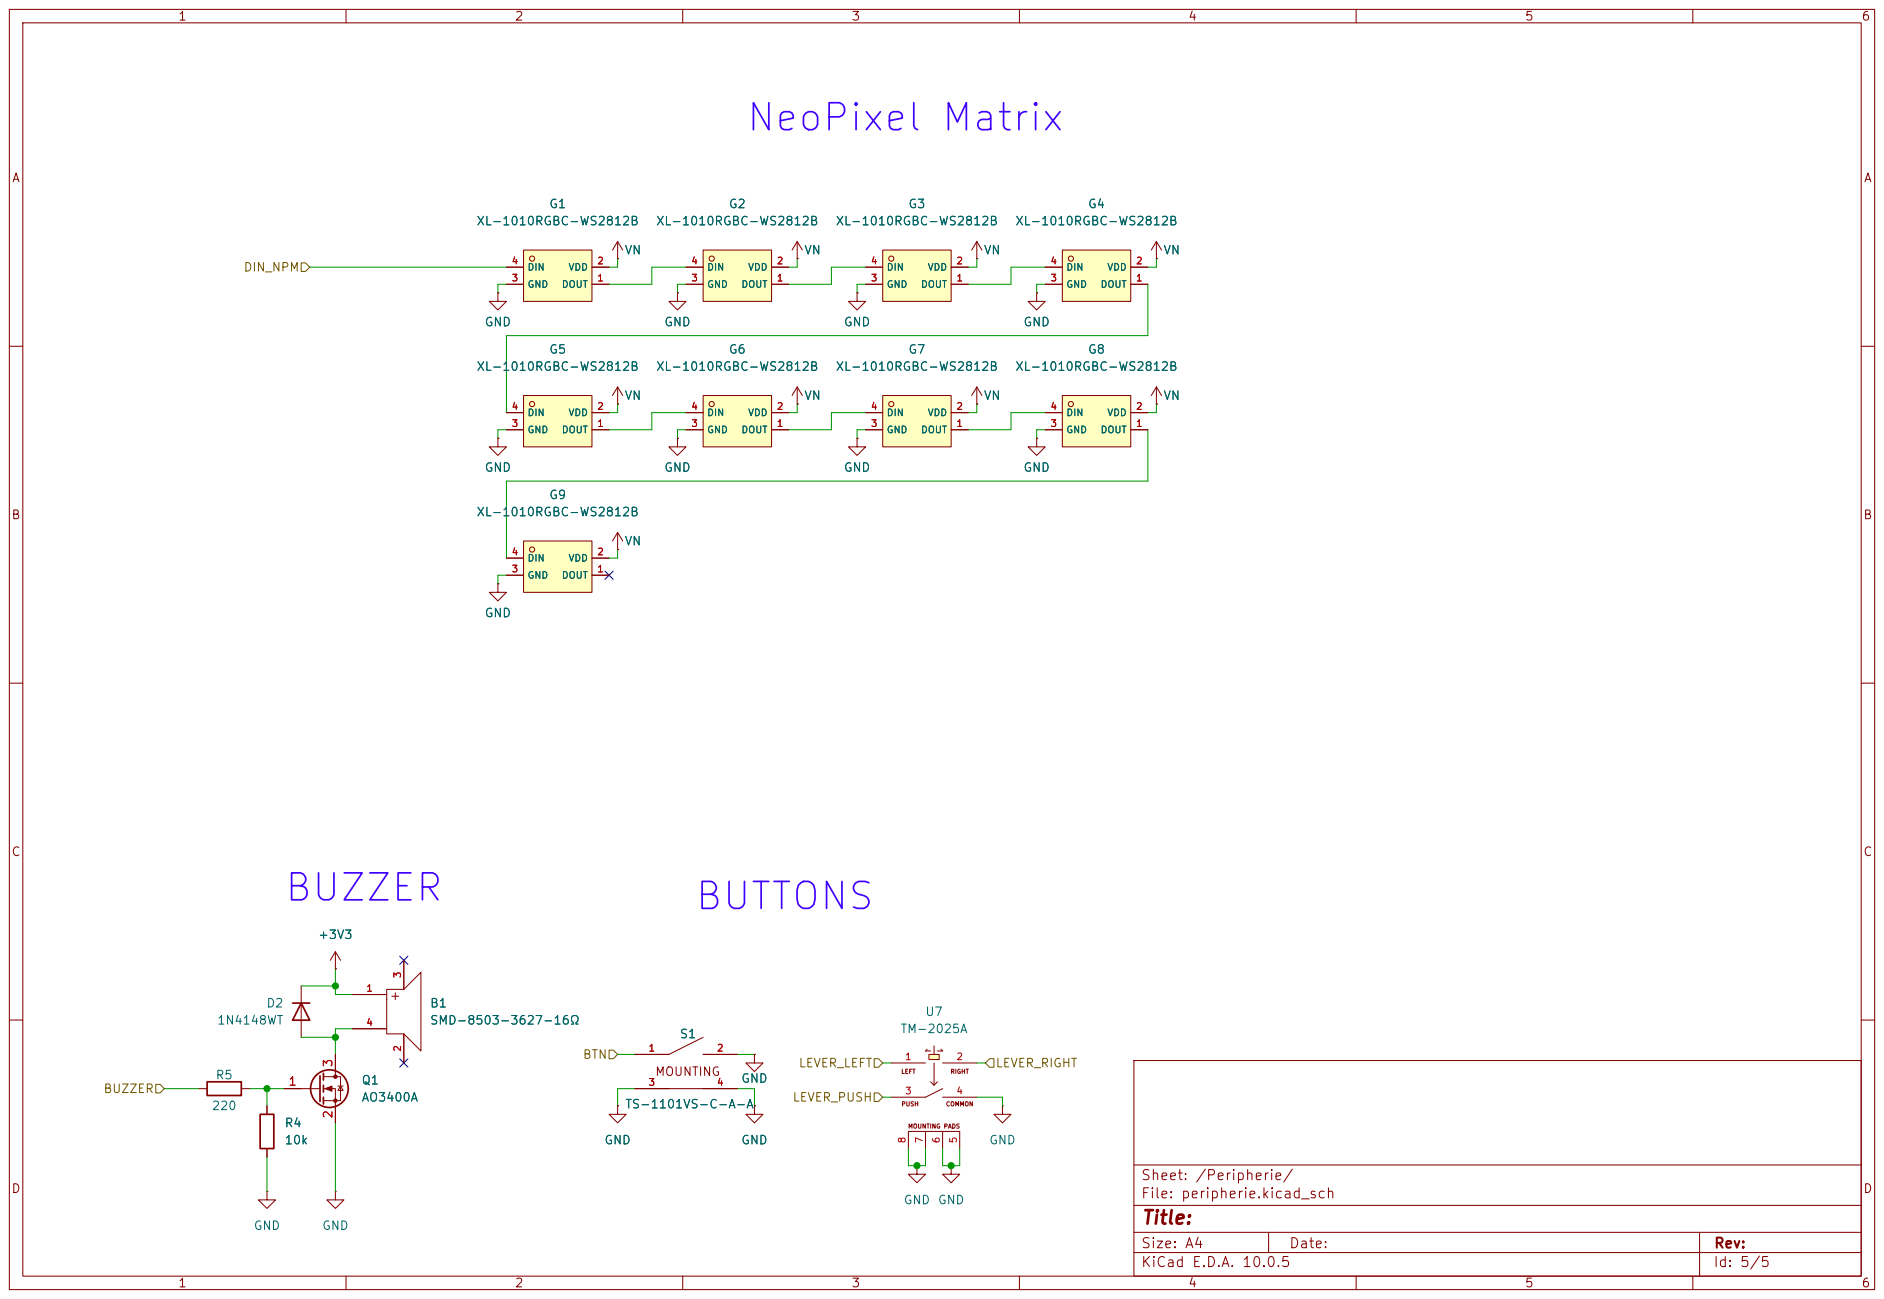
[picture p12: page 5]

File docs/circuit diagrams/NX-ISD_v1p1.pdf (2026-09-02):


!ALERT DOES NOT RECEIVE A DEDECATED PULL-UP.

IT WILL GET AN INTERNAL PULL-UP BY THE ESP32-S3.

IF NOT SPECIFID IN [0x0x] THEN ALL PASSIVE PARTS ARE IN: [0402]

Size: A5 | Rev: | C Date:
KiCad E.D.A. 10.0.5 | Id: 1/5

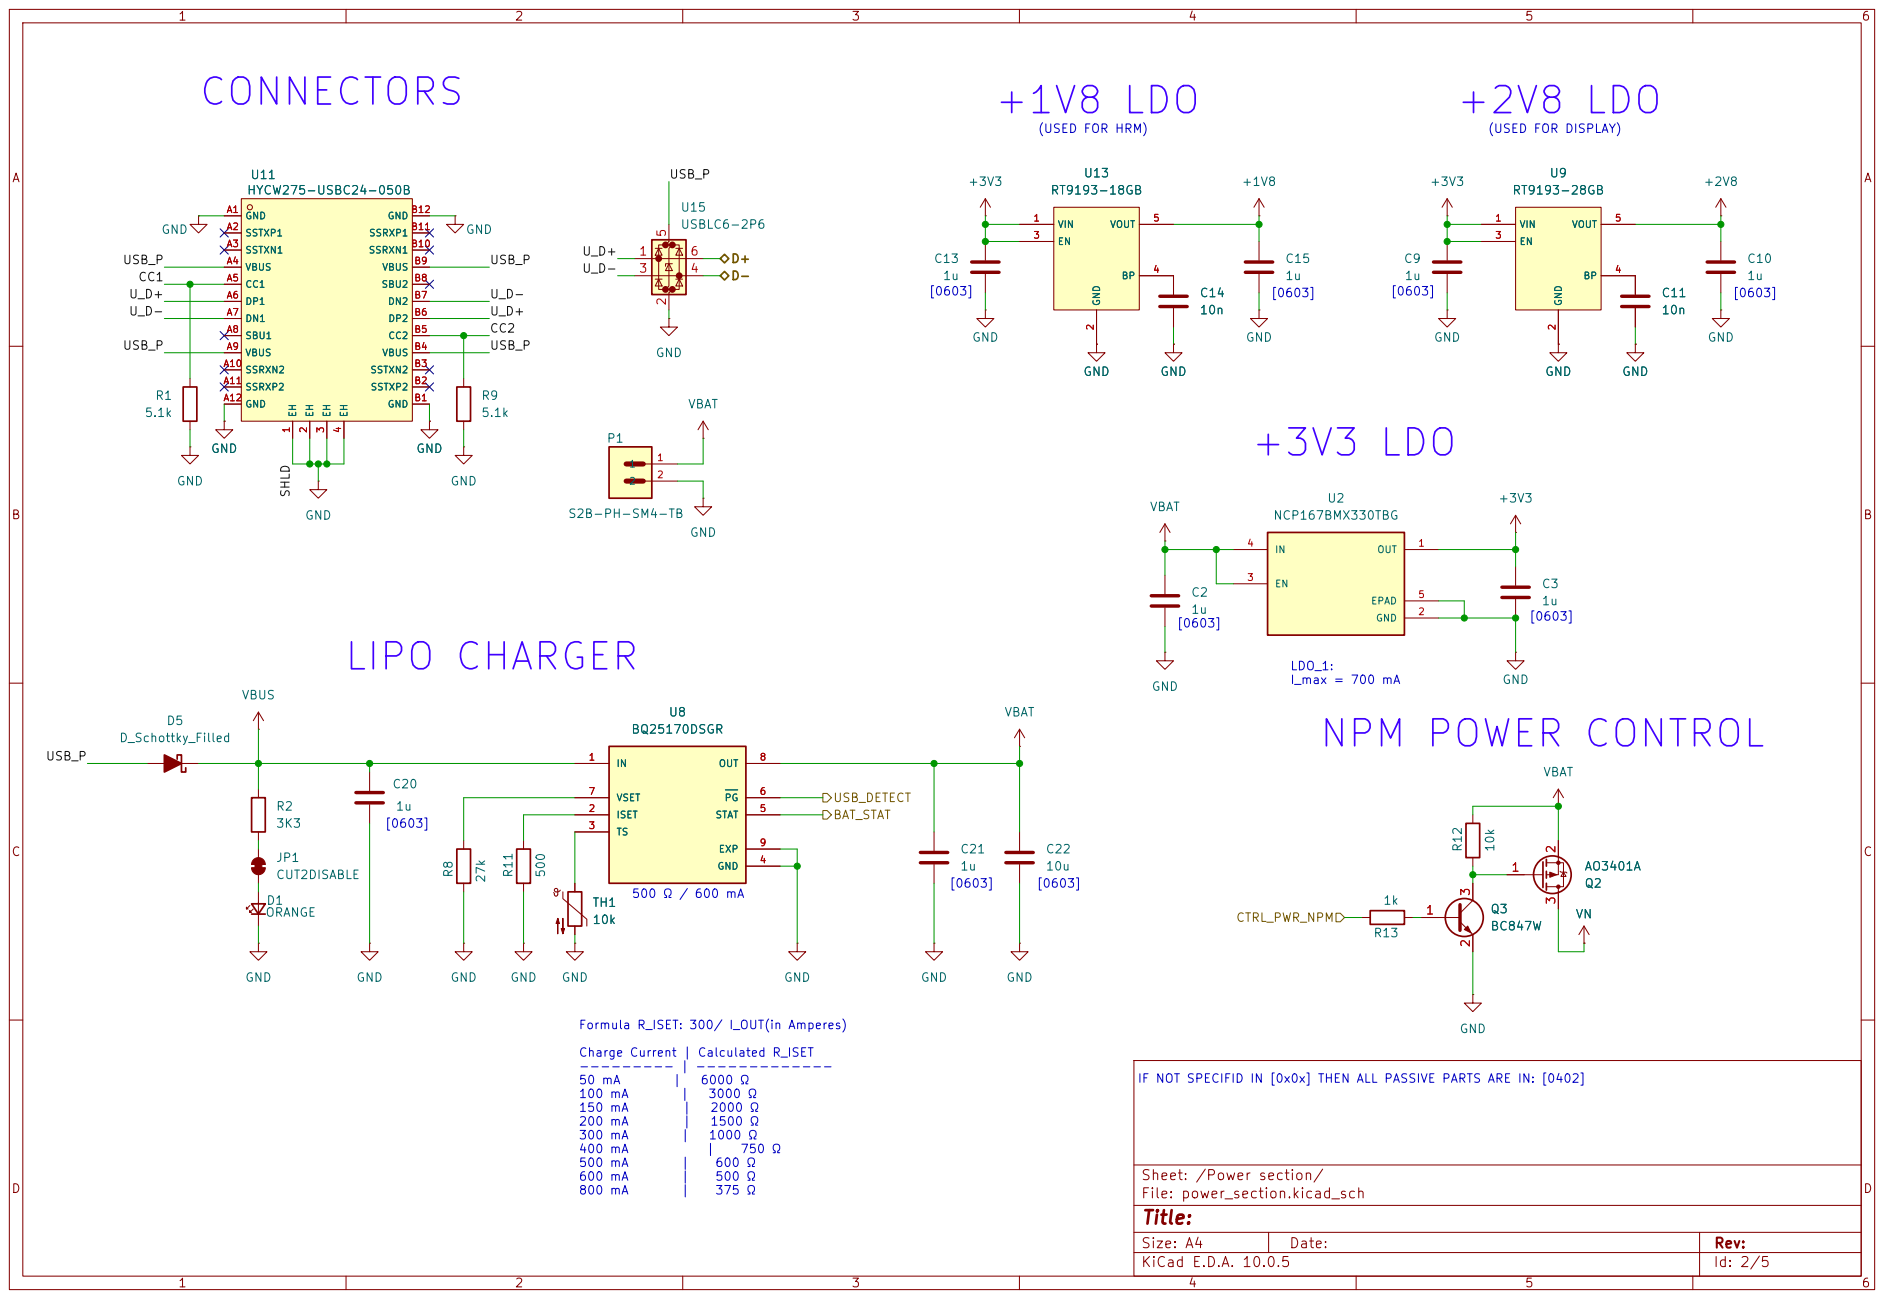
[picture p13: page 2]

IF NOT SPECIFID IN [0x0x] THEN ALL PASSIVE PARTS ARE IN: [0402]

Size: A4 | Rev:
KiCad E.D.A. 10.0.5 | Id: 2/5

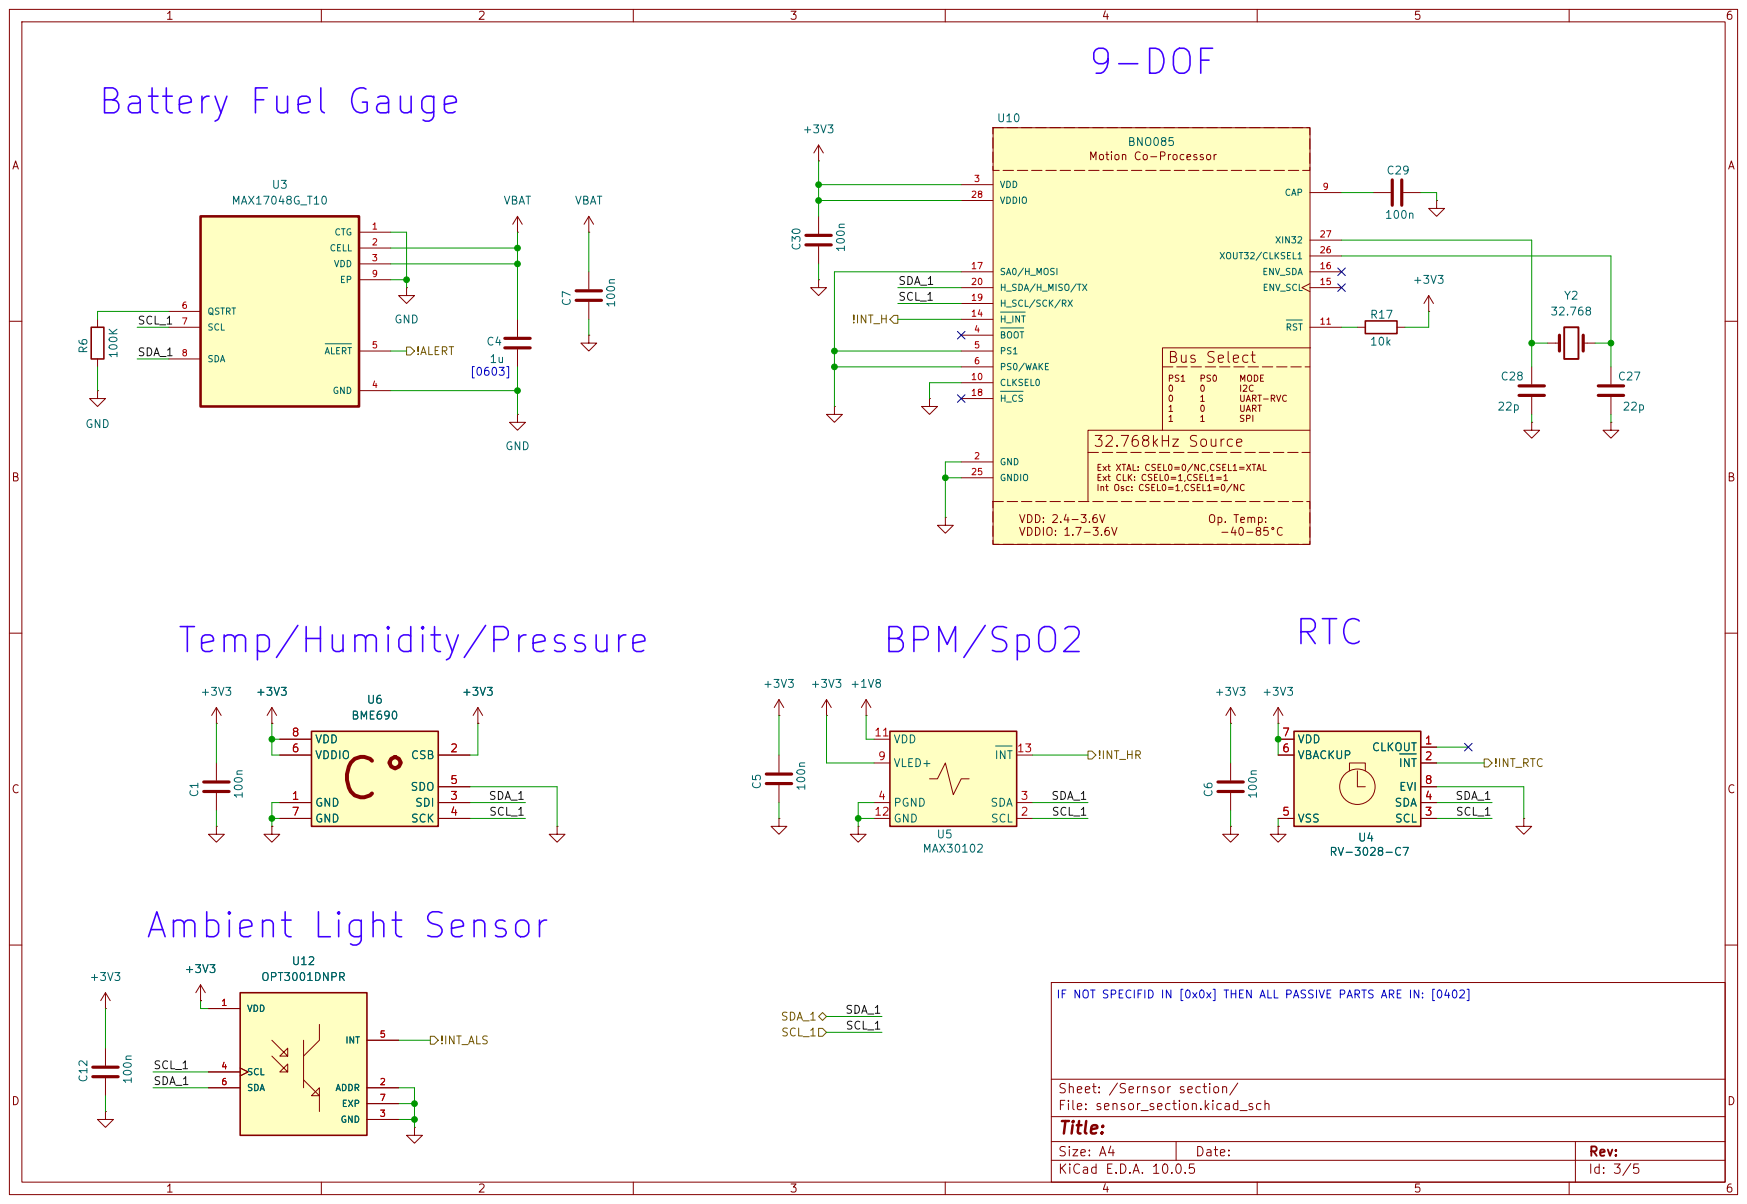
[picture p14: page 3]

Int Osc: CSEL0=1,CSEL1=0/NC Motion Co-Processor Bus Select PS1

I2C UART-RVC UART SPI GND 2

Ext XTAL: CSEL0=0/NC,CSEL1=XTAL Ext CLK: CSEL0=1,CSEL1=1


IF NOT SPECIFID IN [0x0x] THEN ALL PASSIVE PARTS ARE IN: [0402]

Size: A5 | Rev: | C Date:
KiCad E.D.A. 10.0.5 | Id: 4/5


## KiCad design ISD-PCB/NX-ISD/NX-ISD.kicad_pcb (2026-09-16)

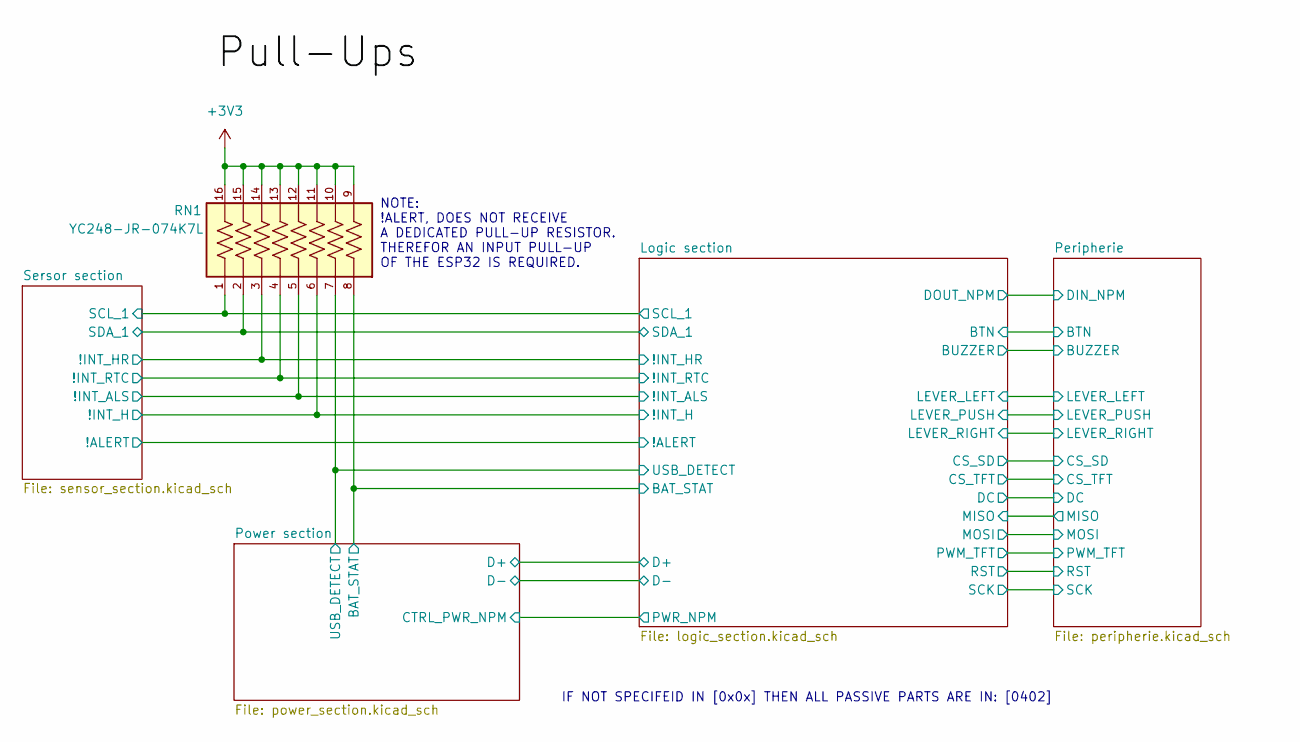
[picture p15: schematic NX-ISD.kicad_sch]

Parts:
RN1: YC248-JR-074K7L; RESCAXS50P400X160X55-16N; PARTREV V1.0

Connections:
+3V3: RN1.9, RN1.10, RN1.11, RN1.12, RN1.13, RN1.14, RN1.15, RN1.16; also elsewhere on the board
/Logic section/!INT_ALS: RN1.5; also elsewhere on the board
/Logic section/!INT_H: RN1.6; also elsewhere on the board
/Logic section/!INT_HR: RN1.3; also elsewhere on the board
/Logic section/!INT_RTC: RN1.4; also elsewhere on the board
/Logic section/BAT_STAT: RN1.8; also elsewhere on the board
/Logic section/SCL_1: RN1.1; also elsewhere on the board
/Logic section/SDA_1: RN1.2; also elsewhere on the board
/Logic section/USB_DETECT: RN1.7; also elsewhere on the board

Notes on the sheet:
IF NOT SPECIFEID IN [0x0x] THEN ALL PASSIVE PARTS ARE IN: [0402]
NOTE: !ALERT, DOES NOT RECEIVE A DEDICATED PULL-UP RESISTOR. THEREFOR AN INPUT PULL-UP OF THE ESP32 IS REQUIRED.

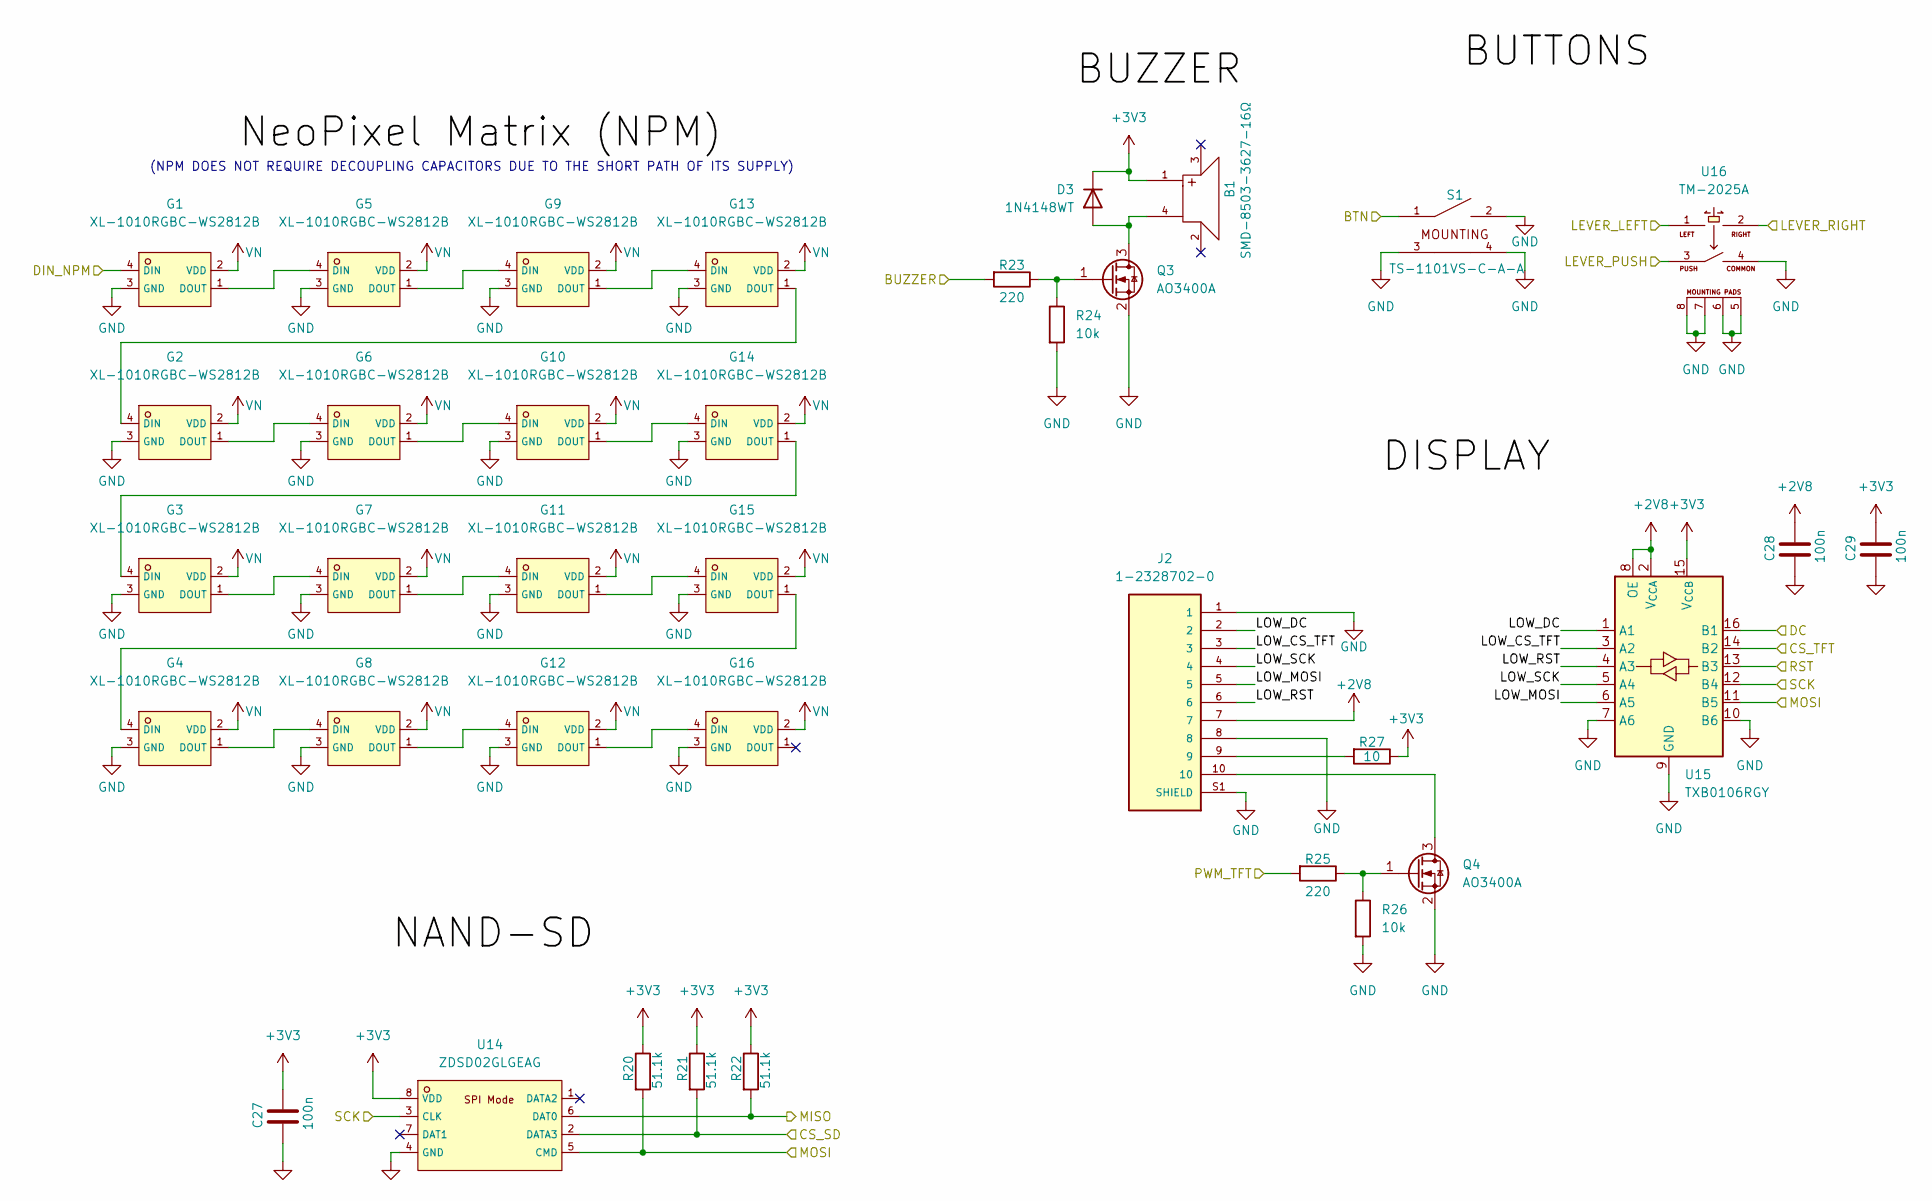
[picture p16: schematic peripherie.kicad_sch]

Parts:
B1: SMD-8503-3627-16Ω; BUZ-SMD_4P-L8.5-W8.5-BR-1; LCSC C2685545
C27, C28, C29: 100n; C_0402_1005Metric
D3: 1N4148WT; D_SOD-523
G1, G2, G3, G4, G5, G6, G7, G8, G9, G10, G11, G12, G13, G14, G15, G16: XL-1010RGBC-WS2812B; LED-SMD_4P-L1.0-W1.0-TL_XL-1010RGBC-WS2812B; LCSC C5349953
J2: 1-2328702-0; TE_1-2328702-0; PARTREV 5
Q3, Q4: AO3400A; SOT-23
R20, R21, R22: 51.1k; R_0402_1005Metric
R23, R25: 220; R_0402_1005Metric
R24, R26: 10k; R_0402_1005Metric
R27: 10; R_0402_1005Metric
S1: TS-1101VS-C-A-A; KEY-SMD_TS-1101VS-C-A-A
U14: ZDSD02GLGEAG; LGA-8_L8.0-W6.0-P1.27-TL_ZDSD02GLGEAG; LCSC C2875853
U15: TXB0106RGY; Texas_RGY_R-PVQFN-N16_EP2.05x2.55mm
U16: TM-2025A; SW-SMD_TM-2025A; LCSC C318949

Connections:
+2V8: C28.1, J2.7, U15.2 (V_{CCA}), U15.8 (OE); also elsewhere on the board
+3V3: B1.1, C27.1, C29.1, D3.1 (K), R20.1, R21.1, R22.1, R27.1, U14.8 (VDD), U15.15 (V_{CCB}); also elsewhere on the board
/Logic section/BTN: S1.1; also elsewhere on the board
/Logic section/CS_SD: R21.2, U14.2 (DATA3); also elsewhere on the board
/Logic section/CS_TFT: U15.14 (B2); also elsewhere on the board
/Logic section/DC: U15.16 (B1); also elsewhere on the board
/Logic section/DOUT_NPM: G1.4 (DIN); also elsewhere on the board
/Logic section/LEVER_LEFT: U16.1; also elsewhere on the board
/Logic section/LEVER_PUSH: U16.3; also elsewhere on the board
/Logic section/LEVER_RIGHT: U16.2; also elsewhere on the board
/Logic section/MISO: R22.2, U14.6 (DAT0); also elsewhere on the board
/Logic section/MOSI: R20.2, U14.5 (CMD), U15.11 (B5); also elsewhere on the board
/Logic section/PWM_TFT: R25.2; also elsewhere on the board
/Logic section/RST: U15.13 (B3); also elsewhere on the board
/Logic section/SCK: U14.3 (CLK), U15.12 (B4); also elsewhere on the board
/Peripherie/BUZZER: R23.2; also elsewhere on the board
/Peripherie/LOW_CS_TFT: J2.3, U15.3 (A2)
/Peripherie/LOW_DC: J2.2, U15.1 (A1)
/Peripherie/LOW_MOSI: J2.5, U15.6 (A5)
/Peripherie/LOW_RST: J2.6, U15.4 (A3)
/Peripherie/LOW_SCK: J2.4, U15.5 (A4)
GND: C27.2, C28.2, C29.2, G1.3 (GND), G2.3 (GND), G3.3 (GND), G4.3 (GND), G5.3 (GND), G6.3 (GND), G7.3 (GND), G8.3 (GND), G9.3 (GND), G10.3 (GND), G11.3 (GND), G12.3 (GND), G13.3 (GND), G14.3 (GND), G15.3 (GND), G16.3 (GND), J2.1, J2.8, J2.S1 (SHIELD), J2.S2 (SHIELD), Q3.2 (S), Q4.2 (S), R24.2, R26.2, S1.2, S1.3, S1.4, U14.4 (GND), U15.7 (A6), U15.9 (GND), U15.10 (B6), U15.17 (GND), U16.4, U16.5, U16.6, U16.7, U16.8; also elsewhere on the board
unnamed: B1.4, D3.2 (A), Q3.3 (D)
unnamed: G1.1 (DOUT), G5.4 (DIN)
unnamed: G2.1 (DOUT), G6.4 (DIN)
unnamed: G3.1 (DOUT), G7.4 (DIN)
unnamed: G4.1 (DOUT), G8.4 (DIN)
unnamed: G5.1 (DOUT), G9.4 (DIN)
unnamed: G6.1 (DOUT), G10.4 (DIN)
unnamed: G10.1 (DOUT), G14.4 (DIN)
unnamed: G7.1 (DOUT), G11.4 (DIN)
unnamed: G11.1 (DOUT), G15.4 (DIN)
unnamed: G8.1 (DOUT), G12.4 (DIN)
unnamed: G12.1 (DOUT), G16.4 (DIN)
unnamed: G9.1 (DOUT), G13.4 (DIN)
unnamed: G2.4 (DIN), G13.1 (DOUT)
unnamed: G3.4 (DIN), G14.1 (DOUT)
unnamed: G4.4 (DIN), G15.1 (DOUT)
unnamed: J2.9, R27.2
unnamed: Q3.1 (G), R23.1, R24.1
unnamed: J2.10, Q4.3 (D)
unnamed: Q4.1 (G), R25.1, R26.1
VN: G1.2 (VDD), G2.2 (VDD), G3.2 (VDD), G4.2 (VDD), G5.2 (VDD), G6.2 (VDD), G7.2 (VDD), G8.2 (VDD), G9.2 (VDD), G10.2 (VDD), G11.2 (VDD), G12.2 (VDD), G13.2 (VDD), G14.2 (VDD), G15.2 (VDD), G16.2 (VDD); also elsewhere on the board

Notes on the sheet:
(NPM DOES NOT REQUIRE DECOUPLING CAPACITORS DUE TO THE SHORT PATH OF ITS SUPPLY)

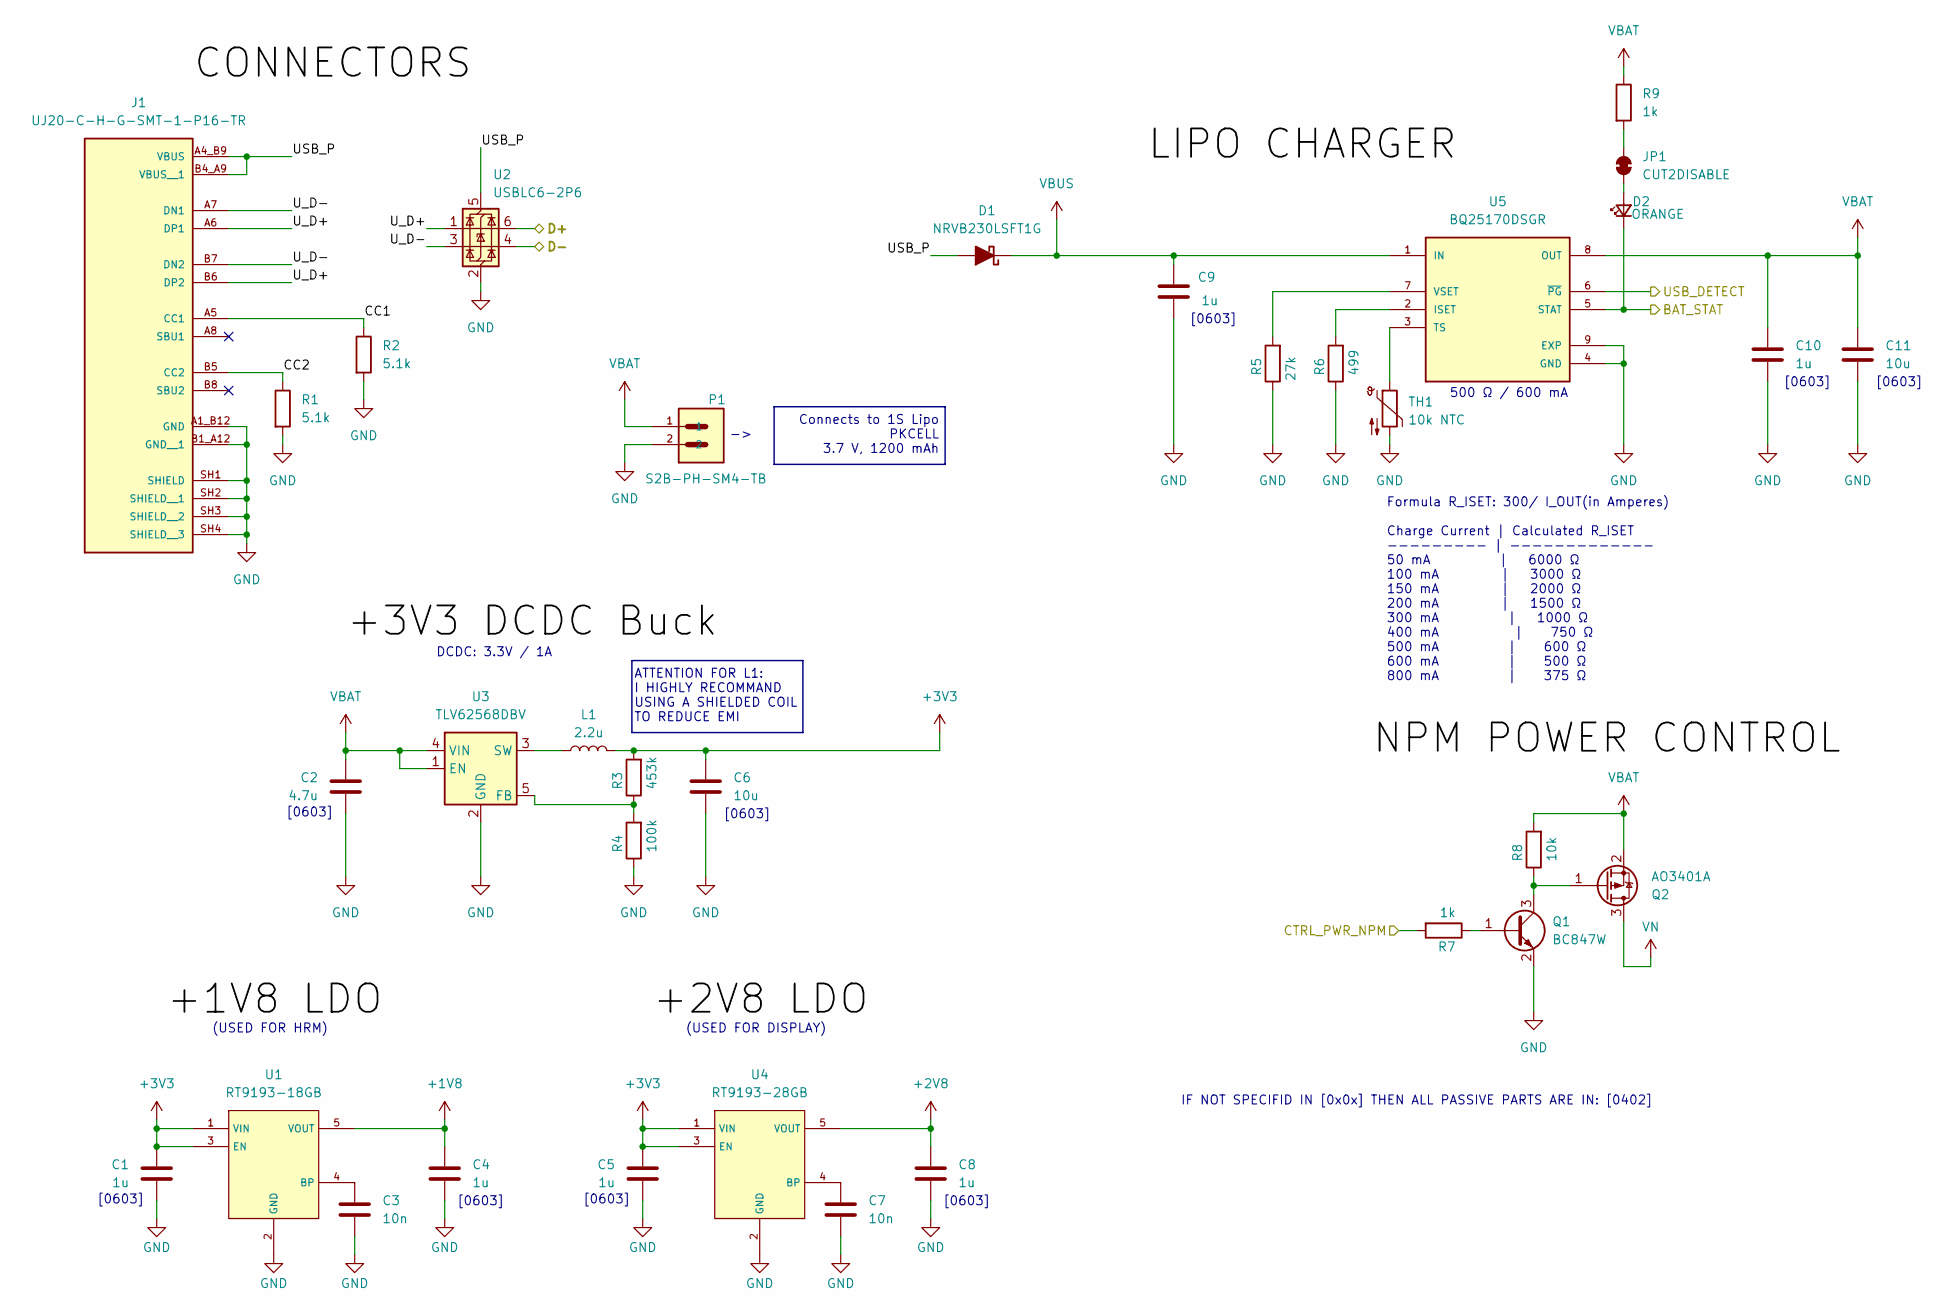
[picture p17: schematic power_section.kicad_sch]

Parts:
C1, C4, C5, C8, C9, C10: 1u; C_0603_1608Metric
C2: 4.7u; C_0603_1608Metric
C3, C7: 10n; C_0402_1005Metric
C6, C11: 10u; C_0603_1608Metric
D1: NRVB230LSFT1G; D_SOD-123
D2: ORANGE; LED_0603_1608Metric
J1: UJ20-C-H-G-SMT-1-P16-TR; SAMESKY_UJ20-C-H-G-SMT-1-P16-TR; PARTREV 1.0
JP1: CUT2DISABLE; SolderJumper-2_P1.3mm_Bridged_Pad1.0x1.5mm
L1: 2.2u; L_1008_2520Metric; Manufacturer part number SRN2510BTA-2R2M
P1: S2B-PH-SM4-TB; JST_S2B-PH-SM4-TB
Q1: BC847W; SOT-323_SC-70
Q2: AO3401A; SOT-23
R1, R2: 5.1k; R_0402_1005Metric
R3: 453k; R_0402_1005Metric
R4: 100k; R_0402_1005Metric
R5: 27k; R_0402_1005Metric
R6: 499; R_0402_1005Metric
R7, R9: 1k; R_0402_1005Metric
R8: 10k; R_0402_1005Metric
TH1: 10k NTC; R_0402_1005Metric; Manufacturer part number NCU15XH103D60RC
U1: RT9193-18GB; SOT23-5; LCSC C27416
U2: USBLC6-2P6; SOT-666
U3: TLV62568DBV; SOT-23-5
U4: RT9193-28GB; SOT23-5; LCSC C56731
U5: BQ25170DSGR; SON50P200X200X80-9N; PARTREV A

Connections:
+1V8: C4.1, U1.5 (VOUT); also elsewhere on the board
+2V8: C8.1, U4.5 (VOUT); also elsewhere on the board
+3V3: C1.1, C5.1, C6.1, L1.2, R3.2, U1.1 (VIN), U1.3 (EN), U4.1 (VIN), U4.3 (EN); also elsewhere on the board
/Logic section/BAT_STAT: D2.1 (K), U5.5 (STAT); also elsewhere on the board
/Logic section/D+: U2.6 (I/O1); also elsewhere on the board
/Logic section/D-: U2.4 (I/O2); also elsewhere on the board
/Logic section/PWR_NPM: R7.2; also elsewhere on the board
/Logic section/USB_DETECT: U5.6 (~PG); also elsewhere on the board
/Power section/CC1: J1.A5 (CC1), R2.1
/Power section/CC2: J1.B5 (CC2), R1.1
/Power section/USB_P: D1.2 (A), J1.A4_B9 (VBUS), J1.B4_A9 (VBUS__1), U2.5 (VBUS)
/Power section/U_D+: J1.A6 (DP1), J1.B6 (DP2), U2.1 (I/O1)
/Power section/U_D-: J1.A7 (DN1), J1.B7 (DN2), U2.3 (I/O2)
GND: C1.2, C2.2, C3.2, C4.2, C5.2, C6.2, C7.2, C8.2, C9.2, C10.2, C11.2, J1.A1_B12 (GND), J1.B1_A12 (GND__1), J1.SH1 (SHIELD), J1.SH2 (SHIELD__1), J1.SH3 (SHIELD__2), J1.SH4 (SHIELD__3), P1.2, Q1.2 (E), R1.2, R2.2, R4.1, R5.1, R6.1, TH1.2, U1.2 (GND), U2.2 (GND), U3.2 (GND), U4.2 (GND), U5.4 (GND), U5.9 (EXP); also elsewhere on the board
unnamed: D2.2 (A), JP1.2 (B)
unnamed: JP1.1 (A), R9.2
unnamed: Q1.1 (B), R7.1
unnamed: Q1.3 (C), Q2.1 (G), R8.1
unnamed: C3.1, U1.4 (BP)
unnamed: R3.1, R4.2, U3.5 (FB)
unnamed: L1.1, U3.3 (SW)
unnamed: C7.1, U4.4 (BP)
unnamed: R6.2, U5.2 (ISET)
unnamed: TH1.1, U5.3 (TS)
unnamed: R5.2, U5.7 (VSET)
VBAT: C2.1, C10.1, C11.1, P1.1, Q2.2 (S), R8.2, R9.1, U3.1 (EN), U3.4 (VIN), U5.8 (OUT); also elsewhere on the board
VBUS: C9.1, D1.1 (K), U5.1 (IN)
VN: Q2.3 (D); also elsewhere on the board

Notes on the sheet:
[0603]
Connects to 1S Lipo -> PKCELL 3.7 V, 1200 mAh
IF NOT SPECIFID IN [0x0x] THEN ALL PASSIVE PARTS ARE IN: [0402]
(USED FOR HRM)
ATTENTION FOR L1: I HIGHLY RECOMMAND USING A SHIELDED COIL TO REDUCE EMI
(USED FOR DISPLAY)
500 Ω / 600 mA
DCDC: 3.3V / 1A
Formula R_ISET: 300/ I_OUT(in Amperes) Charge Current | Calculated R_ISET --------- | ------------- 50 mA | 6000 Ω 100 mA | 3000 Ω 150 mA | 2000 Ω 200 mA | 1500 Ω 300 mA | 1000 Ω 400 mA | 750 Ω 500 mA | 600 Ω 600 mA | 500 Ω 800 mA | 375 Ω

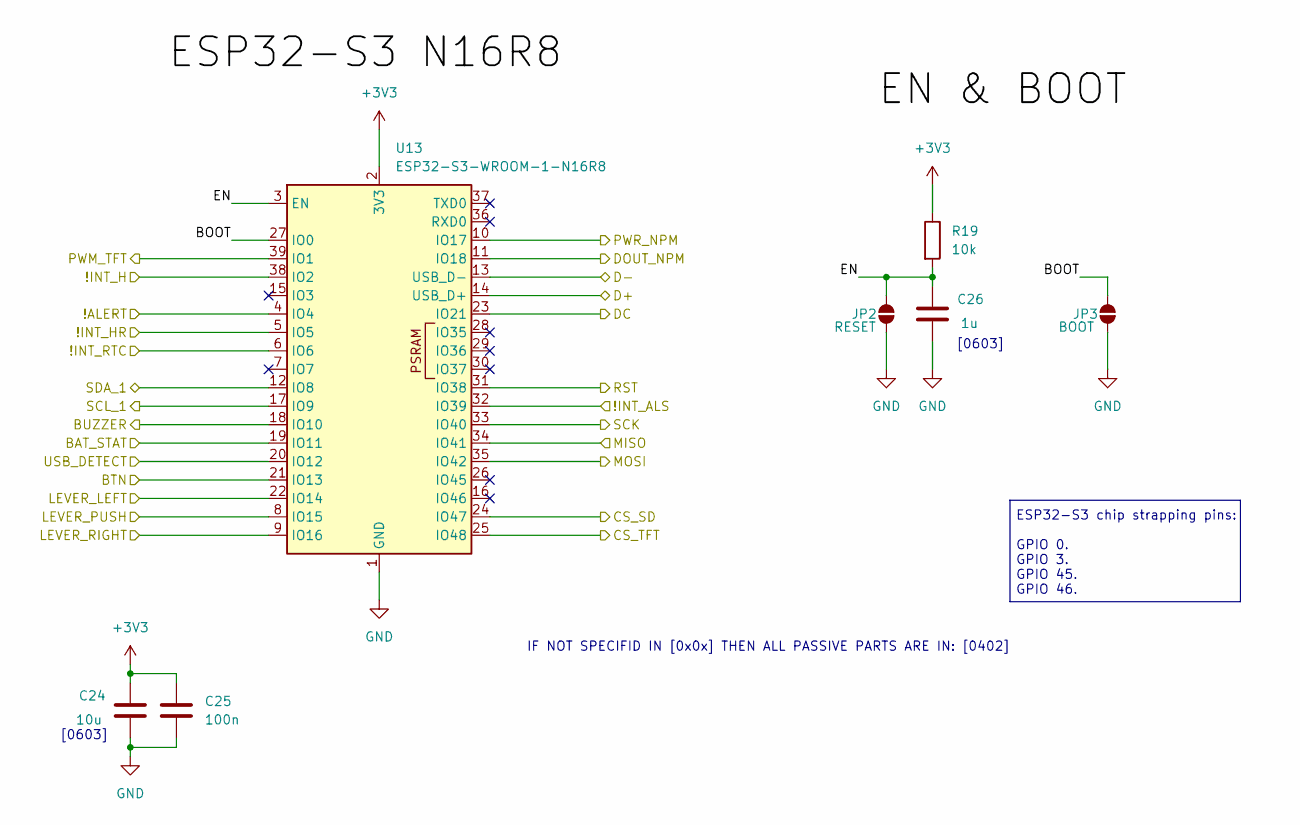
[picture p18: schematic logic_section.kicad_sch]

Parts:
C24: 10u; C_0603_1608Metric
C25: 100n; C_0402_1005Metric
C26: 1u; C_0603_1608Metric
JP2: RESET; SolderJumper-2_P1.3mm_Open_TrianglePad1.0x1.5mm
JP3: BOOT; SolderJumper-2_P1.3mm_Open_TrianglePad1.0x1.5mm
R19: 10k; R_0402_1005Metric
U13: ESP32-S3-WROOM-1-N16R8; ESP32-S3-WROOM-1; MPN ESP32-S3-WROOM-1-N16R8

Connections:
+3V3: C24.1, C25.1, R19.1, U13.2 (3V3); also elsewhere on the board
/Logic section/!ALERT: U13.4 (IO4); also elsewhere on the board
/Logic section/!INT_ALS: U13.32 (IO39); also elsewhere on the board
/Logic section/!INT_H: U13.38 (IO2); also elsewhere on the board
/Logic section/!INT_HR: U13.5 (IO5); also elsewhere on the board
/Logic section/!INT_RTC: U13.6 (IO6); also elsewhere on the board
/Logic section/BAT_STAT: U13.19 (IO11); also elsewhere on the board
/Logic section/BOOT: JP3.1 (A), U13.27 (IO0)
/Logic section/BTN: U13.21 (IO13); also elsewhere on the board
/Logic section/CS_SD: U13.24 (IO47); also elsewhere on the board
/Logic section/CS_TFT: U13.25 (IO48); also elsewhere on the board
/Logic section/D+: U13.14 (USB_D+); also elsewhere on the board
/Logic section/D-: U13.13 (USB_D-); also elsewhere on the board
/Logic section/DC: U13.23 (IO21); also elsewhere on the board
/Logic section/DOUT_NPM: U13.11 (IO18); also elsewhere on the board
/Logic section/EN: C26.1, JP2.1 (A), R19.2, U13.3 (EN)
/Logic section/LEVER_LEFT: U13.22 (IO14); also elsewhere on the board
/Logic section/LEVER_PUSH: U13.8 (IO15); also elsewhere on the board
/Logic section/LEVER_RIGHT: U13.9 (IO16); also elsewhere on the board
/Logic section/MISO: U13.34 (IO41); also elsewhere on the board
/Logic section/MOSI: U13.35 (IO42); also elsewhere on the board
/Logic section/PWM_TFT: U13.39 (IO1); also elsewhere on the board
/Logic section/PWR_NPM: U13.10 (IO17); also elsewhere on the board
/Logic section/RST: U13.31 (IO38); also elsewhere on the board
/Logic section/SCK: U13.33 (IO40); also elsewhere on the board
/Logic section/SCL_1: U13.17 (IO9); also elsewhere on the board
/Logic section/SDA_1: U13.12 (IO8); also elsewhere on the board
/Logic section/USB_DETECT: U13.20 (IO12); also elsewhere on the board
/Peripherie/BUZZER: U13.18 (IO10); also elsewhere on the board
GND: C24.2, C25.2, C26.2, JP2.2 (B), JP3.2 (B), U13.1 (GND), U13.40 (GND), U13.41 (GND); also elsewhere on the board

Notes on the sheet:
IF NOT SPECIFID IN [0x0x] THEN ALL PASSIVE PARTS ARE IN: [0402]
[0603]
ESP32-S3 chip strapping pins: GPIO 0. GPIO 3. GPIO 45. GPIO 46.

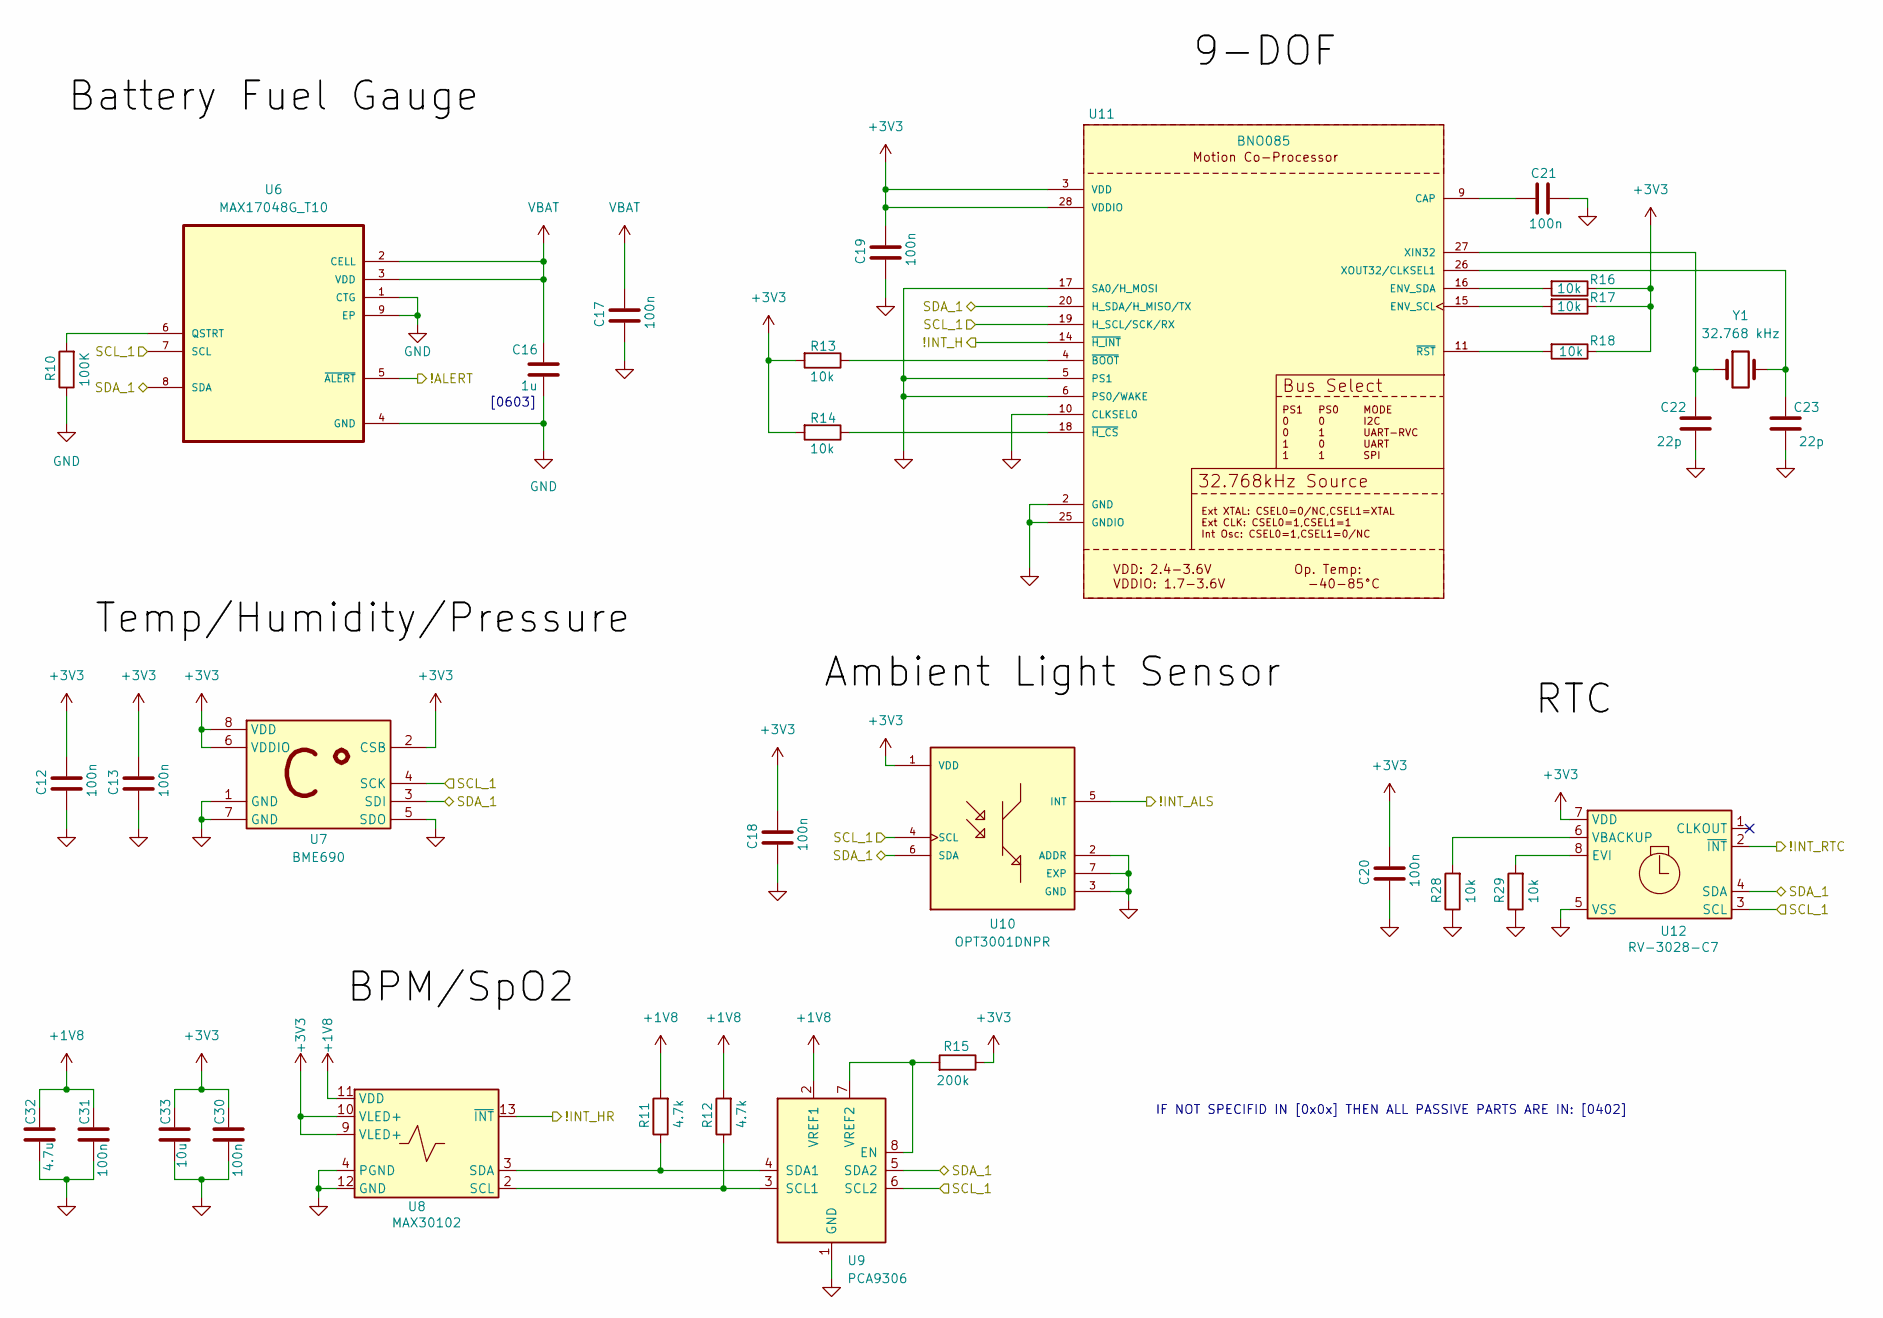
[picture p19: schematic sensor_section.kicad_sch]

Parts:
C12, C13, C17, C18, C19, C20, C21, C30, C31: 100n; C_0402_1005Metric
C16: 1u; C_0603_1608Metric
C22, C23: 22p; C_0402_1005Metric
C32: 4.7u; C_0603_1608Metric
C33: 10u; C_0603_1608Metric
R10: 100K; R_0402_1005Metric
R11, R12: 4.7k; R_0402_1005Metric
R13, R14, R16, R17, R18, R28, R29: 10k; R_0402_1005Metric
R15: 200k; R_0402_1005Metric
U6: MAX17048G_T10; SON50P200X200X80-9N
U7: BME690; Bosch_LGA-8_3x3mm_P0.8mm_ClockwisePinNumbering
U8: MAX30102; Maxim_OLGA-14_3.3x5.6mm_P0.8mm
U9: PCA9306; VSSOP-8_2.3x2mm_P0.5mm
U10: OPT3001DNPR; SON65P200X200X65-7N
U11: BNO085; IC_BNO085; PARTREV v1.17
U12: RV-3028-C7; MicroCrystal_C7_SON-8_1.5x3.2mm_P0.9mm
Y1: 32.768 kHz; Crystal_SMD_3215-2Pin_3.2x1.5mm; Tolerance ±20ppm; Manufacterer part number DH2032K768C5T1521011

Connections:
+1V8: C31.1, C32.1, R11.2, R12.2, U8.11 (VDD), U9.2 (VREF1); also elsewhere on the board
+3V3: C12.1, C13.1, C18.1, C19.1, C20.1, C30.1, C33.1, R13.2, R14.2, R15.1, R16.1, R17.1, R18.1, U7.2 (CSB), U7.6 (VDDIO), U7.8 (VDD), U8.9 (VLED+), U8.10 (VLED+), U10.1 (VDD), U11.3 (VDD), U11.28 (VDDIO), U12.7 (VDD); also elsewhere on the board
/Logic section/!ALERT: U6.5 (~ALERT); also elsewhere on the board
/Logic section/!INT_ALS: U10.5 (INT); also elsewhere on the board
/Logic section/!INT_H: U11.14 (~H_INT); also elsewhere on the board
/Logic section/!INT_HR: U8.13 (~INT); also elsewhere on the board
/Logic section/!INT_RTC: U12.2 (~INT); also elsewhere on the board
/Logic section/SCL_1: U6.7 (SCL), U7.4 (SCK), U9.6 (SCL2), U10.4 (SCL), U11.19 (H_SCL/SCK/RX), U12.3 (SCL); also elsewhere on the board
/Logic section/SDA_1: U6.8 (SDA), U7.3 (SDI), U9.5 (SDA2), U10.6 (SDA), U11.20 (H_SDA/H_MISO/TX), U12.4 (SDA); also elsewhere on the board
GND: C12.2, C13.2, C16.2, C17.2, C18.2, C19.2, C20.2, C21.1, C22.2, C23.2, C30.2, C31.2, C32.2, C33.2, R10.1, R28.1, R29.1, U6.1 (CTG), U6.4 (GND), U6.9 (EP), U7.1 (GND), U7.5 (SDO), U7.7 (GND), U8.4 (PGND), U8.12 (GND), U9.1 (GND), U10.2 (ADDR), U10.3 (GND), U10.7 (EXP), U11.2 (GND), U11.5 (PS1), U11.6 (PS0/WAKE), U11.10 (CLKSEL0), U11.17 (SA0/H_MOSI), U11.25 (GNDIO), U12.5 (VSS); also elsewhere on the board
unnamed: R10.2, U6.6 (QSTRT)
unnamed: R12.1, U8.2 (SCL), U9.3 (SCL1)
unnamed: R11.1, U8.3 (SDA), U9.4 (SDA1)
unnamed: R15.2, U9.7 (VREF2), U9.8 (EN)
unnamed: C21.2, U11.9 (CAP)
unnamed: R17.2, U11.15 (ENV_SCL)
unnamed: R16.2, U11.16 (ENV_SDA)
unnamed: C22.1, U11.27 (XIN32), Y1.1
unnamed: C23.1, U11.26 (XOUT32/CLKSEL1), Y1.2
unnamed: R13.1, U11.4 (~BOOT)
unnamed: R14.1, U11.18 (~H_CS)
unnamed: R18.2, U11.11 (~RST)
unnamed: R29.2, U12.8 (EVI)
unnamed: R28.2, U12.6 (VBACKUP)
VBAT: C16.1, C17.1, U6.2 (CELL), U6.3 (VDD); also elsewhere on the board

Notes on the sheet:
IF NOT SPECIFID IN [0x0x] THEN ALL PASSIVE PARTS ARE IN: [0402]
[0603]

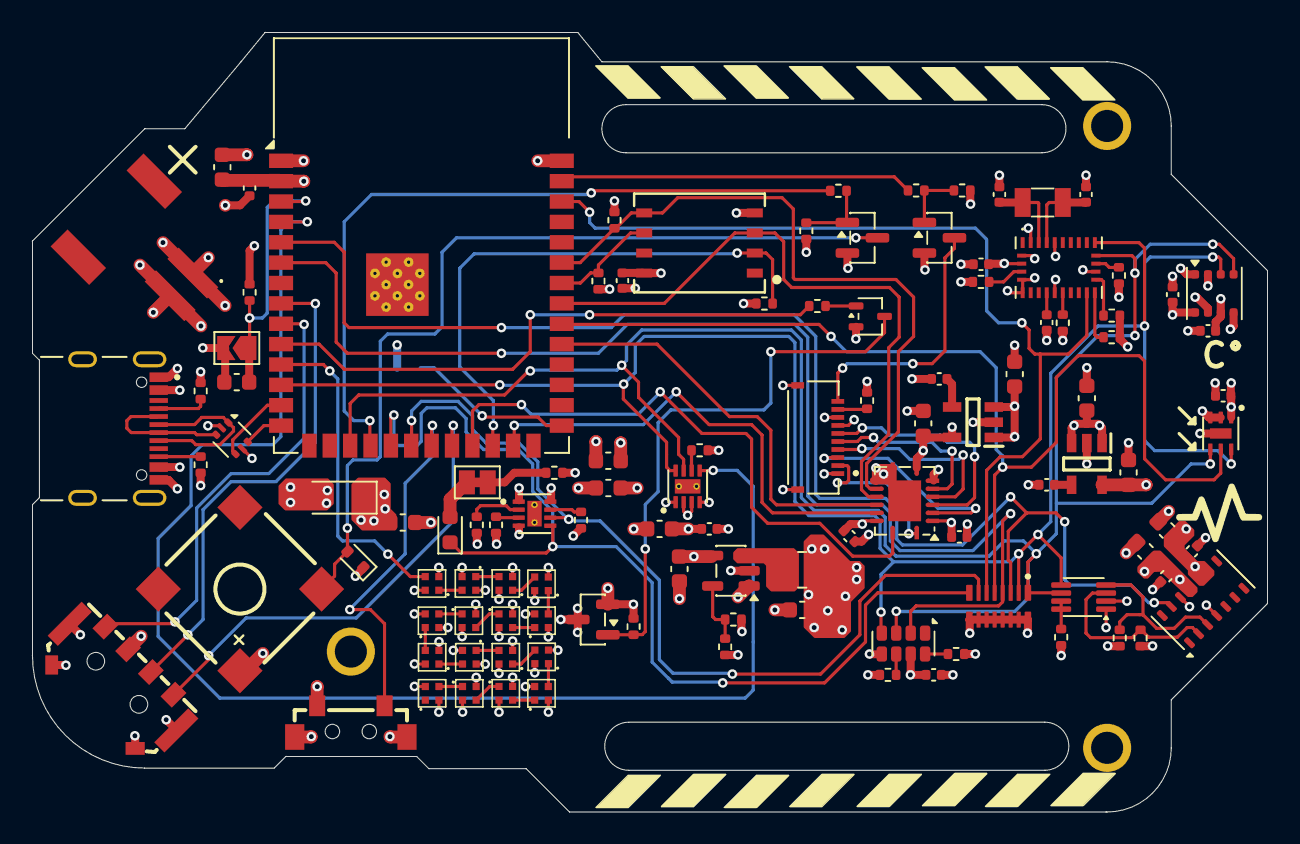
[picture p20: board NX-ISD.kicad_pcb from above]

Board: 4 copper layers, 77.0 x 48.6 mm, 111 parts (1 on the bottom side), 90 nets.

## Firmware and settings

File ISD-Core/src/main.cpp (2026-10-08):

#include <Arduino.h>
#include <Wire.h>
#include <esp_sleep.h>
#include <driver/rtc_io.h>
#include "DisplayConfig.h"
#include "pins.h"
#include "SensorState.h"
#include "HAL.h"
#include "Watchface.h"
#include "AppMenu.h"
#include "apps/tools/UplinkBridge.h"
#include "apps/tools/AppTools.h"
#include "apps/vitals/AppVitals.h"
#include "apps/settings/AppSettings.h"
#include "nx-systems/NX-MSF.h"
#include "storage/StorageManager.h"

#include "apps/settings/AppSettings.h"
#include "apps/enviroment/AppEnvironment.h"

// Hardware and UI instances
LGFX tft;
Watchface watchface(&tft);
AppMenu appMenu(&tft);
AppTools appTools(&tft);
AppVitals appVitals(&tft);
AppSettings appSettings(&tft);
AppEnvironment appEnvironment(&tft);

enum AppScreenMode {
  SCREEN_WATCHFACE,
  SCREEN_APPMENU,
  SCREEN_APP_TOOLS,
  SCREEN_APP_VITALS,
  SCREEN_APP_SETTINGS,
  SCREEN_APP_ENVIRONMENT
};
AppScreenMode currentScreen = SCREEN_WATCHFACE;
static bool settingsFromQuickpanel = false;

SensorState sharedState;
SemaphoreHandle_t stateMutex = NULL;
SemaphoreHandle_t i2cMutex = NULL;
TaskHandle_t sensorTaskHandle = NULL;

// Hardware Interrupt Event Flags & Physical State Latching for zero-latency, bounce-free control
volatile bool isrFlagBtn   = false;
volatile bool isrFlagLeft  = false;
volatile bool isrFlagPush  = false;
volatile bool isrFlagRight = false;

volatile bool activeBtn    = false;
volatile bool activeLeft   = false;
volatile bool activePush   = false;
volatile bool activeRight  = false;

volatile uint32_t isrTimeBtn   = 0;
volatile uint32_t isrTimeLeft  = 0;
volatile uint32_t isrTimePush  = 0;
volatile uint32_t isrTimeRight = 0;

void IRAM_ATTR isrBtn() {
  uint32_t now = (uint32_t)(esp_timer_get_time() / 1000ULL);
  if (!activeBtn && (now - isrTimeBtn > 40)) {
    activeBtn = true;
    isrFlagBtn = true;
    isrTimeBtn = now;
  }
}

void IRAM_ATTR isrLeverLeft() {
  uint32_t now = (uint32_t)(esp_timer_get_time() / 1000ULL);
  if (!activeLeft && (now - isrTimeLeft > 40)) {
    activeLeft = true;
    isrFlagLeft = true;
    isrTimeLeft = now;
  }
}

void IRAM_ATTR isrLeverPush() {
  uint32_t now = (uint32_t)(esp_timer_get_time() / 1000ULL);
  if (!activePush && (now - isrTimePush > 40)) {
    activePush = true;
    isrFlagPush = true;
    isrTimePush = now;
  }
}

void IRAM_ATTR isrLeverRight() {
  uint32_t now = (uint32_t)(esp_timer_get_time() / 1000ULL);
  if (!activeRight && (now - isrTimeRight > 40)) {
    activeRight = true;
    isrFlagRight = true;
    isrTimeRight = now;
  }
}

// Background Sensor Acquisition Task running on Core 0 (PRO CPU)
void vSensorTask(void* pvParameters) {
  uint32_t lastSlowPoll = 0;

  for (;;) {
    uint32_t now = millis();

    // 1. Power & charging detection (BQ25170 /PG on USB_DETECT and /STAT on BAT_STAT)
    bool curUsb = (digitalRead(USB_DETECT) == LOW);
    bool curChg = (digitalRead(BAT_STAT) == LOW);

    // 2. IMU polling (if BNO085 is present and ready)
    float curRoll = 0.0f, curPitch = 0.0f, curYaw = 0.0f;
    uint8_t curCalib = 0;
    bool imuOk = false;
    if (HAL::imuReady) {
      sh2_SensorValue_t sensorValue;
      while (HAL::imuSensor.getSensorEvent(&sensorValue)) {
        float qr = 1.0f, qi = 0.0f, qj = 0.0f, qk = 0.0f;
        bool validRv = false;

        if (sensorValue.sensorId == SH2_ROTATION_VECTOR) {
          qr = sensorValue.un.rotationVector.real;
          qi = sensorValue.un.rotationVector.i;
          qj = sensorValue.un.rotationVector.j;
          qk = sensorValue.un.rotationVector.k;
          curCalib = sensorValue.status & 0x03;
          validRv = true;
        } else if (sensorValue.sensorId == SH2_GEOMAGNETIC_ROTATION_VECTOR) {
          qr = sensorValue.un.geoMagRotationVector.real;
          qi = sensorValue.un.geoMagRotationVector.i;
          qj = sensorValue.un.geoMagRotationVector.j;
          qk = sensorValue.un.geoMagRotationVector.k;
          curCalib = sensorValue.status & 0x03;
          validRv = true;
        } else if (sensorValue.sensorId == SH2_ARVR_STABILIZED_RV) {
          qr = sensorValue.un.arvrStabilizedRV.real;
          qi = sensorValue.un.arvrStabilizedRV.i;
          qj = sensorValue.un.arvrStabilizedRV.j;
          qk = sensorValue.un.arvrStabilizedRV.k;
          curCalib = sensorValue.status & 0x03;
          validRv = true;
        }

        if (validRv) {
          float sqr = qr * qr;
          float sqi = qi * qi;
          float sqj = qj * qj;
          float sqk = qk * qk;
          float denom = sqi + sqj + sqk + sqr;
          if (denom > 0.0001f) {
            float sinP = constrain(-2.0f * (qi * qk - qj * qr) / denom, -1.0f, 1.0f);
            curPitch = asin(sinP) * RAD_TO_DEG;
            curRoll  = atan2(2.0f * (qj * qk + qi * qr), (-sqi - sqj + sqk + sqr)) * RAD_TO_DEG;
            curYaw   = atan2(2.0f * (qi * qj + qk * qr), (sqi - sqj - sqk + sqr)) * RAD_TO_DEG;
            imuOk = true;
          }
        }
      }
    }

    // 2b. Fast Ambient Light Polling (every 100ms for real-time palm cover & auto-dim)
    static uint32_t lastLightPoll = 0;
    bool doLightPoll = (now - lastLightPoll >= 100);
    float fastLux = 0.0f;
    bool fastLightOk = false;
    if (doLightPoll) {
      lastLightPoll = now;
      if (HAL::lightSensorReady) {
        OPT3001 res = HAL::lightSensor.readResult();
        if (res.error == NO_ERROR) {
          fastLux = res.lux;
          fastLightOk = true;
        }
      }
    }

    // 3. Slow Sensor polling (every 1000ms: Fuel Gauge, RTC, BME690)
    // Executed OUTSIDE the mutex so stateMutex lock time is strictly < 1 microsecond!
    bool doSlowPoll = (now - lastSlowPoll >= 1000);
    float slowVolt = 0.0f, slowPct = 0.0f, slowRate = 0.0f;
    bool slowFuelOk = false;
    char slowTime[16] = "";
    char slowDate[16] = "";
    bool slowRtcOk = false;
    bme68xData slowEnvData;
    bool slowEnvOk = false;

    if (doSlowPoll) {
      lastSlowPoll = now;

      // Battery Fuel Gauge (MAX17048 with hardware I2C fallback)
      slowFuelOk = HAL::readFuelGauge(slowVolt, slowPct, slowRate);

      // RTC Real Time (RV-3028)
      if (HAL::rtcReady) {
        HAL::rtcClock.updateTime();
        snprintf(slowTime, sizeof(slowTime), "%02d:%02d:%02d",
                 HAL::rtcClock.getHours(),
                 HAL::rtcClock.getMinutes(),
                 HAL::rtcClock.getSeconds());
        snprintf(slowDate, sizeof(slowDate), "%04d-%02d-%02d",
                 HAL::rtcClock.getYear(),
                 HAL::rtcClock.getMonth(),
                 HAL::rtcClock.getDate());
        slowRtcOk = true;
      }

      // BME690 Environmental (Temp, Humidity, Pressure, Gas)
      if (HAL::envSensorReady) {
        if (HAL::envSensor.fetchData()) {
          HAL::envSensor.getData(slowEnvData);
          slowEnvOk = true;
        }
        HAL::envSensor.setOpMode(BME68X_FORCED_MODE);
      }
    }

    // 4. Thread-safe state update (< 1 microsecond memory copy)
    if (xSemaphoreTake(stateMutex, pdMS_TO_TICKS(10)) == pdTRUE) {
      sharedState.usbConnected = curUsb;
      sharedState.isCharging = curChg;

      if (imuOk) {
        sharedState.roll = curRoll;
        sharedState.pitch = curPitch;
        sharedState.yaw = curYaw;
        sharedState.imuCalib = curCalib;
        sharedState.imuDataReady = true;
      }

      if (fastLightOk) {
        sharedState.lightLux = fastLux;
      }

      if (doSlowPoll) {
        if (slowFuelOk) {
          sharedState.batVoltage = slowVolt;
          sharedState.batPercent = slowPct;
          sharedState.batChangeRate = slowRate;
        }
        if (slowRtcOk) {
          memcpy(sharedState.rtcTime, slowTime, sizeof(sharedState.rtcTime));
          memcpy(sharedState.rtcDate, slowDate, sizeof(sharedState.rtcDate));
        }
        if (slowEnvOk) {
          sharedState.temp = slowEnvData.temperature;
          sharedState.hum = slowEnvData.humidity;
          sharedState.press = slowEnvData.pressure / 100.0f; // Pa to hPa
          sharedState.gas = slowEnvData.gas_resistance;
          sharedState.envDataReady = true;
        }
      }

      xSemaphoreGive(stateMutex);
    }

    vTaskDelay(pdMS_TO_TICKS(10)); // 100 Hz sampling for IMU
  }
}

// ==================== INITIALIZATION & BOOT ====================

struct BootSync {
  volatile float hwProgress;
  volatile bool hwDone;
};
static BootSync bootSync = { 0.05f, false };

void vHardwareInitTask(void* pvParameters) {
  HAL::begin([](float progress) {
    bootSync.hwProgress = progress;
  });
  bootSync.hwDone = true;
  vTaskDelete(NULL);
}

void setup() {
  // Release and deinit any pins held during deep sleep
  rtc_gpio_hold_dis((gpio_num_t)BTN);
  rtc_gpio_hold_dis((gpio_num_t)LEVER_PUSH);
  rtc_gpio_deinit((gpio_num_t)BTN);
  rtc_gpio_deinit((gpio_num_t)LEVER_PUSH);
  gpio_deep_sleep_hold_dis();

  Serial.begin(115200);

  // Check if waking up from Deep Sleep via BTN (GPIO 13) or other trigger
  esp_sleep_wakeup_cause_t wakeup_cause = esp_sleep_get_wakeup_cause();
  if (wakeup_cause == ESP_SLEEP_WAKEUP_EXT0 || 
      wakeup_cause == ESP_SLEEP_WAKEUP_EXT1 || 
      wakeup_cause == ESP_SLEEP_WAKEUP_GPIO) {
    Serial.println("[PWR] Waking from Deep Sleep via User Input...");
  }

  // 1. Initialize Hardware Pins & Safety Gating (Muted buzzer, CS lines high, user inputs configured)
  HAL::initPins();

  // Attach zero-latency hardware interrupts for controls
  attachInterrupt(digitalPinToInterrupt(BTN), isrBtn, FALLING);
  attachInterrupt(digitalPinToInterrupt(LEVER_LEFT), isrLeverLeft, FALLING);
  attachInterrupt(digitalPinToInterrupt(LEVER_PUSH), isrLeverPush, FALLING);
  attachInterrupt(digitalPinToInterrupt(LEVER_RIGHT), isrLeverRight, FALLING);

  // 2. Initialize ST7789 IPS Display immediately
  tft.init();
  tft.setRotation(3);
  tft.setBrightness(220);
  tft.fillScreen(TFT_BLACK);

  // 3. Initialize Double-Buffered Watchface Sprite in PSRAM
  watchface.begin();

  // 3b. Initialize AppMenu sharing zero-copy PSRAM canvas and palette with Watchface
  appMenu.init(
    watchface.getCanvas(),
    watchface.getColorBg(),
    watchface.getColorOrangeBright(),
    watchface.getColorOrangeMid(),
    watchface.getColorOrangeDim(),
    watchface.getColorOrangeDark()
  );

  // 3c. Initialize AppTools sharing zero-copy PSRAM canvas and palette
  appTools.init(
    watchface.getCanvas(),
    watchface.getColorBg(),
    watchface.getColorOrangeBright(),
    watchface.getColorOrangeMid(),
    watchface.getColorOrangeDim(),
    watchface.getColorOrangeDark()
  );

  // 3d. Initialize AppVitals sharing zero-copy PSRAM canvas and palette
  appVitals.init(
    watchface.getCanvas(),
    watchface.getColorBg(),
    watchface.getColorOrangeBright(),
    watchface.getColorOrangeMid(),
    watchface.getColorOrangeDim(),
    watchface.getColorOrangeDark()
  );

  // 3e. Initialize AppSettings sharing zero-copy PSRAM canvas and palette
  appSettings.init(
    watchface.getCanvas(),
    watchface.getColorBg(),
    watchface.getColorOrangeBright(),
    watchface.getColorOrangeMid(),
    watchface.getColorOrangeDim(),
    watchface.getColorOrangeDark()
  );

  // 3f. Initialize AppEnvironment sharing zero-copy PSRAM canvas and palette
  appEnvironment.init(
    watchface.getCanvas(),
    watchface.getColorBg(),
    watchface.getColorOrangeBright(),
    watchface.getColorOrangeMid(),
    watchface.getColorOrangeDim(),
    watchface.getColorOrangeDark()
  );

  // 4. Render initial boot frame instantly
  watchface.renderBootFrame(0.02f);

  // 5. Launch Hardware Bring-up in Real Background Task on Core 0
  xTaskCreatePinnedToCore(
    vHardwareInitTask,
    "HwInitTask",
    6144,
    NULL,
    1,
    NULL,
    0
  );

  // 6. Play Smooth Boot Animation on Core 1 tracking real background hardware progress (~1.8s)
  watchface.playBootSequence(&bootSync.hwProgress, &bootSync.hwDone, 1750);

  // 5. Create FreeRTOS Mutexes
  stateMutex = xSemaphoreCreateMutex();
  i2cMutex = xSemaphoreCreateMutex();

  // 6. Pre-seed initial state so watchface displays immediately without delay
  sharedState.usbConnected = (digitalRead(USB_DETECT) == LOW);
  sharedState.isCharging = (digitalRead(BAT_STAT) == LOW);
  float initV = 0.0f, initP = 0.0f, initR = 0.0f;
  if (HAL::readFuelGauge(initV, initP, initR)) {
    sharedState.batVoltage = initV;
    sharedState.batPercent = initP;
    sharedState.batChangeRate = initR;
  }
  if (HAL::rtcReady) {
    HAL::rtcClock.updateTime();
    snprintf(sharedState.rtcTime, sizeof(sharedState.rtcTime), "%02d:%02d:%02d",
             HAL::rtcClock.getHours(),
             HAL::rtcClock.getMinutes(),
             HAL::rtcClock.getSeconds());
    snprintf(sharedState.rtcDate, sizeof(sharedState.rtcDate), "%04d-%02d-%02d",
             HAL::rtcClock.getYear(),
             HAL::rtcClock.getMonth(),
             HAL::rtcClock.getDate());
  }

  // 7. Spawn Background Sensor Task pinned to Core 0 (PRO CPU)
  xTaskCreatePinnedToCore(
    vSensorTask,
    "SensorTask",
    4096,
    NULL,
    1,
    &sensorTaskHandle,
    0
  );

  // 8. Initialize NX-Uplink Companion Bridge and NeoPixel Matrix
  UplinkBridge::begin();

  // 9. Initialize Storage Manager & load persistent configuration from ZDSD NAND
  StorageManager::begin(&tft);

  Serial.println("\n[NX-ISD] Watchface active. Double-buffering enabled. Audio muted.");
}

// Helper: Checks if the watch is held/tilted in an active viewing orientation
static inline bool isViewingAngle(float roll, float pitch, TiltMode mode) {
  float absR = fabsf(roll);
  float absP = fabsf(pitch);

  switch (mode) {
    case TILT_SENSITIVE:
      // Broad viewing window: 12° to 80° on either axis with orthogonal kept under 60°
      return ((absR >= 12.0f && absR <= 80.0f && absP <= 60.0f) ||
              (absP >= 12.0f && absP <= 80.0f && absR <= 60.0f));

    case TILT_BALANCED:
      // Natural wrist glance: 22° to 72° on either axis with orthogonal kept under 48°
      return ((absR >= 22.0f && absR <= 72.0f && absP <= 48.0f) ||
              (absP >= 22.0f && absP <= 72.0f && absR <= 48.0f));

    case TILT_SLUGGISH:
      // Steep deliberate glance: 35° to 65° with orthogonal strictly level (< 35°)
      return ((absR >= 35.0f && absR <= 65.0f && absP <= 35.0f) ||
              (absP >= 35.0f && absP <= 65.0f && absR <= 35.0f));

    case TILT_OFF:
    default:
      return false;
  }
}

// Helper: Checks if the watch is resting (arm hanging vertically down at the side)
static inline bool isRestingAngle(float roll, float pitch) {
  float absR = fabsf(roll);
  float absP = fabsf(pitch);
  // Arm hanging straight down (> 75° on primary axis)
  // Flat on desk (facing upwards) is active viewing, NEVER sleep!
  return (absR >= 75.0f) || (absP >= 75.0f);
}

// ==================== MAIN UI LOOP (Core 1) ====================
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

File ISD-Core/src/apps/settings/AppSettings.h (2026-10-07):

#pragma once
#include <Arduino.h>
#include <LovyanGFX.hpp>
#include "SensorState.h"
#include "HAL.h"
#include "../tools/UplinkBridge.h"
#include "../../storage/StorageManager.h"

enum SettingsViewMode {
  SETTINGS_VIEW_CATEGORIES = 0,
  SETTINGS_VIEW_ITEMS
};

class AppSettings {
private:
  LGFX_Sprite* canvas = nullptr;
  LGFX* display = nullptr;

  uint16_t COLOR_BG;
  uint16_t COLOR_ORANGE_BRIGHT;
  uint16_t COLOR_ORANGE_MID;
  uint16_t COLOR_ORANGE_DIM;
  uint16_t COLOR_ORANGE_DARK;

  SettingsViewMode viewMode = SETTINGS_VIEW_CATEGORIES;
  int selectedCategory = 0; // 0..5
  int categoryScrollOffset = 0;
  int selectedItem = 0;
  int itemScrollOffset = 0;

  static const int CATEGORY_COUNT = 6;
  const char* categoryNames[CATEGORY_COUNT] = {
    "DISPLAY",
    "NOTIFICATIONS",
    "POWER SAVE",
    "BUZZER",
    "NPM",
    "NX-AIS"
  };

  const char* npmPatternLabels[6] = { "RADAR", "RAIN", "PLASMA", "TRACER", "BREATH", "OFF" };

  bool inBrightnessDial = false;
  bool inTimeoutDial = false;
  bool inFadeDial = false;
  bool inNpmBrightnessDial = false;
  bool inBuzzerVolumeDial = false;
  bool inBuzzerDurationDial = false;
  bool inBuzzerPitchDial = false;
  bool inTiltMenu = false;
  int tiltMenuIndex = 2;
  const char* tiltLabels[4] = { "OFF", "SENSITIVE", "BALANCED", "SLUGGISH" };
  const char* hrmReminderLabels[4] = { "OFF", "30m", "1h", "2h" };

  bool isDirty = false;

  void markDirty() {
    isDirty = true;
  }

  void commitSettingsIfDirty() {
    if (isDirty) {
      StorageManager::extractConfigFromHAL(StorageManager::getActiveConfig());
      StorageManager::saveConfig(StorageManager::getActiveConfig());
      isDirty = false;
    }
  }

  void setNpmBrightnessPercent(int pct) {
    HAL::npmBrightnessPercent = constrain(pct, 10, 100);
    uint8_t pwm = (uint8_t)map(HAL::npmBrightnessPercent, 0, 100, 0, 80);
    UplinkBridge::setMatrixBrightness(pwm);
  }

public:
  AppSettings(LGFX* tft) : display(tft) {}

  void init(LGFX_Sprite* spr, uint16_t bg, uint16_t bright, uint16_t mid, uint16_t dim, uint16_t dark) {
    canvas = spr;
    COLOR_BG = bg;
    COLOR_ORANGE_BRIGHT = bright;
    COLOR_ORANGE_MID = mid;
    COLOR_ORANGE_DIM = dim;
    COLOR_ORANGE_DARK = dark;
  }

  void onEnter() {
    viewMode = SETTINGS_VIEW_CATEGORIES;
    selectedCategory = 0;
    categoryScrollOffset = 0;
    selectedItem = 0;
    itemScrollOffset = 0;
    inBrightnessDial = false;
    inTimeoutDial = false;
    inFadeDial = false;
    inNpmBrightnessDial = false;
    inBuzzerVolumeDial = false;
    inBuzzerDurationDial = false;
    inBuzzerPitchDial = false;
    inTiltMenu = false;
    tiltMenuIndex = (int)HAL::tiltMode;
    isDirty = false;
  }

  void onExit() {
    commitSettingsIfDirty();
  }

  // Returns false when exiting root menu back to OS
  bool handleNavBtn() {
    if (inBrightnessDial) {
      inBrightnessDial = false;
      HAL::buzzPip(2400, 10);
      commitSettingsIfDirty();
      return true;
    }
    if (inTimeoutDial) {
      inTimeoutDial = false;
      HAL::buzzPip(2400, 10);
      commitSettingsIfDirty();
      return true;
    }
    if (inFadeDial) {
      inFadeDial = false;
      HAL::buzzPip(2400, 10);
      commitSettingsIfDirty();
      return true;
    }
    if (inNpmBrightnessDial) {
      inNpmBrightnessDial = false;
      HAL::buzzPip(2400, 10);
      commitSettingsIfDirty();
      return true;
    }
    if (inBuzzerVolumeDial) {
      inBuzzerVolumeDial = false;
      HAL::buzzPip(2400, 10);
      commitSettingsIfDirty();
      return true;
    }
    if (inBuzzerDurationDial) {
      inBuzzerDurationDial = false;
      HAL::buzzPip(2400, 10);
      commitSettingsIfDirty();
      return true;
    }
    if (inBuzzerPitchDial) {
      inBuzzerPitchDial = false;
      HAL::buzzPip(2400, 10);
      commitSettingsIfDirty();
      return true;
    }
    if (inTiltMenu) {
      inTiltMenu = false;
      HAL::buzzPip(2400, 10);
      commitSettingsIfDirty();
      return true;
    }
    if (viewMode == SETTINGS_VIEW_ITEMS) {
      viewMode = SETTINGS_VIEW_CATEGORIES;
      selectedItem = 0;
      itemScrollOffset = 0;
      HAL::buzzPip(2400, 10);
      commitSettingsIfDirty();
      return true;
    }
    HAL::buzzPip(2000, 15);
    commitSettingsIfDirty();
    return false;
  }
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

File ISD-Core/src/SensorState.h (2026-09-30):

#pragma once
#include <Arduino.h>

struct SensorState {
  // Fuel Gauge (MAX17048)
  float batVoltage = 0.0f;
  float batPercent = 0.0f;
  float batChangeRate = 0.0f;

  // RTC (RV-3028)
  char rtcTime[16] = "--:--:--";
  char rtcDate[16] = "--/--/----";

  // ALS (OPT3001)
  float lightLux = 0.0f;

  // Env (BME690)
  float temp = 0.0f;
  float hum = 0.0f;
  float press = 0.0f;
  float gas = 0.0f;
  bool envDataReady = false;

  // IMU (BNO085)
  float roll = 0.0f;
  float pitch = 0.0f;
  float yaw = 0.0f;
  float heading = 0.0f;
  uint8_t imuCalib = 0; // 0=Unreliable, 1=Low, 2=Med, 3=High
  float ax = 0.0f;
  float ay = 0.0f;
  float az = 0.0f;
  bool imuDataReady = false;

  // BPM & SpO2 (MAX30102)
  uint32_t bpmRed = 0;
  uint32_t bpmIR = 0;
  float heartRate = 0.0f;
  float spo2 = 0.0f;
  bool fingerDetected = false;
  bool beatDetected = false;

  // Power & Charging Status
  bool usbConnected = false;
  bool isCharging = false;

  // Buttons & Navigation Lever (Active-LOW, true when pressed)
  bool inputBtn = false;
  bool inputLeverLeft = false;
  bool inputLeverPush = false;
  bool inputLeverRight = false;

  // Discrete Navigation Click Events (Consumed on read)
  bool evtNavLeft = false;
  bool evtNavRight = false;
  bool evtNavPush = false;
  bool evtNavBtn = false;
};

// Declared as extern; will be defined in main.cpp
extern SensorState sharedState;
extern SemaphoreHandle_t stateMutex;
extern SemaphoreHandle_t i2cMutex;

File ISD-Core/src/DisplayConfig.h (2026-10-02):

#pragma once
#define LGFX_USE_V1
#include "pins.h"
#include <LovyanGFX.hpp>

class LGFX : public lgfx::LGFX_Device {
  lgfx::Panel_ST7789 _panel_instance;
  lgfx::Bus_SPI _bus_instance;
  lgfx::Light_PWM _light_instance;

public:
  LGFX(void) {
    {
      auto cfg = _bus_instance.config();

      cfg.spi_host = SPI2_HOST; // FSPI on ESP32-S3
      cfg.spi_mode = 0;         // Mode 0
      // 24 MHz: Maximum rated push-pull data rate for the TXB0106 level shifter
      // (~24 Mbps). Delivers ~26 FPS (38.4ms per 240x240 16-bit frame).
      // Prevents edge distortion, missed clock pulses, and periodic frame
      // flickering during sensor power dips. NOTE for v1p4: Once U15 (TXB0106)
      // is removed and the display runs directly on 3.3V, this clock can be
      // boosted to 40 MHz (43.5 FPS) or 80 MHz (86.8 FPS).
      cfg.freq_write = 40000000; // 40 MHz high-speed SPI write clock (~43.5 FPS)
      cfg.freq_read = 10000000;
      cfg.spi_3wire = false;
      cfg.use_lock = true;
      cfg.dma_channel = SPI_DMA_CH_AUTO;
      cfg.pin_sclk = SPI_SCK;  // GPIO 40
      cfg.pin_mosi = SPI_MOSI; // GPIO 42
      cfg.pin_miso = SPI_MISO; // GPIO 41
      cfg.pin_dc = TFT_RS;     // GPIO 21

      _bus_instance.config(cfg);
      _panel_instance.setBus(&_bus_instance);
    }

    {
      auto cfg = _panel_instance.config();

      cfg.pin_cs = CS_TFT;   // GPIO 48
      cfg.pin_rst = TFT_RST; // GPIO 38
      cfg.pin_busy = -1;

      cfg.panel_width = 240;
      cfg.panel_height = 240;
      cfg.offset_x = 0;
      cfg.offset_y = 0;
      cfg.offset_rotation = 0;
      cfg.dummy_read_pixel = 8;
      cfg.dummy_read_bits = 1;
      cfg.readable = false;
      cfg.invert = true;     // 1.54" IPS panels require color inversion ON
      cfg.rgb_order = false; // RGB
      cfg.dlen_16bit = false;
      cfg.bus_shared = true; // Shared SPI bus with SD card

      _panel_instance.config(cfg);
    }

    {
      auto cfg = _light_instance.config();

      cfg.pin_bl = TFT_PWM; // GPIO 1
      cfg.invert = false;   // Active HIGH via N-MOSFET Q4
      cfg.freq = 44100;
      cfg.pwm_channel = 7;

      _light_instance.config(cfg);
      _panel_instance.setLight(&_light_instance);
    }

    setPanel(&_panel_instance);
  }
};

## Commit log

2026-08-24 Add NX-ISD design files
    [NX-ISD.kicad_pcb, NX-ISD.kicad_sch, logic_section.kicad_sch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]
2026-08-25 Updated v1p0 files
    [NX-ISD.kicad_pcb, logic_section.kicad_sch, peripherie.kicad_sch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]
2026-08-25 added production files v1p0
    [bom.csv, designators.csv, positions.csv]
2026-08-26 updated BOM for ready use
    [LCSC-BOM.xls, bom.csv]
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2026-08-27 updated labels
    [NX-ISD.kicad_sch, logic_section.kicad_sch, sensor_section.kicad_sch]
2026-08-27 updated label
    [NX-ISD.kicad_pcb]
2026-09-02 Fixed: polarity of NPM Pmos
    [NX-ISD.kicad_pcb, NX-ISD.kicad_sch, NX-ISD_v1p1_designators.csv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]
2026-09-03 v1p1 rework in progress
    [NX-ISD.kicad_pcb, NX-ISD.kicad_sch, logic_section.kicad_sch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]
2026-09-05 added software planed feature and progress on v1p1
    [NX-ISD.kicad_pcb, power_section.kicad_sch]
2026-09-07 v1p1 updates
    [NX-ISD.kicad_pcb, NX-ISD.kicad_sch, power_section.kicad_sch]
2026-09-09 finished v1p1 routing
    [NX-ISD.kicad_pcb, peripherie.kicad_sch]
2026-09-09 v1p1 drc check
    [NX-ISD.kicad_pcb]
2026-09-10 new USBC plug and minor changes to ISD-Core
    [NX-ISD.kicad_pcb, power_section.kicad_sch]
2026-09-11 v1p3 major fix rework in progress
    [NX-ISD.kicad_pcb, NX-ISD.kicad_sch, peripherie.kicad_sch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]
2026-09-11 v1p3 : Fixed LED & DRC check successful
    [NX-ISD.kicad_pcb, power_section.kicad_sch]
2026-09-11 fixed: NAND Flash
    [NX-ISD.kicad_pcb]
2026-09-11 Silkscreen Font change
    [NX-ISD.kicad_pcb]
2026-09-11 Added LiPo polarity mark
    [NX-ISD.kicad_pcb]
2026-09-11 Added 3D-Renders to README
    [NX-ISD.kicad_pcb, peripherie.kicad_sch, power_section.kicad_sch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]
2026-09-11 minor changes
    [NX-ISD.kicad_pcb]
2026-09-14 v1p3 production ready
    [LCSC-BOM.xls, NX-ISD.kicad_pcb, NX-ISD_v1p1_designators.csv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]
2026-09-14 v1p3 value hotfix - Display backlight resistor change
    [NX-ISD.kicad_pcb, peripherie.kicad_sch]
2026-09-14 v1p3 - updated final circuit
    [NX-ISD.kicad_pcb, NX-ISD_v1p3_bom.csv]
2026-09-15 v1p3 - Isssues fixed
    [NX-ISD.kicad_pcb, NX-ISD.kicad_sch, NX-ISD_v1p3_bom.csv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]
2026-09-15 v1p3 - fixed
    [NX-ISD.kicad_pcb, NX-ISD_v1p3_bom.csv, NX-ISD_v1p3_designators.csv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]
2026-09-15 v1p3 - HRM Cap fix &more
    [NX-ISD.kicad_pcb, NX-ISD_v1p3_bom.csv, NX-ISD_v1p3_designators.csv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]
2026-09-15 v1p3 - RTC fix
    [NX-ISD.kicad_pcb, NX-ISD_v1p3_bom.csv, NX-ISD_v1p3_designators.csv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]
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2026-09-15 v1p3 - minor optimizations
    [NX-ISD.kicad_pcb]
2026-09-16 v1p3 - Production release
    [NX-ISD.kicad_pcb]
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2026-09-22 Restyle KiCad BOM toolbar buttons and SVG icons in cyberpunk dark theme
2026-09-25 feat(firmware): first diagnostic firmware v1.3 - LovyanGFX console, sensor suite & orange snake matrix
2026-09-29 feat(firmware): ISD-Core Coding start - Retro-modern amber watchface and lever pin remapping
    - Created zero-flicker double-buffered Watchface in PSRAM with TVA / Flipper Zero amber-orange palette
    - Dual-core FreeRTOS architecture: Core 0 sensor/input task and Core 1 UI rendering loop
    - Muted buzzer and honest telemetry (-- for unmeasured sensors)
    - Mirrored LEVER_LEFT (GPIO 16) and LEVER_RIGHT (GPIO 14) for 180-deg switch orientation
    - Documented U16 hardware errata and assembly notes in ISD-PCB/README.md for v1.4 revision
    [LeverTest.ino, SensorState.h, Watchface.h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]
2026-09-29 feat(firmware): ISD-Core v0p1 - Core OS baseline with fluid 60FPS UI & sensor telemetry
    - UI/UX: 3-panel horizontal carousel (Notifications <-> Home <-> Quickpanel) with 150ms cubic ease-out slide animations
    - Display: Boosted SPI bus clock to 40 MHz with LovyanGFX PSRAM double-buffering
    - Header: Locked 'ISD-Core // ' static prefix, dynamic clipped page title slot, and rock-solid live battery readout
    - Power: Robust MAX17048 fuel gauge polling with direct I2C fallback, SOC bounds clamping, and BQ25170 active-LOW /PG USB detection
    - Bootloader: Cyberpunk/TVA terminal startup sequence with animated rotating ASCII batons and hardware diagnostics
    - Architecture: Refactored HardwareHAL to HAL, d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
2026-09-30 release(ISD-Core): v0p2 - Multipurpose compass reticle, Android-style Quickpanel, and navigation overhaul
    - Home: Expanded reticle to R=40 with rotating W-E compass axis, North rim tick, 2D gyro spirit level, and live ambient temperature
    - Quickpanel: Replaced raw text telemetry with 6 Android-style squircle quick action tiles (Settings, HRM, Eco, Display, Silent, Shutdown) with custom vector icons and heartbeat animation
    - Navigation: Separated lever push (enter/select/toggle) from side button (back/home) to prevent accidental exits to Home
    - Sensors: Enabled BNO085 SH2_ROTATION_VECTOR for 9-DOF fusion, fixed BME680 FORCED_MODE getData capture, and calibrated compass rotation sign
    - Display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
    [DisplayConfig.h, HAL.cpp, SensorState.h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]
2026-10-01 release(ISD-Core): v0p25 - Quickpanel Brightness dial, Power menu (Standby/Reboot), and Hardware notes
    - Quickpanel Brightness Menu (Tile 1):
    * Added dedicated circular dial overlay with real-time hardware PWM adjustment.
    * Hold-to-repeat lever acceleration: single click for 5% step, hold >350ms repeats at 80ms.
    * Ergonomics: Left lever increases brightness, Right lever decreases.
    * Stripped debug labels (PWM/Lumens) in favor of sleek amber avionics dial.
    - Quickpanel Power Menu (Tile 5):
    * Integrated multi-option power card interface:
    - STANDBY: Instant display-off sleep state with immediate wake on any key or USB plug-in.
    - SHUTDOWN: Deep sleep entry temporarily stubbed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
    [DisplayConfig.h, Watchface.h, main.cpp]
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2026-10-02 release(ISD-Core): v0p3 - 3D Cover Flow App Menu, Tactical Charge gesture, and High-Speed Staged Bootloader
    - App Menu (AppMenu.h):
    * Interactive 3D cover flow launcher with perspective projection (Z-depth scaling, parallax).
    * 6 vector card decks: Vitals, Environment, Clock, Device, Tools, Settings.
    * Symmetrical top and bottom cradle trays with 10px outer gap and 22px card clearance.
    * Zero-copy PSRAM canvas sharing with Watchface.
    - Tactical Compass Charge (Watchface.h):
    * Hold LEVER_PUSH for 1.2s to enter App Menu with circular arc on compass dial rim.
    * Instant, solid entrance transition with ~75ms hardware lag pause.
    - Staged Dual-Core Background Bootloader (HAL.cpp, main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
    [AppMenu.h, DisplayConfig.h, HAL.cpp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]
2026-10-02 perf(display): set SPI write clock to 40 MHz for optimal balance of speed and signal margin
2026-10-02 fix(input): zero-latency hardware interrupts, non-blocking UI loop, and architecture doc update
    [AppMenu.h, main.cpp]
2026-10-02 fix(input): eliminate lever release chatter and tune hold repeat to prevent double stepping
    [main.cpp]
2026-10-02 fix(imu): align compass gyro bubble axes with 90-degree rotated display orientation
    [Watchface.h]
2026-10-04 release(ISD-Core): v0p31 - Tools Deck with NX-Uplink Companion Bridge and 2D Spirit Level
    - Created modular apps hierarchy under src/apps/ (clock, device, enviroment, settings, tools, vitals)
    - Added AppTools with dual-tab interface: NX-Uplink Ground Station bridge and 2D Digital Spirit Bubble Level
    - Aligned 2D Spirit Level coordinate math with 90-degree rotated display frame (tft.setRotation(3))
    - Implemented relative zero-calibration horizon on lever push with lock indicator and degree readouts
    - Added NX-Uplink Companion Bridge with dormant telemetry by default and 7 NeoPixel matrix patterns
    - Replaced blocking tone() calls with safe HAL::buzzPip() micro-ticks to prevent LEDC timer colli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
    [AppMenu.h, AppTools.h, HAL.cpp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]
2026-10-05 feat(vitals): implement AppVitals with calibrated 15s scan, live PPG wave, and MSF stress
2026-10-05 fix(vitals): drain MAX30105 FIFO and implement dynamic AC baseline filter with AGC for real PPG pulse wave
    [AppVitals.h]
2026-10-05 release(ISD-Core): v0p35 - Tactical Biometric HUD, Discrete Pulsing Heart, and Silent Mode Muting
    - Redesigned AppVitals dashboard into a Tactical Biometric HUD with blueprint schematic leader lines
    - Implemented discrete 2-state alternating pulsing heart beating at measured BPM (amber filled) and static wireframe in standby
    - Added asymmetric HUD leader callouts: SpO2 pinned to top-left wing crest and Stress anchored in mid-low core/septum
    - Added background P-Q-R-S-T ECG rhythm waveform sweeping across the oscilloscope baseline at measured heart rate
    - Formatted Stress metrics to percentage throughout Vitals dashboard and scan results
    - Restored proven MAX30105 optical configuration with d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
    [AppVitals.h, HAL.cpp, Watchface.h]
2026-10-05 release(ISD-Core): v0p37 - Settings App, Quickpanel Integration, Wrist Cover Sleep, and NX-MSF Architecture
    - Settings App (AppSettings.h):
    * Clean 4-item scrollable stack panel with smooth scrolling window and minimalist scrollbar.
    * DISPLAY category: Interactive circular Brightness dial, Auto-Dimming curve, Tilt-to-Wake sensitivity profiles, 360-degree circular Timeout dial (up to 300s / Never), and Wrist Cover sleep toggle.
    * Categories for NOTIFICATIONS, POWER SAVE, BUZZER, and NX-AIS.
    - Quickpanel & Navigation (Watchface.h, main.cpp):
    * 1-push direct launch from Tile 0 into Settings.
    * Direct return to Home Watchface upon exiting Settings when opened from Quick Panel.
    * Rest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
    [AppSettings.h, AppVitals.h, HAL.cpp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]
2026-10-07 release(ISD-Core): v0p4 - Settings deck, smoothstep backlight fade, NAND storage persistence, and manual/readme rework
    [AppSettings.h, HAL.cpp, StorageManager.cpp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]
2026-10-07 release(ISD-Core): v0p41 - Environment Deck with Real-Time 3D Rotating Earth and 5-Card Vertical Hierarchy
    - Created AppEnvironment (ISD-Core/src/apps/enviroment/AppEnvironment.h) with 5-card vertical scrollable hierarchy
    - Implemented Real-Time 3D Vector Earth Engine on Core 1 at 60 FPS with 23.4° axial tilt, rotating meridians, and vector continents
    - Added blueprint tactical leader lines pinning Earth to 4 corner telemetry pods (Atmosphere, Climate, Air Quality, Photometrics)
    - Added Card 1: Atmosphere & Altitude deep-dive with vector mountain peak, live elevation, QNH zero calibration, and 16-bar isobaric sparkline
    - Added Card 2: Climate deep-dive with vector mercury thermometer tube,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
2026-10-08 fix(enviroment): vertical slide easing, tactical scrollbar, BME690 Air Quality fusion, and UI declutter
    - AppEnvironment Deck:
    * Upgraded to 6-card vertical hierarchy (Master HUD -> Weather -> Atmosphere -> Climate -> Air Quality -> Photometrics).
    * Added smooth spring-damper vertical sliding transitions with viewport clipping to prevent edge bleed.
    * Replaced bottom footer bar with tactical right-edge scrollbar with illuminated position thumb and discrete card notches.
    * Added dedicated Weather card with crisp vector glyphs, 3-hour barometric tendency, and dew point fog sentinel.
    * Overhauled Air Quality card with hero IAQ score, 16-segment purity bar, quad telemetry pods (eCO2, b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
    [AppEnvironment.h, NX-MSF.h, main.cpp]
2026-10-13 release(ISD-Core): v0p42 - Vitals PPG physiological waveform, CRT sweep oscilloscope, and display sleep safeguards
    - Correct optical polarity so arterial systolic pulses surge upward with natural physiological contour
    - Decouple DC baseline tracker (gamma = 0.006) to ignore cardiac cycles while absorbing finger settling drift
    - Cascaded 2-pole low-pass filter (0.18/0.18 at 100 Hz) to eliminate 50/60 Hz ambient flicker and ADC noise
    - Implement CRT beam sweep oscilloscope animation with phosphor trail and 12px leading erase gap
    - Dual-threshold contact hysteresis to eliminate initial placement flicker
    - Pause display inactivity sleep timeout during active vitals measurement sessions
    - Shut do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
2026-10-19 feat(pcb): v1.4 schematic and layout updates for 4-bit SDMMC, direct display SPI, and button pullups
2026-10-20 hw(v1.4): progress on TODO - 4-bit MicroSD, direct display bus, BNO085 & EP vias (DRC 0 errors)
    - Implemented 4-bit SDMMC MicroSD slot (Molex 105162-0001) on right edge with outward insertion
    - Routed direct 3.3V display SPI bus (TE 1-2328702-0) with C29 100nF decoupling
    - Centered BNO085 9-DOF IMU cluster with local ground star and 32.768kHz crystal
    - Rerouted NeoPixel PWR_NPM high-side power gate signal
    - Updated thermal EP pad via sizes on BQ25170 and MAX17048 for standard JLCPCB fabrication
    - Achieved 0 DRC errors, 0 unconnected nets, and 100% schematic parity
    - Updated HW-TODO and SW-TODO for v1.3/v1.4 pinout target abstraction
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2026-10-21 hw(v1.4): bq25170 thermal optimization, usb-c plating, battery pad stitching, and npm decoupling
2026-10-22 hw(v1.4): complete overall layout plating, esp32 thermal pad, npm silkscreen, and docs
2026-10-23 feat(v1.4): finalize v1.4 PCB, KiCad libraries, production guide, and firmware target selector
2026-10-23 docs: document v1.4 vs v1.3 hardware revision differences and 16MHz TXB0106 SPI restriction
2026-10-26 feat(v1.4): update PCB layout with BNO085 3V3 polygon, RTC cap fix, BQ25170 thermal relief, and silkscreen artwork
2026-10-30 hw(v1p4): add RTC backup supercap C27, tactile buttons, USBLC6 footprint adjustments, and cyberpunk silkscreens
2026-11-03 hw(v1p4): migrate to project-local KiCad libraries, add TS18 and supercap footprints, and update schematics
2026-11-03 feat(hw): finalize NX-ISD v1.4 production milestone, datasheets & renders
    - Finalize hardware revision v1.4 with Seiko CPH3225A (11mF) supercapacitor RTC backup, direct 40MHz 3.3V SPI display bus, and 4-bit SDMMC MicroSD storage
    - Update and route Net-(U12-VBACKUP) and link CPH3225A.step 3D model
    - Update components: DMP3130L-7 P-MOSFETs, ZXMN3B14FTA N-MOSFETs, and PCA9306 level translator
    - Refresh manufacturing package (NX-ISD_v1p4.zip, bom.csv, positions.csv, netlist.ipc)
    - Generate v1.4 Interactive HTML BOM (NX-ISD_v1p4_IBOM.html) and 5-page schematic PDF
    - Add 4x KiCad raytraced twilight gradient renders and update READMEs
    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
2026-11-05 fix(hw): build target v1.3 with button internal pullup, lever orientation, and mirror color byte-swap
2026-11-05 fix(mirror): cancel pending after timers on close, bind global keys, and flush stdin/serial
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
